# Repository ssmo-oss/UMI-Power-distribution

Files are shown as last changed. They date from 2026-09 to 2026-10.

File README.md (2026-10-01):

# UMI Power Distribution

Three separate boards distribute a 12 V supply to the UMI system. **D6 is the current prototype revision. It has not been physically qualified or approved for production.**

## Latest mechanical candidate — D8-2L MAIN

The owner supplied [10052938_AA-UMI POWER PCB OUTLINE V3.dxf](design/D8-2L/source/10052938_AA-UMI%20POWER%20PCB%20OUTLINE%20V3.dxf) for MAIN only on 2026-10-01. [D8-2L](design/D8-2L/README.md) and [D8-2L-FASTON](design/D8-2L-FASTON/README.md) apply the updated contour and six 3.5 mm mounting-hole centers. The FASTON assembly was corrected on 2026-10-01: the right-angle tabs now point toward board top, their through-board pins align with the two-hole footprints, and the reverse-side fuseholder envelopes align with their pad patterns. The FASTON board passes DRC with zero violations, unconnected items, and schematic-parity issues. Its [STEP assembly](design/D8-2L-FASTON/MAIN_POWER/MAIN_POWER_D8_FASTON.step) and [3D preview](design/D8-2L-FASTON/MAIN_POWER/review/MAIN_POWER_D8_FASTON_3D.png) are current. The terminal and fuseholder solids are dimension-based simplified CAD envelopes, not exact vendor models; TE lists the 63951-4 as a 6.35 mm-wide right-angle tab with 1.4 mm PCB holes and an 8.89 mm profile height ([TE product page](https://www.te.com/en/product-63951-4.html)). Raw copper is excluded and solder-mask surfaces are included in the STEP. The direct-solder variant was left untouched. TE recommends 1.57 mm PCB thickness, while the candidate remains 1.2 mm pending confirmation. D7-2L remains unchanged.

**D8 is not ready for manufacturing.** KiCad 10.0.6 DRC reports 0 violations, 0 unconnected items, and 0 schematic-parity issues for both MAIN variants. Complete electrical, thermal, and enclosure review before release. See the saved [D8 DRC report](design/D8-2L/MAIN_POWER/verification/D8_DRC_DIRECT_SOLDER.json), [board preview](design/D8-2L/MAIN_POWER/review/MAIN_POWER_D8.svg), and [visual STEP assembly](design/D8-2L/MAIN_POWER/MAIN_POWER_D8.step). The direct-solder STEP includes the board and all 10 component envelopes. The FASTON variant includes the board and all 11 component envelopes. Input leads and mating cables are omitted.

| Board | Function | PCB size / thickness | Planned assembly |
|---|---|---|---|
| MAIN_POWER | Fused 12 V distribution | 68 Ãƒâ€” 100.264 mm / 1.2 mm | User fits all 11 through-hole parts |
| POE_POWER | 12 V to nominal 53.5 V, 1.31 A switch supply | 106 Ãƒâ€” 100 mm / 1.2 mm | JLC SMT, user fits 3 through-hole parts |
| USB_POWER | Two charge-only USB-A ports, 3 A electrical design target each | 80 Ãƒâ€” 50 mm / 1.6 mm | JLC SMT, user fits 3 through-hole parts |

All boards use four copper layers, 2 oz outer / 1 oz inner. Planned batch: **10 of each board**. Enclosure ambient limit: **40 Ã‚Â°C**.

## Mechanical update required

On 2026-09-28, the project owner confirmed that the D6 board outlines were out of date. D8-2L now applies the supplied replacement outline to MAIN only. D6 manufacturing files and STEP models remain historical and on hold; POE and USB replacement mechanics are still not supplied. Do not treat D8 as released for manufacture.

## Latest MAIN option: D7-2L

[Two-layer MAIN prototype](design/D7-2L/README.md) preserves the user layout and uses 2 oz copper on each side at 1.2 mm thickness. Native ERC/DRC/parity checks pass. The four-layer D6L1 option remains preserved. Full shared-path voltage-drop/thermal qualification and mechanical confirmation remain pending. PoE and USB are unchanged. [Download D7-2L](packages/UMI_MAIN_POWER_D7_2L_PROTOTYPE.zip).

## Preserved four-layer MAIN layout: D6L1

The user rearranged MAIN components on 2026-09-29. [D6L1](design/D6L1/README.md) restores the branch connections and fills while preserving those placements and graphics. Native DRC/parity: zero violations and zero unconnected items. [Open the current MAIN project](design/D6L1/MAIN_POWER/MAIN_POWER.kicad_pro). Older MAIN Gerbers and STEP files are now stale for this layout. Manufacturing remains on hold.

## MAIN schematic redraw: D6S1

The MAIN schematic was redrawn on 2026-09-29 with explicit branch wiring. [Open the D6S1 project](design/D6S1/MAIN_POWER/MAIN_POWER.kicad_pro), [view the schematic PDF](design/D6S1/MAIN_POWER/review/MAIN_POWER_schematic.pdf), or read the [revision notes](design/D6S1/README.md). The physical MAIN PCB is unchanged from D6; PoE and USB remain D6. The outline hold still applies. For another computer or agent, read [START_HERE.md](START_HERE.md).

## Start here

- [D6 design and manufacturing overview](design/D6/README.md)
- KiCad 10 projects: [MAIN](design/D6/MAIN_POWER/MAIN_POWER.kicad_pro), [POE](design/D6/POE_POWER/POE_POWER.kicad_pro), [USB](design/D6/USB_POWER/USB_POWER.kicad_pro). Each project includes its PCB, schematic and local libraries.
- [Complete D6 prototype package](packages/UMI_THREE_BOARD_DESIGN_D6_PROTOTYPE.zip)
- [Combined component sourcing spreadsheet](design/D6/UMI_COMPONENT_SOURCING.xlsx) and [CSV](design/D6/UMI_COMPONENT_SOURCING.csv): one list for SMT, manual parts and harness parts.
- [Layout review](design/D6/LAYOUT_REVIEW.html): download/clone and open locally to view linked fabrication and assembly drawings.
- [Simplified STEP models](mechanical/D6/README.md) and [STEP ZIP](packages/UMI_D6_STEP.zip).
- [Engineering calculations and bring-up procedure](design/D6/ENGINEERING_AND_TEST_NOTES.md), [fabrication requirements](design/D6/FABRICATION_NOTES.md), [manual assembly](design/D6/MANUAL_ASSEMBLY.md).
- [Open items and project decisions](docs/PROJECT_HANDOFF.md).

## Configuration

The PoE switch and SENSING GMSL board are **alternative configurations; never connect both loads** under this power budget. No hardware interlock enforces this. The larger configuration is approximately 174 W / 14.5 A at 12 V under the documented assumptions; retain the 20 A input-path design/test margin.

MAIN J1 is the 12 V input. MAIN J2/J3/J4/J5/J6 feed Jetson/GMSL/fan/USB/POE respectively. All two-pin 12 V headers use pin 1 positive, pin 2 ground. POE J6 supplies 53.5 V: pin 1 positive, pin 2 unused, pin 3 ground. Consult the project pin schedules before making cables.

## Verification and limitations

The supplied D6 records report zero KiCad DRC/ERC violations, zero unconnected items and zero schematic-parity issues. Gerber/drill/placement checks and source hashes are included in each board's verification folder. These are file checks, not hardware measurements. [TEST_RECORD.csv](design/D6/TEST_RECORD.csv) records physical tests as unperformed.

Supplier acceptance of copper thickness, selective filled/capped vias and the PoE inductor fixture is pending. Stock observations are historical snapshots, not reservations. The output fuse is obsolete and its observed stock only supports a batch sourcing plan. No order or payment has been placed.

STEP files preserve board outlines and holes and add simplified component proxies. Component heights are estimates: do not use them for final enclosure-clearance signoff. Missing KiCad 3D bodies do not remove a component from the assembly BOM; check the SMT BOM/CPL and separately fitted parts.

## Repository contents

`design/D6/` is the editable current design and manufacturing package. `mechanical/D6/` contains six STEP models and their verification/assumptions. `packages/` contains the original current delivery ZIPs. `archive/` contains superseded snapshots, including the original revC input. `docs/historical-reviews/` preserves prior engineering reviews; they can contain findings later resolved by D6. `tools/legacy/` contains development scripts, with execution caveats in its README.

Transferred on 2026-09-28. See [transfer record](docs/TRANSFER_RECORD.md) and [SHA256 manifest](TRANSFER_SHA256SUMS.txt). No license has been selected; this import does not assign new licensing terms to project files or third-party library assets.

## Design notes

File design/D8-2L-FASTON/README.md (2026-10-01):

# D8 MAIN — FASTON 250 input alternative

This separate MAIN-board variant is based on D8-2L. It uses the owner-supplied V3 outline and keeps the fuse and connector arrangement, routing, copper zones, and output connectors. J1 is changed to two TE Connectivity 63951-4 FASTON 250 PCB tabs, each with two plated mounting holes (four holes total) on the tab axis, with both blade axes pointing toward the board's top edge in the top view. The flat solder-pad version remains in `design/D8-2L/MAIN_POWER/`.

The FASTON pair is centered on the board's 139.6 mm X centerline. Its footprint courtyard sits 2.5 mm in from the straight lower board edge.

## Input connector

- PCB terminals: TE Connectivity **63951-4**, quantity 2; FASTON 250, 6.35 × 0.8 mm tabs. Each tab uses two 1.4 mm plated holes at 5.08 mm pitch.
- Mating 10 AWG receptacle option: TE Connectivity **62998-2**, quantity 2, for 10–8 AWG wire. The mating receptacles and wires are off-board, not fitted to the PCB.
- TE lists 8.89 mm profile height from PCB for 63951-4, leaving 1.11 mm nominal margin under 10 mm. The same product page recommends 1.57 mm board thickness. This variant still uses 1.2 mm board thickness; confirm fit/retention with TE or update the stackup before ordering.
- The 10 mm clearance also needs checking with the selected female receptacles and wires installed. The TE 63951-4 summary does not state a current rating, so qualify the complete connection thermally at the intended maximum current. Terminals have no wire-insulation support; add harness strain relief.

## Files

- `MAIN_POWER/MAIN_POWER.kicad_pcb` — updated PCB; copper zones refilled.
- `MAIN_POWER/MAIN_POWER.kicad_sch` — J1 value, footprint, MPN and BOM status updated.
- `MAIN_POWER/UMI_D2.pretty/Input_FASTON_250_PAIR.kicad_mod` — pair footprint with four 1.4 mm plated holes (two per tab, 5.08 mm pitch) and top-view tab orientation shown on F.Fab.
- `MAIN_POWER/verification/D8_FASTON_DRC.json` — KiCad 10.0.6 check after V3 outline and zone refill: 0 rule violations, 0 unconnected items, and 0 schematic-parity warnings. The six DXF-derived 3.5 mm mounting holes have matching schematic records.
- `MAIN_POWER/review/MAIN_POWER_D8_FASTON.svg` — top-view preview.
- `MAIN_POWER/MAIN_POWER_D8_FASTON.step` — refreshed 2026-10-01; board, solder-mask surfaces, and all 11 modeled components (J1–J6 and F1–F5); raw tracks, pads, and zones are excluded.
- `MAIN_POWER/review/MAIN_POWER_D8_FASTON_3D.png` — 3D assembly preview showing the input blades extending toward the board top and the fuse-holder envelopes aligned over their backside pad patterns.

The STEP uses dimensioned envelope models for the TE 63951-4 terminal pair, the JST VH output headers, and the Littelfuse FLR fuse holders. They are simplified solid envelopes, not detailed vendor CAD. The FASTON pair uses a 6.35 × 0.8 mm blade, 8.89 mm profile height, four tails aligned to the four 1.4 mm holes, and a right-angle bend; the two blades point toward the board top, parallel to the fuse row. The B.Cu fuseholder envelopes are mirrored to match the pad patterns. TE recommends a 1.57 mm board; this candidate is still 1.2 mm. Confirm the terminal fit, 10 mm enclosure clearance, current capacity, and mating connector with exact vendor CAD before release. This remains a prototype layout candidate, not a manufacturing release.

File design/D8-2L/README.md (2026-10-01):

# MAIN D8-2L — mechanical-outline adaptation candidate

Created 2026-09-30 from the D7-2L two-layer MAIN board after the owner supplied the corrected mechanical DXF. The editable KiCad project is `MAIN_POWER/MAIN_POWER.kicad_pro`. The D7-2L source project remains unchanged.

## Mechanical input

Latest source: `source/10052938_AA-UMI POWER PCB OUTLINE V3.dxf` (SHA-256 `10ADAB7113C99765CFB8C23128E78733F5ECCF2D0ECE246013FCFE98C07AA364`). DXF `$INSUNITS` is millimetres. V3 has 32 unique contour segments, bounds 121.8 × 60.5 mm, and six 3.5 mm diameter mounting holes. Compared with V2_1 it moves the upper inner pair from DXF X=±19 mm to ±16 mm and revises the contour. V3 is applied to both D8 MAIN options without scaling; earlier outline files are retained for history.

The DXF contour origin was mapped to the existing MAIN project coordinates as `x = 139.6 mm + DXF X` and `y = 97.131981 mm − DXF Y`. This keeps the board in the D7 project coordinate area. The DXF is mechanical geometry, not a source of electrical or assembly instructions.

## Layout adaptation

D8 starts from the D7-2L electrical design, rotates the component layout to fit the landscape profile, replaces the old four mounting holes with the six DXF holes, and refills the two copper zones. After the owner adjusted placement, the five fuse centers were aligned on one row, the five output connector centers on another, and each fuse/connector pair was centered on the same vertical line. The five fuse-holder footprints are on B.Cu (underside); all other components stay on F.Cu (top). All board text is on F.SilkS, with the fuse ratings and connector names centered on their corresponding columns. F3/J4 was shifted 1.5 mm left to clear mounting hole H2. The MAIN copper was rerouted: five fused outputs, a shared 12 V input bus routed around the DXF notch and mounting holes, and ground zones. On 2026-09-30, J1 was changed from the oversized Phoenix screw terminal to two 8 × 8 mm flat top-copper solder pads, labelled +12V and GND, sized for 10 AWG leads. Sixteen 1.0/0.5 mm ground stitching vias tie the GND pad to the B.Cu return plane. Lay the leads along the board and strain-relieve them to the enclosure or harness; do not use the solder joints as cable support. J1 has no connector part number. The circuit and other components are unchanged. `tools/create_d8_main.py` records the initial conversion from the original D7-2L board and DXF.

## Current validation and limits

KiCad 10.0.6 DRC with zone refill reports 0 violations, 0 unconnected items, and 0 schematic-parity issues. The board is an editable routing candidate, not released for manufacture. Electrical voltage-drop, thermal and enclosure validation remain outstanding; in particular, the 10 AWG input connection and copper path still need thermal qualification at the maximum intended current.

The top-view review is `MAIN_POWER/review/MAIN_POWER_D8.svg`; the underside view is `MAIN_POWER/review/MAIN_POWER_D8_bottom.svg`. The DRC data is `MAIN_POWER/verification/D8_DRC.json`.

## STEP assembly — 2026-10-01

`MAIN_POWER/MAIN_POWER_D8.step` includes the board, solder-mask surfaces, and all 10 modeled components (J2–J6 and F1–F5). J1 is the two flat input pads; input wires are not modeled. The JST VH and Littelfuse FLR bodies use project-local dimensioned envelope STEP models because those vendor models are absent from the installed KiCad model library. These simplified volumes preserve the specified connector/fuse identities and overall envelopes, but omit detail; use the STEP for arrangement and preliminary clearance review, then verify with vendor CAD before release. Raw tracks, pads, and zones are excluded from STEP export. Run `tools/export_d8_main_steps.ps1` to regenerate both D8 MAIN STEP assemblies.

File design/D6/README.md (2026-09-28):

# UMI D6 — sourcing and manufacturing corrections

D6 retains the three-board architecture and resolves the known part-sourcing and file-format issues that can be handled before fabrication. **Ready for prototype manufacturing review, not physically qualified for production.**

## Completed

- Replaced the preorder snubber resistor with stocked **Yageo RC2010JK-077R5L / C4169838**. Resistance, tolerance, power rating and footprint are unchanged. Its pulse/thermal behaviour still requires the same prototype measurement as the original part.
- Found exact loose-part sources for all thirteen manual component types. The Phoenix input connector no longer needs JLC preorder. The 80 V fuse has enough observed distributor stock for twenty pieces, including ten spares. It is obsolete; this is a batch solution, not guaranteed long-term availability.
- Defined the supply route: JLC assembles SMT; the user fits separately purchased connectors, holders, inserts and harness components. All remain on **one combined spreadsheet** with purchase links and quantities. Repeated manual MPNs are bought once; later duplicate rows show zero purchase quantity.
- Corrected MAIN/POE inner-layer stackup identities, widened five POE traces from 0.15 to 0.16 mm, enlarged MAIN's small visible labels, and encoded selective via filling/capping in the PCB sources and coordinate schedules.
- Refilled and re-exported all boards. Final KiCad DRC/ERC reports pass with zero reported violations, zero unconnected items and zero schematic-parity issues. Independent Gerber/drill/placement audits and source-hash checks are included.

## Files and order scope

Open **LAYOUT_REVIEW.html** for actual fabrication previews and schematic/assembly drawings. Order ten of each:

| Board | Outline | Thickness | Copper | Assembly |
|---|---|---|---|---|
| MAIN_POWER | 68 × 100.264 mm | 1.2 mm | 4 layers, 2 oz outer / 1 oz inner | Bare board, 11 manual parts |
| POE_POWER | 106 × 100 mm | 1.2 mm | Same | 53 SMT + 3 manual parts |
| USB_POWER | 80 × 50 mm | 1.6 mm | Same | 31 SMT + 3 manual parts |

Use the per-board Gerber ZIP, SMT BOM and normalized CPL. MAIN has no SMT operation. Read FABRICATION_NOTES.md: POE/USB need selective epoxy-filled, copper-capped vias; POE's 0.635 mm vias remain ordinary. Include the POE inductor assembly fixture. The source copper stackup is explicit; do not accept a silent change to 0.5 oz inner copper.

## Electrical configuration

MAIN J1 takes 12 V. J2 supplies Jetson, J3 GMSL, J4 fan, J5 USB J1 and J6 POE J1. All 12 V two-pin headers use pin 1 positive, pin 2 ground. POE J6 is the 53.5 V output: pin 1 positive, pin 2 empty, pin 3 ground.

Use **PoE or GMSL, never both**. There is no electronic interlock. The larger configuration is approximately **174 W / 14.5 A at 12 V**, using the documented allowances and assumed converter efficiency; retain 20 A input-path design/test margin. MAIN retains F1 Jetson 7.5 A, F2 GMSL 7.5 A, F3 fan 1 A, F4 USB 5 A and F5 PoE feed 10 A. POE retains F6 3 A / 80 V. F5 protects the interboard cable at its source. Jetson's 7.5 A is provisional protection, not expected draw; verify startup, temperature and wire protection before changing it.

## Remaining external steps

1. **Manufacturer acceptance and purchasing:** the exact copper/thickness/selective-fill combination and inductor fixture need an accepted quote. QUOTE_REQUEST.md is prepared but unsent. Approve supplier placement/polarity previews and final attrition quantities. C1 requires fourteen pieces including the reported four-piece attrition, against fifteen observed; L1 requires ten against seventeen observed. Inventory is not reserved. Other SMT allowances in the spreadsheet are conservative planning quantities where exact order-page arithmetic was unavailable.
2. **Physical prototype tests:** no assembled hardware was available to test. Thermal rise at 40 °C, stability, snubber pulses, eFuse fault transients, USB load steps and real-device compatibility cannot be established from DRC. TEST_RECORD.csv gives the pending measurements; ENGINEERING_AND_TEST_NOTES.md gives the procedure. All physical results are explicitly unperformed.
3. **Installation details:** final cable lengths, device-end plugs, weakest wire/pigtail ratings, input cable protection and the exact USB-powered device model remain to be confirmed before system integration. The interim interboard harness basis is AWG16, at most 1 m one-way; this is a documented assumption, not a measured installation.

No supplier message, order, reservation, payment or external design upload has been made. D5 is preserved. SHA256SUMS.txt identifies this package.

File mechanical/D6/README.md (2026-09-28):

# UMI D6 simplified STEP models

Six files: BARE and SIMPLIFIED for MAIN_POWER, POE_POWER and USB_POWER. Units are millimetres.

BARE files retain the native KiCad board outline, rounded corners, mounting and component holes. Small via holes are intentionally omitted. The native board-only export omits outer conductor/mask thickness; its Z dimension was scaled to the specified finished 1.2 mm MAIN/POE and 1.6 mm USB thickness. X/Y geometry is unchanged. No tracks, pads, copper zones or text are modelled.

SIMPLIFIED files add a rectangular body proxy for every board-mounted electrical component, including the through-hole parts intended for manual assembly. They also show simple fuse-insert proxies. Component X/Y outlines derive from the saved footprint fabrication graphics and placements. Heights are approximate visual allowances, not verified manufacturer maximum dimensions. Leads, solder joints, connector internals, mating plugs, cables and standoffs are omitted. These models are useful for arrangement and visualisation, but NOT final enclosure-clearance signoff. Consult COMPONENT_PROXY_DIMENSIONS.json for each assumption.

Origin: each board's Gerber/drill origin. X points right, Y points upward when viewed from the component side, Z points upward. Bare PCB bottom is Z=0; component bodies start at the finished PCB top. All boards are exported separately; their relative installation positions are not defined.

Every file was reimported with Open CASCADE and checked for valid solid geometry and expected solid count. Bare PCB dimensions were checked against the design. MAIN: 68 × 100.263962 × 1.2 mm; POE: 106 × 100 × 1.2 mm; USB: 80 × 50 × 1.6 mm. The original KiCad/manufacturing files were not modified.

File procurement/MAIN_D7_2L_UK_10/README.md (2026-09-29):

# MAIN D7-2L purchasing and fabrication package

Prepared 29 September 2026 for **10 MAIN boards only**, retaining the latest layout and 3 mm FAN branch tracks. The PCB and schematic were not modified for this task.

## What to use

- `MAIN_D7_2L_UK_PARTS_10.xlsx`: one combined purchasing list with exact part numbers, quantities, spares, observed GBP prices, stock and source links.
- `DIGIKEY_BASKET_IMPORT.csv`: nine order lines for DigiKey UK. Map the three columns to Part Number, Quantity and Customer Reference in the basket file importer.
- `DIGIKEY_BULK_ADD.txt`: same nine lines without headers for the basket's Bulk Add text box.
- `JLCPCB_MAIN_D7_2L_GERBERS.zip`: fabrication upload containing seven Gerbers, two drill files and the Gerber job file. Use the separate order settings text file.
- `MAIN_BOARD_BOM_MANUAL_ASSEMBLY.csv` and `MAIN_WIRING_PIN_SCHEDULE.csv`: reference assembly and wiring information. These are not a JLCPCB SMT assembly submission.

## Purchase quantities and cost

The list supplies all 11 soldered components per board, five removable fuse inserts and five MAIN-end two-pin mating housings with ten contacts per board. Quantities include a 20% spares allowance, rounded to supplier order multiples. Contacts are **200 individual contacts (two strips of 100)**, not 200 packs. Required without spares: 10 input blocks, 50 holders, 50 PCB headers, 20 x 7.5 A fuses, 10 each of 1 A / 5 A / 10 A fuses, 50 housings and 100 contacts.

Observed parts estimate: **GBP 259.48 excluding VAT, delivery and PCB fabrication**. Prices come from displayed DigiKey UK tiers; web search pages may be cached. Holder and 100-contact-strip availability were also checked in the browser. Stock is not reserved and all prices need refresh at checkout. Changing spreadsheet quantities recalculates quantities and totals using the recorded unit prices; it does not retrieve new tier prices. CSV/TXT are the fixed ten-board snapshot and do not auto-update with spreadsheet edits.

Both online carts were subsequently created successfully. See [ONLINE_CART_STATUS.md](ONLINE_CART_STATUS.md) for basket links, live prices and saved cart references. No payment or order submission occurred.

## Assembly and harness details

- J1 Phoenix 1709681 is a fixed screw-clamp PCB terminal block. The PSU wires enter it directly; it does not take a mating plug.
- J2–J6 use JST B2P-VH(LF)(SN), cataloged by DigiKey as B2P-VH. Their matching cable housings are natural-colour VHR-2N with SVH-41T-P1.1 female contacts. Natural housing colour replaces the earlier black VHR-2N-BK selection; the mating family and circuit are unchanged.
- Contacts accept 16–20 AWG wire; use the specified contact/wire tooling and validate finished crimps. Do not crimp a thinner fan pigtail into an oversized contact. Adapt the harness with appropriate terminals/splices once actual wire gauges are known.
- Pin 1 on each output is its fused +12 V; pin 2 is ground. Verify physical pin numbering before terminating each cable.
- Fuse mapping: F1 Jetson 7.5 A; F2 GMSL 7.5 A; F3 fan 1 A; F4 USB-board feed 5 A; F5 PoE-board 12 V feed 10 A. These are the existing design values, not newly proven load ratings. All inserts in this MAIN list are 32 VDC-rated ATO fuses. Do not use them on the 53.5 V PoE output.
- PoE and GMSL are alternative system configurations, never simultaneous loads. Both physical branches are populated in this purchasing list.
- Wire lengths, device-end plugs, PSU-end terminations, enclosure mounting hardware and crimp tooling are not included because their installation details are unspecified. The mating connector list covers the MAIN end only.

JST family reference: https://www.jst-mfg.com/product/pdf/eng/eVH.pdf

## Fabrication status

Order settings: 10 bare FR-4 boards, two copper layers, 2 oz each side, 1.2 mm finished thickness, ENIG, green solder mask, white legend. No stencil or assembly service is needed for this all-through-hole MAIN design. Exact nominal outline is 68 x 100.263962 mm.

The saved native DRC report has zero violations, zero unconnected items and zero schematic-parity findings under the project's configured checks; saved ERC has zero violations. The package audit verifies the PCB/schematic hashes against the saved two-layer audit and verifies each ZIP member against the export directory. No claim of live JLCPCB DFM approval is made.

**Existing release limits remain:** final mechanical outline/holes are unconfirmed and full-board thermal/voltage-drop testing at 40 C enclosure ambient is outstanding. This package is suitable for a fabrication quote and prototype review; it is not a production-qualified release. Do not treat clean DRC as an ampacity or mechanical-fit certificate.

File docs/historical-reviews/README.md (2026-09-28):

# Historical review notes

These notes preserve engineering rationale and earlier findings. Dates/revision labels matter: some issues were subsequently fixed. Current conclusions and outstanding work are in `../../design/D6/README.md`, the D6 verification records and `../PROJECT_HANDOFF.md`. These review snapshots do not establish current inventory or physical qualification.

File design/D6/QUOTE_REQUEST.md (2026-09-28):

# Prepared engineering quotation request — not sent

Please quote fabrication of ten each of UMI D6 MAIN_POWER, POE_POWER and USB_POWER, with top-side SMT assembly on POE and USB only. MAIN is bare-board supply; all connectors, fuse holders/inserts and cable-side parts are excluded from SMT assembly and will be user-fitted.

MAIN: 68 × 100.263962 mm, four layers, 1.2 mm finished thickness. POE: 106 × 100 mm, four layers, 1.2 mm. USB: 80 × 50 mm, four layers, 1.6 mm. All require 2 oz outer / 1 oz inner copper, ENIG, green soldermask, white silkscreen and FR-4 Tg150 or better. Please confirm the exact stackups and tolerances without changing outline, mounting holes or copper weights.

POE and USB require selective epoxy resin fill with copper capping of the vias identified in their manufacturing/VIA_TREATMENT.csv files. POE 0.254/0.35/0.40 mm vias and USB 0.25/0.30 mm vias are included; POE 0.635 mm ordinary vias and all component/mounting holes must remain open. Please confirm capability and pricing for this selective process at the specified copper/thickness combinations.

POE has 53 top SMT placements, USB 31. Use the normalized *_CPL_JLC.csv and matching BOM_JLC_DRAFT.csv. Please verify rotation/pin 1 in the placement preview, paste treatment over filled/capped pads, and support fixture requirements for Coilcraft SER2915H-103KL / C19276042. Include the required fixture in the quote. Add removable handling rails if needed rather than changing the board outlines.

Please confirm available quantities and assembly attrition for all SMT parts. Particular constraints: POE C1 C23481145, ten installed plus four catalogue attrition; POE L1 C19276042, ten installed; POE R1 C4169838, ten installed with supplier-confirmed minimum/attrition. The consolidated sourcing list contains dated observations, not reservations. State lead time, freight, any engineering exceptions and whether all parts can be supplied before committing to production.

Please return the complete engineering acceptance and quotation for review before any fabrication, assembly or purchase is authorised.

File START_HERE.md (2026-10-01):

LATEST MAIN MECHANICAL CANDIDATE (2026-10-01): both `design/D8-2L/MAIN_POWER/` (flat solder-pad input) and `design/D8-2L-FASTON/MAIN_POWER/` (two TE 63951-4 input tabs) use the owner-supplied V3 outline. Both pass KiCad 10.0.6 DRC with 0 violations, 0 unconnected items, and 0 schematic-parity issues. Matching STEP assemblies are saved in each MAIN_POWER folder. They include board/copper and mounted component volumes, with simplified proxies for connector and fuse-holder geometry. FASTON uses a dimension-based tab proxy rather than the gated manufacturer model. Confirm the terminal fit, 10 mm enclosure clearance, current capacity, and mating connector with exact vendor CAD; TE recommends a 1.57 mm board while these candidates remain 1.2 mm. Read both D8 README files before further work. The V3 update applies to MAIN only; POE and USB remain at their prior D6 mechanical revisions. D7-2L remains unchanged as the electrical baseline.

## Cart update — 29 September 2026

Ten-board MAIN D7-2L carts are now saved at JLCPCB and DigiKey. No payment/order submission. See [cart status](procurement/MAIN_D7_2L_UK_10/ONLINE_CART_STATUS.md). Earlier basket-failure notes are superseded. Mechanical and thermal holds remain.

# Resume on another computer

LATEST PROCUREMENT (2026-09-29): `procurement/MAIN_D7_2L_UK_10/` contains the MAIN-only ten-board UK purchasing list, DigiKey basket import files, matching two-layer JLCPCB Gerber ZIP and order settings. It includes the latest 3 mm FAN tracks. No online basket/order was completed; DigiKey Bulk Add returned a server error. The existing mechanical and physical-validation holds remain. For MAIN, use `design/D7-2L/MAIN_POWER/MAIN_POWER.kicad_pro`; the older D6 MAIN instructions below are historical.

NEWEST OPTION: MAIN D7-2L is the requested two-layer prototype in design/D7-2L/MAIN_POWER, preserving the D6L1 component layout. Read its README and the latest handoff entry. D6L1 remains the four-layer fallback. Neither is production-qualified.

LATEST UPDATE: MAIN layout is now D6L1 (design/D6L1/MAIN_POWER), reconnected after user placement edits; its schematic is the D6S1 redraw. Read the latest entry in docs/PROJECT_HANDOFF.md. D6/D6S1 MAIN manufacturing and STEP outputs are stale for this layout. The older state described below is superseded for MAIN PCB selection.

Repository: https://github.com/ssmo-oss/UMI-Power-distribution

Download or clone this repository on the new computer. In a desktop agent with local folder access, open the repository folder as the project. For a cloud/chat agent, connect the repository if available, or upload the downloaded files; a URL alone does not guarantee the agent can edit the repository. Authentication and KiCad installation belong to the new machine and are not included in this repository. See [OpenAI project guidance](https://learn.chatgpt.com/docs/projects).

Read README.md, docs/PROJECT_HANDOFF.md, design/D6S1/README.md and design/D6/ENGINEERING_AND_TEST_NOTES.md. The latest MAIN schematic is D6S1; its PCB is still D6. PoE and USB remain D6. The corrected outline is applied to MAIN in D8-2L. POE/USB mechanics and all manufacturing outputs remain on hold. Past checks passed but hardware tests are unperformed.

Paste this into the next agent:

> Continue the UMI power-distribution project from https://github.com/ssmo-oss/UMI-Power-distribution. Read START_HERE.md, README.md, docs/PROJECT_HANDOFF.md and design/D6S1/README.md before editing. Confirm which files you can actually access. The MAIN schematic redraw is D6S1, while its copper and the other two boards remain D6. The owner supplied a revised MAIN-only outline, now applied in design/D8-2L/MAIN_POWER. POE/USB replacement mechanics remain pending. Continue from D8 for MAIN, validate connectivity and clearance, and regenerate matching manufacturing and mechanical files only after remaining review items and mechanics are resolved. Keep one combined sourcing list, preserve the three-board architecture and PoE-or-GMSL configuration rule. Record changes and remaining issues in the repository so work can continue from any computer. Do not submit orders or claim physical qualification.

For KiCad editing, open design/D6S1/MAIN_POWER/MAIN_POWER.kicad_pro (MAIN) or the corresponding project under design/D6 for POE and USB. Local symbol and footprint libraries are included. The old development scripts under tools/legacy contain machine-specific paths and are not a turnkey build pipeline. Earlier KiCad bundled Python/CLI invocations caused application-error dialogs; do not blindly rerun those scripts. Verify the available tools on the new computer first.

This is a durable project handoff, not a transfer of the old chat transcript, open editor windows, credentials or installed plugins. Update docs/PROJECT_HANDOFF.md and push completed changes before switching computers again.

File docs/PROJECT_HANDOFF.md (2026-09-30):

## Cart update — 29 September 2026

Ten-board MAIN D7-2L carts are now saved at JLCPCB and DigiKey. No payment/order submission. See [cart status](../procurement/MAIN_D7_2L_UK_10/ONLINE_CART_STATUS.md). Earlier basket-failure notes are superseded. Mechanical and thermal holds remain.

# Project handoff â€” 2026-09-28

## Latest procurement package — 2026-09-29

User explicitly scoped this purchase to MAIN D7-2L only, ten boards. See `procurement/MAIN_D7_2L_UK_10/README.md`. One combined XLSX includes all MAIN PCB parts, fuse inserts, MAIN-end mating housings and contacts, with 20% spares and contacts rounded to two 100-contact strips. Nine DigiKey UK import lines total an observed GBP 259.48 ex VAT/delivery; stock and price are not reserved. Natural VHR-2N housing is used instead of the earlier black VHR-2N-BK. PCB part selection and geometry are unchanged.

DigiKey online Bulk Add returned an Error/POST dialog; an individual-product retry did not show a successful addition. No live basket was completed, no order submitted. CSV and text import files allow reconstruction. Device-end connectors, cable lengths, enclosure hardware and tooling remain installation-dependent and are excluded.

JLCPCB upload ZIP is byte-identical to the latest D7-2L manufacturing export: 2 layers, 2 oz per side, 1.2 mm, ENIG; ten bare PCBs, manual assembly, no stencil. Source hashes match saved clean ERC/DRC/two-layer audit. The mechanical outline is still unconfirmed and physical thermal/voltage-drop testing at 40 C is pending. This procurement step does not release the board for production. It does not change PoE or USB sourcing or fabrication files.

## Accepted requirements and decisions

- Original two-board proposal evolved into three boards for independent replacement/modification of the PoE supply. D6 is the latest delivered revision.
- Board expansion was subsequently authorized; earlier size requests (including the initial 30 Ã— 60 mm USB target) are superseded by the delivered dimensions. Use actual Edge.Cuts and mounting-hole geometry for mechanics.
- Ten of each board; user fits through-hole connectors/holders and fuse inserts. JLC is the intended SMT assembler. Keep all parts on one combined sourcing list.
- External supply basis: Mean Well RSP-320-12, nominal 12 V / 26.7 A. Mains wiring is outside these PCBs.
- Maximum enclosure ambient 40 Â°C. PoE and GMSL loads are mutually exclusive; budget the larger configuration.
- All six fuses retained: MAIN F1 Jetson 7.5 A, F2 GMSL 7.5 A, F3 fan 1 A, F4 USB 5 A, F5 PoE feed 10 A; POE F6 output 3 A / 80 V DC. F5 protects the interboard cable at its source, so no duplicate local PoE input fuse is fitted.
- Jetson 7.5 A is a provisional protection rating, not its normal consumption. Validate startup, ambient derating and the weakest harness section before reducing it. USB port current-limit devices protect each output independently; a charging-only socket still requires overload protection.

## Completed evidence

Use design/D6/README.md and verification/FINAL_AUDIT.json for final D6 results. Schematics, local symbols/footprints, boards, Gerbers, drills, SMT BOMs, normalized placement files, manual BOMs, fabrication drawings, placement reviews and test records are included. D6 corrected the snubber resistor sourcing, inner-layer identities, five narrow PoE traces, selected text sizes and via-treatment metadata. The manufacturing source files are preserved without edits in this transfer.

Six simplified STEP files were generated and reimported through Open CASCADE. Their geometry reports pass; component heights remain approximate. No manufacturing change resulted from STEP generation.

## Remaining work before manufacture and system release

**First priority â€” corrected board outlines:** On 2026-09-28 the owner confirmed that the existing outlines are out of date. Correct replacement geometry is pending; no outline changes have been guessed or applied. Obtain the authoritative mechanical files/dimensions for the affected boards, including mounting holes and connector constraints. Rework layout/routing as needed, validate clearances and regenerate manufacturing and STEP outputs as a new revision. Current D6 files are historical design evidence, not approved final mechanics.

1. Obtain supplier acceptance of the explicit 4-layer copper/thickness combinations, selective epoxy fill/copper cap treatment and heavy-inductor fixture. QUOTE_REQUEST.md is prepared but has not been sent to JLC. Review placement/polarity previews and exact assembly attrition before purchasing.
2. Recheck and reserve stock at ordering time. Prior observations include tight C1 and L1 stock and the obsolete Littelfuse 166.7000.4302 output fuse; these are not live stock guarantees.
3. Confirm the exact Ethernet switch model/input-voltage tolerance and USB-powered device model. The supplied switch requirement was 53.5 V / 1.31 A; that alone does not verify maximum input tolerance. USB-A outputs do not provide USB PD or data; device charging compatibility remains untested.
4. Finalize cable lengths, device-end plugs, wire/pigtail ratings and upstream input-cable protection. AWG16 and at most 1 m one-way are provisional interboard assumptions, not confirmed installation measurements.
5. Perform the test plan: polarity, unloaded startup, load steps, regulation/ripple, boost ringing/snubber, eFuse and per-port faults, fuse behavior, thermal rise at 40 Â°C, real-device boot/charging and enclosure EMC/ESD as applicable. No physical results have been claimed.
6. Replace estimated STEP bodies with verified mechanical envelopes before final enclosure signoff; include mating plugs and cable bends.

## Tooling notes

Earlier KiCad bundled Python and CLI invocations produced application-crash dialogs. Later native checks used an isolated wrapper and API-based workflows. Historical scripts contain machine-specific paths and some mutate designs. Do not execute the legacy directory as an automated pipeline. The saved D6 projects and validated outputs are the authoritative handoff.

The original knowledge-base pointer is https://sklvc.atlassian.net/wiki/spaces/LMP/pages/2171306022/UMI+Pack (access may require authentication). This transfer does not publish a dump of the private knowledge base, account credentials or browser sessions. Public manufacturer references are retained in the engineering documents.

The user's previous permission question about sending files to JLC remains unanswered. This GitHub transfer is explicitly authorized; it does not constitute permission to place orders, make payments or contact JLC.

## Latest update — 2026-09-29

MAIN schematic presentation is now D6S1 in design/D6S1/MAIN_POWER. It uses visible supply/return rails and fused branches instead of disconnected-looking blocks. All 22 electrical pin/net assignments match D6; ERC and DRC/parity checks pass. The physical MAIN PCB is byte-identical to D6; PoE and USB remain D6. Corrected mechanical outlines are still pending: the user said on September 28 that they did not have the DXF yet. Do not infer that a replacement arrived merely because the planned day has passed.

## MAIN user-layout repair — D6L1, 2026-09-29

Use design/D6L1/MAIN_POWER for the latest MAIN PCB and accompanying D6S1 schematic. The user rearranged components in KiCad; five branches were rerouted and four planes refilled without changing any footprint or board graphics. Final DRC/parity reports zero violations and zero unconnected items. D6 and D6S1 remain historical copies. MAIN Gerbers, STEP files and position-based documentation from those revisions are stale and need regeneration after mechanical confirmation. PoE and USB remain D6. User-open source files were preserved; continue from the delivered D6L1 copy.

MAIN D6L1 text update: all printed board notes are now on F.SilkS; six former B.SilkS notes were unmirrored and placed below the outputs. Copper and component placement unchanged; DRC/parity remains clean.

## Two-layer MAIN option — D7-2L

The user requested a two-layer MAIN while keeping the layout. design/D7-2L/MAIN_POWER is that candidate: same placement, holes, outline and dual-outer branch tracks; 2 oz F.Cu and B.Cu, 1.2 mm finished thickness. Two refilled solid-connected planes, no vias. DRC/ERC/parity pass; two-layer Gerber/drill files are included. D6L1 four-layer version is preserved. Local branch resistance estimates are documented, but complete shared-plane/contact losses and 20 A thermal performance are not qualified. Test at 40 C and confirm mechanics before manufacture. Parts unchanged; use the existing combined sourcing list. PoE/USB remain D6 four-layer.

D7-2L FAN branch update: user requested matching connection size. The six 1 mm FAN branch segments were widened to 3 mm on both outer layers; 2 mm terminal links and 1 A fuse remain. There are no vias on MAIN. Placement unchanged; fills, Gerbers and preview updated; DRC/parity passes.

## MAIN outline adaptation — D8-2L, 2026-09-30

The owner supplied `10052907_AA-UMI POWER PCB OUTLINE V2.dxf` and confirmed the change is for MAIN only. `design/D8-2L/` preserves D7-2L and contains the first outline adaptation, source DXF, conversion script, review SVG and KiCad 10.0.6 DRC report. The DXF is in millimetres and defines one 121.8 × 60.5 mm contour and six 3.5 mm holes. Initial D8 rotates the existing placement/routes to the new landscape profile and refills both copper zones.

The current D8 MAIN layout is saved in `design/D8-2L/MAIN_POWER`. Fuse centers F1–F5 share one row, output connector centers J2–J6 another, and each pair is centered on the same vertical line. Fuse holders are on B.Cu; other components and all board text are on the top side. F3/J4 moved 1.5 mm left to increase clearance from H2. All MAIN copper was rebuilt; KiCad 10.0.6 zone-refilled DRC reports 0 unconnected items and no track-to-hole or copper-edge clearance violations. Fourteen schematic-parity warnings remain for the six mechanical holes and footprint fields. No D8 Gerbers, drill package or BOM/CPL are generated. Keep manufacturing on hold; D7-2L is preserved as the electrical baseline. The supplied drawing describes mechanical geometry only and does not change electrical requirements.

## MAIN outline revision V2_1 — 2026-09-30

The owner supplied `10052907_AA-UMI POWER PCB OUTLINE V2_1.dxf` for MAIN. It preserves the V2 outer profile (121.8 × 60.5 mm, 30 line/arc segments) and shifts the six 3.5 mm mounting holes by 1.33–1.41 mm. The six NPTH footprints in D8-2L MAIN were updated to the revised centers. KiCad 10.0.6 zone-refilled DRC now reports 0 violations and 0 unconnected items; 14 schematic-parity warnings remain. See `design/D8-2L/README.md`; D7-2L remains unchanged.

## D8 MAIN STEP assembly — 2026-09-30

`design/D8-2L/MAIN_POWER/MAIN_POWER_D8.step` contains the board and 10 mounted component model proxies: JST J2–J6 and fuse holders F1–F5. J1 is now flat +12V/GND solder pads sized for 10 AWG leads; its tall terminal proxy was removed from STEP, and wires are omitted. The other models use scaled KiCad STEP library substitutes and are not vendor-exact. The STEP text was updated to remove J1 and checked for dangling entity references; it was not reimported for solid validation. Use for arrangement review only, and replace/verify model proxies before enclosure signoff.

## D8 J1 low-profile input — 2026-09-30

The owner confirmed only 10 mm of vertical clearance for the 12 V input. J1’s Phoenix 1709681 screw terminal is too tall, and the earlier 5.08 mm Phoenix model was only a visual placeholder. Molex’s 7.62 mm right-angle screw-terminal header 39730 is rated 10 A and is not suitable for the input; Phoenix’s 32 A FRONT 4 family is 29.4 mm high. The owner chose direct solder if a screw terminal cannot fit. J1 in D8 is now a pair of 8 × 8 mm flat copper pads on F.Cu for +12V and GND, labeled on silkscreen, with 16 ground stitching vias to B.Cu. Use 10 AWG input leads laid flat along the board and independently strain-relieved. No connector MPN applies. Thermal capacity, soldering process and cable strain relief require validation at the intended maximum current before release. DRC: 0 violations, 0 unconnected; schematic parity: 14 remaining warnings.

## D8 FASTON 250 input alternative — 2026-09-30

A separate MAIN variant is saved in `design/D8-2L-FASTON/`. J1 uses two TE 63951-4 FASTON 250 PCB tabs, arranged side by side with two 1.4 mm mounting holes per tab (four holes total, 5.08 mm pitch) and their top-view axes pointing toward the board top; TE 62998-2 is an off-board 10–8 AWG mating receptacle option. KiCad 10.0.6 DRC reports 0 violations and 0 unconnected items; 14 schematic-parity warnings remain for mechanical hole records. The board is 1.2 mm thick while TE recommends 1.57 mm. TE product data lists 8.89 mm terminal profile and a 1.4 mm hole, but the complete installed connector/wire envelope and current path still need qualification. No new STEP model is included yet. The flat solder-pad D8-2L candidate remains available separately.

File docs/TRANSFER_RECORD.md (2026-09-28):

# Transfer record

Date: 2026-09-28. Destination: https://github.com/ssmo-oss/UMI-Power-distribution

The destination was an empty repository. The current delivered D6 design package and STEP models were copied from the user's KiCad directory; existing source files were not modified. 272 entries in the original D6 SHA256SUMS.txt matched the transferred files. All included ZIP archives passed CRC validation. Machine-local KiCad .kicad_prl preference files were omitted from the editable tree; original delivery ZIPs remain byte-for-byte copies.

Earlier delivered snapshots and the user-supplied revC ZIP are in archive/. Relevant engineering scripts and review notes were retained for provenance, with caveats about obsolete paths and untested reruns. Installed toolchains, dependency caches, browser/account state, temporary lock files and downloaded webpage caches were excluded.

The root TRANSFER_SHA256SUMS.txt covers all transferred files except itself and Git metadata. Historical D6 statements that no external upload occurred describe the pre-transfer state; the GitHub upload is the action recorded here. No new electrical validation, hardware testing, supplier submission, stock reservation or ordering occurred during this transfer.

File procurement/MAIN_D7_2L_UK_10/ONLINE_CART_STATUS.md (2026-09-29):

# Online carts prepared — 29 September 2026

Scope: 10 MAIN D7-2L boards only. Both carts are saved; no checkout, payment or manufacturing order was submitted.

- DigiKey UK share-copy basket: https://www.digikey.co.uk/short/p3h4dchb
- DigiKey Web ID: 377258663. Nine lines, all showing Immediate availability at verification. Subtotal GBP 259.31 before VAT/shipping. Includes fuses, MAIN-end mating housings/contacts and spares.
- JLCPCB cart: https://cart.jlcpcb.com/shopcart/cart/
- JLC item: JLCPCB_MAIN_D7_2L_GERBERS_Y51; prototype reference Y51-10324919A; quantity 10; merchandise USD 59.55. Cart belongs to the signed-in browser account.
- JLC fabrication: FR4 TG135, two layers, 2 oz copper, 1.2 mm, ENIG 1U inch, green mask/white legend, 68 x 100.26 mm detected, single boards, mark removal, full flying-probe testing; bare PCB only, no assembly or stencil.
- Manual production-file approval selected, including Do not confirm automatically. Production-review surcharge USD 1.05 is included in merchandise price.
- JLC displayed shipping estimate USD 22.10 (subtotal USD 81.65); final address, shipping, taxes and delivery date require checkout review.

The workbook retains the earlier GBP 259.48 price snapshot. The current basket is GBP 0.17 lower: the 24 x 7.5 A fuses are now GBP 0.245 each, GBP 5.88 total. Stock is not reserved.

Final outline/mounting fit and full-board thermal/voltage-drop testing at 40 C remain unconfirmed. These are prototype carts, not a production-qualified release. The PCB layout was not changed in this task.

DIGIKEY_BULK_ADD.txt is corrected to quantity,part number,customer reference, matching the successful online import. CSV has explicit column headers and remains unchanged.

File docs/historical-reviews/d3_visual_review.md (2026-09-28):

# D3 visual and assembly recommendations

Read-only review of D2 delivered layouts. Clean native DRC is not a substitute for these improvements.

## Main
- Keep the compact TI switching/gate/sense placement. Do not spread it just to fill the board.
- Organize the distribution section as four aligned branch cells with consistent holder-to-connector spacing. Existing row alignment is a useful starting point.
- Restore visible F1–F6 and J1–J6 references, connector functions, polarity and fuse ratings. Many references disappeared when crowded silkscreen was moved wholesale to fabrication layer.
- Use the empty lower-middle region for a clear title/revision and a compact connector/fuse key, or a ref-only assembly legend.
- Clean the long output path into a deliberate edge corridor with consistent 45-degree transitions and a short fuse approach. Avoid cosmetic trace changes in Kelvin-sense and gate loops.
- Current fabrication page overlaps values and references severely. Produce a ref-only assembly view, with enlarged boost detail if needed; BOM supplies values.

## USB
- Label the two sockets PORT1 / PORT2 and 5V / 3A; ensure J2/J3 are visible.
- Align mounting columns: H3 x13.5 differs from H1 x14; right column is already consistent.
- Centre the added C13/C14 row under the main output capacitor bank, subject to tight low-impedance routing.
- Use consistent horizontal ref text; restore crowded/absent C1, U1, R7, R9 and C10 references. C13 vertical text currently breaks the pattern.
- Review whether input bulk C12 can sit nearer the input/buck path rather than visually isolated top-right. Electrical placement takes priority.
- Preserve the matched port-channel placement and ESD devices immediately behind each socket.

## Shared finish
Use one reference font/size, larger functional connector legends, and a restrained title/revision. Do not print long part values on the board. Use real footprint rotation metadata where practical, or retain a rigorously normalized physical-angle CPL, so visual cleanup does not reintroduce assembly orientation errors. Review actual board, copper plots and ref-only assembly drawing separately.

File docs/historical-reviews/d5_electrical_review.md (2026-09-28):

# D5 independent electrical review — three boards

Reviewed2026-09-26. No PCB changes. Intended boards are MAIN12V distribution, separate POE53.5V converter, and unchanged USB5V board. **PoE switch and SENSING GMSL are mutually exclusive configurations.** This is a configuration rule, not a demonstrated hardware interlock.

## Power budget

Assumptions:12V at the MAIN input,90% conversion efficiency for each converter, Jetson60W allowance, fan1.68W, USB6A total at5.0963855V. Efficiency is a design assumption, not measured or a guaranteed minimum.

| Configuration | Nominal source demand | Current at12V |
|---|---:|---:|
|Jetson+fan+USB+PoE|173.5546W|14.4629A|
|Same, PoE output at54.159133V static upper bound|174.4875W|14.5406A|
|Jetson+fan+USB+GMSL4A provisional allowance|143.6559W|11.9713A|
|GMSL3A alternative, only if confirmed|131.6559W|10.9713A|

USB input33.9759W; PoE input77.8987W nominal. Take the larger configuration rather than adding PoE and GMSL. For the same modeled powers at a different board input voltage, I=P/V. No minimum input voltage was specified;10.8V is not a validated operating limit. Upper static PoE calculation is not a full worst case: USB output tolerance, efficiency variation, harness drop, startup and other auxiliaries remain. Keep20A continuous supply-path design/test capability if already implemented; the lower nominal budget does not justify reducing copper or connector ratings before tests.

## Jetson fuse

**Keep7.5A provisionally. It is not established as the unique necessary value.** A12V5A adapter/branch allowance specifies available power, not continuous consumption or startup surge. A5A fuse supplying5A has insufficient demonstrated thermal/startup margin. The manufacturer's typical derating table allows only4A on its5A fuse at65C, while7.5A permits6A. At40C a precise guaranteed interpolated trip/load limit is not given. Measure actual cold/hot startup and sustained peripheral-loaded operation before considering a smaller fuse. Fuse choice must protect the weakest actual branch cable/connector;7.5A is not automatically suitable for an unknown thin device pigtail.

NVIDIA's official Orin Nano developer-kit guide lists a19V supply; NVIDIA staff state12V5A is within the supported developer-kit voltage range. This does not identify the user's exact carrier or prove a5A load. Do not confuse module5V input specifications with the carrier DC jack. The user's12V5A remains a branch design basis, not independently measured consumption.

Sources: [NVIDIA guide](https://docs.nvidia.com/jetson/orin-nano-devkit/user-guide/quick_start.html), [NVIDIA staff12V5A clarification](https://forums.developer.nvidia.com/t/about-power-supply-of-jetson-orin-nano/343709/2), [Littelfuse287 primary datasheet](https://www.littelfuse.com/assetdocs/littelfuse-datasheet-287-atof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).

## GMSL rating

SENSING's primary SG4A-NONX-G2Y-A1 page verifies12V DC input and camera PoC9–16V, but does **not** specify a3A or4A aggregate maximum. CN3 is described with modelDC-005-2.5A-2.0; the embedded2.5A string must not be treated as a proven assembly input rating without its own connector sheet. Actual load depends on the connected cameras. The prior4A is a conservative design allowance, not a verified manufacturer rating; the3A original diagram remains unconfirmed. Keep current fuse pending camera/adapter/connector verification, rather than assert3A and reduce it automatically.

Source: [SENSING manufacturer wiki](https://wiki.sensing-world.com/docs/2_1_NVIDIA_Jetson/Getting_Started/NVIDIA_Jetson_Orin_Nano_NX/Adapter_Board/SG4A-NONX-G2Y-A1).

## Fuse disposition and placement

| Position | Recommendation | Reason |
|---|---|---|
|MAIN Jetson F1|retain7.5A provisional|5A design allowance and unknown startup|
|MAIN GMSL F2|retain7.5A provisional|current/camera aggregate unverified; reassess against actual harness|
|MAIN fan F3|retain1A|0.14A fan does not justify exposing thin branch wiring to whole PSU fault current|
|MAIN USB F4|retain5A|protects12V cable and input before USB output switches; nominal2.83A input|
|MAIN PoE feed F5|retain10A at source|protects MAIN-to-POE12V cable; nominal6.49A converter input|
|POE output F6|retain3A80V|output branch protection has not been shown redundant by coordinated fault analysis|

Do not duplicate F5 at the POE input when the source fuse already protects the entire feed and the local TPS259824 remains. A fuse only at the remote POE board cannot interrupt a cable short ahead of that fuse. The diagram's input-fuse function is therefore better located on MAIN at the cable source. Separate source cable upstream of MAIN still needs installation-specific protection.

The TPS259824 input eFuse can disconnect the boost body-diode path and limits the duration of severe converter faults. However, it senses12V input current, not53.5V cable current, and its delayed overcurrent/fast-trip response, component faults and output-capacitor discharge differ from output-fuse operation. At90% efficiency8.13A nominal input threshold corresponds roughly1.64A output at53.5V in regulated steady state, but this arithmetic is **not** a guarantee of output short protection or a reason to remove F6. Demonstrate fault coordination, cable ratings, capacitor discharge and recovery before removing F6. Never replace80V output fuse with32V insert.

Sources: [TI TPS25982](https://www.ti.com/lit/ds/symlink/tps25982.pdf), [TI LM5122](https://www.ti.com/lit/ds/symlink/lm5122.pdf), [Littelfuse FKS80 manufacturer-sheet mirror](https://xonstorage.z8.web.core.windows.net/pdf/littelfuse_16670004402_apr22_xonlink.pdf).

No physical tests have been performed. Required checks remain startup/inrush, actual camera and Jetson load, cable voltage drop, all allowed configurations at40C, controlled eFuse overload/output-short response, and fuse/connector temperatures. No fuse removal is approved by this review.

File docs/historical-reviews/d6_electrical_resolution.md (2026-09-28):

# D6 electrical sourcing resolution

No PCB changes made. The concrete R1 candidate is **Yageo RC2010JK-077R5L, JLC C4169838**, live220 stock and220 available-order field. It matches7.5Ω±5%,0.75W,2010 general-purpose thick film. Panasonic original ERJ12ZYJ7R5U is explicitly NRFND on its primary product page and is also general purpose, not a special pulse family. Alternative1% YageoRC2010FK-077R5L C877612 has37stock/20order-field, offering less headroom.

Recommendation: adopt C4169838 for the prototype with unchanged footprint and retain the same measured-waveform/thermal validation required by the original design. **Equal/better published repetitive-pulse endurance has not been established**, so this report does not assert that procurement alone qualifies its snubber use. This is a documentary limitation, not a claim that the candidate is known to fail. Do not describe it as a proven pulse-rated drop-in.

Circuit: C1=470pF100V,SW–SNUB;R1=7.5Ω,SNUB–BOOST_OUT. RT40.2kΩ gives223.88kHz from TI equation. Ideal full-swing average P=C·V²·f=0.3014W at53.518V,0.3086W at54.159V, below0.75W. Adding5% capacitance and10% frequency as an illustrative bound gives~0.356W (frequency bound illustrative, not a claimed datasheet limit). RC=3.525ns; ideal instantaneous step peaks~382W and7.14A, with~0.673µJ per edge. Real rise time/parasitics modify the pulse. Published general-purpose continuous-power or seconds-long overload ratings cannot alone validate nanosecond repetitive peaks; matching ringing, resistor temperature and pulse endurance remains the same engineering test obligation as the original untested design.

C1: retain existing KEMET470pF100VC0G5%0805 with fifteen previously observed pieces for ten boards, subject to actual reservation and attrition. Search foundC599927 KEMET470pF100V but10% tolerance and other50V entries; no fully verified better-stock exact-electrical alternative was established. Do not adopt50V for the53.5V snubber.

L1: retain CoilcraftSER2915H-103KL,17 previously observed stock/16order-field. It covers ten before reservation and agreed attrition. No alternate magnetics are recommended merely to increase stock margin: saturation,DCR,AC loss and fit affect the conversion stage. Fixture acceptance remains required. Exact part preorder/restock is the least electrical-risk solution if stock cannot be reserved.

Sources: [Panasonic original](https://industrial.panasonic.com/ww/products/pt/general-purpose-chip-resistors/models/ERJ12ZYJ7R5U), [JLC candidate](https://jlcpcb.com/partdetail/YAGEO-RC2010JK077R5L/C4169838), [JLC1% option](https://jlcpcb.com/partdetail/YAGEO-RC2010FK077R5L/C877612), [manufacturer RC family document mirrored by LCSC](https://datasheet.lcsc.com/lcsc/YAGEO-RC2010JK-070RL_C152156.pdf), [TI LM5122](https://www.ti.com/lit/ds/symlink/lm5122.pdf), [Coilcraft L1](https://www.coilcraft.com/en-us/products/power/shielded-inductors/high-current-flat-wire/ser/ser29xx/ser2915h-103/).

## Published rating comparison and geometry

Yageo RC2010 family specifies0.75W at70°C,derating to zero at155°C;body5.0×2.5mm, same2010land class. Family maximum working-voltage ceiling is200V and maximum overload-voltage ceiling500V, but rated working voltage must also satisfy sqrt(P·R), only~2.372V RMS at7.5Ω/0.75W. These ceiling numbers are not permission for sustained200V or500V across this low resistance. Short-time overload tests likewise do not establish the repeated snubber-pulse envelope. Original Panasonic2010 body/power/tolerance matches and has a wider asymmetric TCR(-100/+600ppm/K) than the candidate±200ppm/K. No claim of improved pulse handling is made.

The cap+frequency illustration is0.308643916×1.05×1.10=0.35648W,about47.5% of0.75W. The extra10% frequency is an engineering allowance, not a verified oscillator maximum. Additional ringing or higher actualfrequency may increase loss; measure at operating corners. Temperature at the resistor can exceed40°Cambient due to nearby power components.

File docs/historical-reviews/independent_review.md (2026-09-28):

# Independent electrical review — UMI D2

Reviewed source capture in work/design_d2.py and work/main_power_d2.py on 2026-09-25. This is an independent circuit review, not ERC/DRC, a manufactured-board test, or a release authorization. Scripts are being changed concurrently; observations refer to the versions read during this review.

## Corrections identified

1. USB nominal voltage margin: original 100k/24.9k feedback gives 5.01606 V, with reference and 0.1% resistor extremes 4.93292–5.09947 V. Recommend 102k/24.9k: 5.09639 V nominal, 5.01188–5.18116 V. These limits assume FPWM; connect SYNC/MODE to VCC if using them. They exclude transient ripple and FB bias error. TI gives 50 nA typical FB current, no maximum; approximately 5.1 mV output shift at the typical value with 102k top resistance. Treat the 68.8 mV upper allowance to 5.25 V as a test budget, not guaranteed overshoot immunity. [TI TPSM63610](https://www.ti.com/lit/ds/symlink/tpsm63610.pdf), tables 5-1 and 6.5.
2. USB C12 EEEFK1E470P is 6.3 mm diameter, 5.8 mm height. Use Capacitor_SMD:CP_Elec_6.3x5.8. Panasonic recommends identical copper lands for its D (5.8 mm) and D8 (7.7 mm) case heights, so the original height error was not independently proven to invalidate the copper lands. [Panasonic part specification](https://industrial.panasonic.com/ww/products/pt/aluminum-cap-smd/models/EEEFK1E470P), [FK case and land tables](https://industrial.panasonic.com/cdbs/www-data/pdf/RDE0000/ABA0000C1181.pdf).
3. Main R19 85.4k / RT0603BRD0785K4L was unverified and not a standard E96 value. Main agent notified; 84.5k plus 931 ohm with 1.96k bottom gives nominal 53.50469 V. Exact assembled MPN sourcing still required.

## USB power and interface assessment

TPS2557 pin schedule and enable polarity match the capture. 32.4k/0.1% gives approximately 3.08453 A minimum, 3.67898 A maximum per port using TI current-limit equations. Two maximum limits total 7.35796 A, below the buck's 8 A continuous nameplate. A 3 A load dissipates up to 0.315 W in each switch at its 35 milliohm maximum resistance. Exposed-pad grounding and useful copper area are necessary. Its reverse leakage specification at VIN=0 does not establish active reverse blocking with VIN powered. Do not describe the ports as generally backfeed-protected. [TI TPS2557](https://www.ti.com/lit/ds/symlink/tps2557.pdf), sections 7.5, 10.2.1.2 and 12.3.

At 3 A, that switch can lose 105 mV. The selected connector's 30 milliohm maximum per contact permits another 180 mV across supply and return contacts. With the proposed 5.096 V nominal bus, the computed minimum after those elements is 4.72688 V before board/cable losses. This does not by itself prove USB-source noncompliance: the exact measurement interface matters. It does preclude claiming guaranteed 5 V at the attached device. Acceptance must measure voltage at the actual load through the intended cable. Connector pins 1/4 are rated 3 A; the other contacts 1 A. [Würth 614004190021](https://www.we-online.com/components/products/datasheet/614004190021.pdf).

TPS2513A implements BC1.2 and proprietary divider/short signatures; physical 3 A capacity is distinct from a negotiated 3 A charging mode. In particular, it is not a USB-PD controller. No assertion of sustained Quest charging power can be made without the actual headset and cable. Its captured DP/DM assignment agrees with the TI pin table. [TI TPS2513A](https://www.ti.com/lit/ds/symlink/tps2513a.pdf).

USBLC6-2SC6 has leakage specified at 5.25 V and minimum breakdown 6 V. A 5.181 V steady rail is not incompatible. It is ESD protection, not a precision overvoltage disconnect; a shorted buck high-side device could still expose downstream components to excessive voltage. No system-level single-fault overvoltage protection has been demonstrated or promised. [ST USBLC6-2](https://www.st.com/resource/en/datasheet/usblc6-2.pdf).

## Main power assessment

PMP21274 is a useful engineering starting point. Keeping its inductor, switch arrangement and compensation while changing output by less than 1 V is preferable to unreviewed major power-stage changes, but this is not proof of stability on a new layout. Input fuse alone has not been shown to interrupt output shorts before damage to the boost conduction path. Disabling switching does not isolate the output from input through L1 and Q1's body diode. The separate work/main_efuse_candidate.md develops a candidate input breaker and highlights remaining validation needs. [TI PMP21274](https://www.ti.com/tool/PMP21274).

## Release gates that remain substantive

- PCB copper completion and a genuine KiCad clearance/unconnected check, followed by schematic-to-layout connectivity agreement. A text parser or successful API load is not a DRC pass.
- Vendor land-pattern verification for custom buck, input terminal and large boost inductor; exact fuse insertion and board thickness compatibility.
- Current-path and connector temperature at simultaneous load, 40 C ambient, intended enclosure and copper weight. Neither module nameplate current nor evaluation-board thermal resistance proves this board's temperature.
- Start/stop, simultaneous load steps, individual USB shorts, boost-output short and recovery, input brownout, cable insertion and voltage overshoot measurements.
- Full resistor/capacitor/semiconductor order codes and assembly stock. Unverified ordering strings must not silently become an order BOM.
- Fabrication plots, drill data and SMT placement orientation review only after electrical and geometric completion. There is not enough evidence to label the present boards ready for ordering.

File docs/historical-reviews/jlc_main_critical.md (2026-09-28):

# Main critical JLC sourcing review

Verified 2026-09-26 from live JLC server-rendered componentInfo. All selected catalogue rows are Extended. Inventory is a snapshot, not reserved stock or an approved assembly quote. Preorder minimum is distinct from displayed in-stock minimum. No upload or order was made.

| Ref | MPN | JLC | Stock | Orderable | Assessment |
|---|---|---|---:|---:|---|
| L1 | SER2915H-103KL | [C19276042](https://jlcpcb.com/partdetail/C19276042) | 17 | 16 | exact; low stock and high assembly difficulty |
| U2 | TPS259824ONRGER | [C2155766](https://jlcpcb.com/partdetail/C2155766) | 1926 | 1920 | exact |
| R2 | MA251230FR004MZ | [C252682](https://jlcpcb.com/partdetail/C252682) | 2724 | 2699 | same electrical value substitute; generic land overlap verified |
| Q1,Q2,Q3 | BSC072N08NS5ATMA1 | [C3278732](https://jlcpcb.com/partdetail/C3278732) | 1 | 0 | unavailable quantity |
| L2 | XAL4020-102MEC | [C4555951](https://jlcpcb.com/partdetail/C4555951) | 9145 | 9104 | packaging suffix substitution |
| Q1,Q2,Q3 | BSC040N08NS5 | [C534333](https://jlcpcb.com/partdetail/C534333) | 6718 | 6628 | recommended prototype substitute; dynamic qualification required |
| D2 | NRVB1H100SFT3G | [C604266](https://jlcpcb.com/partdetail/C604266) | 211 | 208 | automotive qualified same-family substitution |
| U1 | LM5122MHX/NOPB | [C77241](https://jlcpcb.com/partdetail/C77241) | 13966 | 13939 | exact |
| D3 | SMBJ15A | [C83846](https://jlcpcb.com/partdetail/C83846) | 12782 | 12262 | exact |
| D4 | SS10P4-M3/86A | [C968538](https://jlcpcb.com/partdetail/C968538) | 7260 | 7224 | exact |

## Substitution assessment

BSC040N08NS5 (C534333): same Infineon PG-TDSON-8 source pins 1–3, gate 4, drain 5–8 and 80 V rating. RDS(on) 4 mOhm maximum at 10 V, 5.7 mOhm at 6 V improves conduction versus original. Gate charge rises to 43 typical / 54 maximum nC at 10 V; Coss also rises. At 223.9 kHz (RT=40.2 kOhm), three devices times 54 nC plus controller 5 mA yields 41.27 mA; with 10% frequency increase 44.9 mA, below the 50 mA minimum VCC current limit. This supports prototype substitution but does not replace ringing/thermal validation. [Infineon datasheet](https://www.infineon.com/assets/row/public/documents/24/49/infineon-bsc040n08ns5-datasheet-en.pdf), [TI datasheet](https://www.ti.com/lit/ds/symlink/lm5122.pdf).

XAL4020-102MEC replaces -102MEB by Coilcraft packaging code change B to C. Same 1 uH ±20%, 14.6 mOhm maximum DCR, 8.7 A saturation (30% drop), 6.7 A / 9.6 A RMS at 20 / 40 C rise. [Coilcraft family](https://www.coilcraft.com/en-us/products/power/shielded-inductors/molded-inductor/xal/xal40xx/), [datasheet](https://www.coilcraft.com/getmedia/6adcb47d-8b55-416c-976e-1e22e0d2848c/xal4000.pdf).

NRVB1H100SFT3G replaces MBR1H100SFT3G: same onsemi family datasheet, SOD-123FL, 100 V 1 A; NRVB is automotive-qualified prefix. Pinout unchanged. JLC linked manufacturer sheet is captured in raw metadata.

MA251230FR004MZ replaces obsolete Panasonic ERJ-M1WSF4M0U: same 4 mOhm ±1%, improved ±50 ppm/C and 3 W rating. Existing 2512 pad spans x=2.35…3.575 mm, part ends ±3.175 mm, nominal terminal length 1.15 mm: nominal solder overlap 0.825 mm, body-short tolerance minimum about 0.698 mm. Existing lands differ from manufacturer preferred pattern; accept for prototype with assembler land review, do not infer 3 W capability on generic lands. Present dissipation approximately 0.17–0.3 W. [Manufacturer MA specification](https://www.everohms.com/data/10000/ftp/S-10-12-05-34.pdf). Direct PDF download returned 403; manufacturer-indexed dimensional/specification text was accessible. Full drawing review remains an assembly check.

## Remaining assembly limits

L1 has only 16 orderable pieces and high assembly difficulty. D4 TO-277A may require fixture review. Stock of a part does not mean the assembled project is accepted; quote, orientation review, part attrition, fixture availability and prototype tests remain. The original FET has zero available order quantity, so its BOM cannot be submitted unchanged.

## Fuses

Retain branch fuses for this revision. The TPS259824 protects the boost input path, not the other 12 V branches. USB per-port current limiting does not protect the upstream 12 V cable. Fuses give replaceable branch cable/connector fault protection and are pragmatic at these power levels, although six automotive holders consume substantial area and require manual fit. Removing them would require coordinated electronic protection for every branch, verified fault behavior and revised layout; it is not an availability-only substitution. The 53.5 V output fuse must remain voltage-rated above the actual output; a 32 V automotive fuse is unsuitable there. Verified ESKA 80 V 3 A part and other fuse codes are in work/fuse_verification.json.

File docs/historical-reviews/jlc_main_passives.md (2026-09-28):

# MAIN_POWER JLC passive availability audit

Counts are live public JLC page purchasing metadata (overseasStockCount); coordinating browser checks established this field matches displayed In Stock. Not reserved, final order quantity/attrition and assembly eligibility must be confirmed at ordering. Zero differs from search not found and HTTP429 unknown.

No PCB, schematic or BOM substitutions have been applied. R2 shunt is handled by the parallel critical-parts review.

| References | Original MPN | JLC code | Library | Live stock | Status |
|---|---|---|---|---:|---|
| C1 | GRM2165C2A471JA01D | â€” | Unknown | Unknown | not_found_in_search |
| C2, C3, C4, C5, C6, C7, C8 | GRM32ER71K475KE14L | [C711060](https://jlcpcb.com/partdetail/C711060) | Extended | 1941 | live_jlc_in_stock |
| C9, C16 | GRM188R71E104KA01D | [C77050](https://jlcpcb.com/partdetail/C77050) | Extended | 161914 | live_jlc_in_stock |
| C10, C13 | GRM1885C1H101JA01D | [C71664](https://jlcpcb.com/partdetail/C71664) | Unknown | Unknown | retrieval_failed |
| C11 | GCM188R71C105KA64D | [C161212](https://jlcpcb.com/partdetail/C161212) | Extended | 57409 | live_jlc_in_stock |
| C14 | GRM188R71E473KA01D | [C97893](https://jlcpcb.com/partdetail/C97893) | Extended | 0 | live_jlc_zero_stock |
| C15 | GRM21BR72A474KA73L | â€” | Unknown | Unknown | not_found_in_search |
| C17 | GRM1885C1H152JA01D | [C162204](https://jlcpcb.com/partdetail/C162204) | Extended | 26554 | live_jlc_in_stock |
| C18 | GRM188R71H153KA01D | [C86021](https://jlcpcb.com/partdetail/C86021) | Extended | 0 | live_jlc_zero_stock |
| C19, C20 | EEE-FK1K470P | â€” | Unknown | Unknown | not_found_in_search |
| C21 | GRM21BR71H105KA12L | [C77083](https://jlcpcb.com/partdetail/C77083) | Extended | 122926 | live_jlc_in_stock |
| C22 | GRM188R71H104KA93D | [C77055](https://jlcpcb.com/partdetail/C77055) | Extended | 1386623 | live_jlc_in_stock |
| C23 | GRM1885C1H682JA01D | [C162241](https://jlcpcb.com/partdetail/C162241) | Extended | 110602 | live_jlc_in_stock |
| R1 | ERJ-12ZYJ7R5U | â€” | Unknown | Unknown | not_found_in_search |
| R3, R4 | ESR03EZPJ101 | [C253328](https://jlcpcb.com/partdetail/C253328) | Extended | 12799 | live_jlc_in_stock |
| R5, R8, R12, R21 | ERJ-3GEY0R00V | [C122704](https://jlcpcb.com/partdetail/C122704) | Extended | 365980 | live_jlc_in_stock |
| R10 | CRCW060349K9FKEA | [C844789](https://jlcpcb.com/partdetail/C844789) | Extended | 4823 | live_jlc_in_stock |
| R11 | CRCW06033R30JNEA | â€” | Unknown | Unknown | not_found_in_search |
| R13 | CRCW06038K45FKEA | [C2076762](https://jlcpcb.com/partdetail/C2076762) | Extended | 5 | live_jlc_in_stock |
| R14 | CRCW060330K0JNEA | [C2076641](https://jlcpcb.com/partdetail/C2076641) | Extended | 3633 | live_jlc_in_stock |
| R16 | CRCW060340K2FKEA | [C844784](https://jlcpcb.com/partdetail/C844784) | Extended | 5321 | live_jlc_in_stock |
| R17 | CRCW060320K5FKEA | â€” | Unknown | Unknown | not_found_in_search |
| R18 | RT0603BRD071K96L | [C861213](https://jlcpcb.com/partdetail/C861213) | Extended | 2298 | live_jlc_in_stock |
| R19 | RT0603BRD0784K5L | â€” | Unknown | Unknown | not_found_in_search |
| R20 | RT0603BRD07931RL | â€” | Unknown | Unknown | not_found_in_search |
| R22 | RT0603BRD07100KL | [C122538](https://jlcpcb.com/partdetail/C122538) | Extended | 1241622 | live_jlc_in_stock |
| R23 | RT0603BRD0713K7L | [C861119](https://jlcpcb.com/partdetail/C861119) | Extended | 1868 | live_jlc_in_stock |
| R24 | RT0603BRD07182RL | [C705731](https://jlcpcb.com/partdetail/C705731) | Extended | 2535 | live_jlc_in_stock |
| R25 | RT0603BRD07511RL | â€” | Unknown | Unknown | not_found_in_search |

## Substitution candidates, not approved

| Ref | Candidate | JLC | Live stock | Assessment |
|---|---|---|---:|---|
| R5,R8,R12,R21 | ERJ3GEY0R00V | [C122704](https://jlcpcb.com/partdetail/C122704) | 365980 | Exact part after manufacturer hyphen normalization. |
| R17 | 0603WAF2052T5E | [C22910](https://jlcpcb.com/partdetail/C22910) | 38124 | 20.5k 1%100mW75V0603; same value/tolerance/power, verify resistor pulse/environment spec. |
| R11 | 0603WAF330KT5E | [C22979](https://jlcpcb.com/partdetail/C22979) | 347223 | 3.3ohm1%100mW0603; improved tolerance over5%, verify startup resistor pulse behavior. |
| R1 | 201007F750KT4E | [C421781](https://jlcpcb.com/partdetail/C421781) | 8 | 7.5ohm1%750mW2010; verify repetitive snubber pulse curve before approval. |
| R19 | RT0603BRC0784K5L | [C861034](https://jlcpcb.com/partdetail/C861034) | Unknown | 84.5k0.1%15ppm0603; sameYageoRTfamily with improvedTCR vs25ppm. |
| R20 | RT0603BRC07931RL | [C861054](https://jlcpcb.com/partdetail/C861054) | 0 | 931ohm0.1%15ppm0603; sameYageoRTfamily with improvedTCR vs25ppm. |
| R25 | ERA-3AEB5110V | [C2075538](https://jlcpcb.com/partdetail/C2075538) | 0 | 511ohm0.1%25ppm100mW0603; same nominal specification; exact datasheet/package verify. |
| R25 | RQ73C1J511RBTD | [C3959727](https://jlcpcb.com/partdetail/C3959727) | 0 | 511ohm0.1%10ppm150mW0603; alternative pending manufacturer verification. |
| C1 | GCM2165C2A471GA16D | [C17565246](https://jlcpcb.com/partdetail/C17565246) | Unknown | 470pF100VC0G0805 2%; improved tolerance; same dielectric, noDCbias concern. |
| C1 | VJ0805A471GXBPW1BC | [C2254220](https://jlcpcb.com/partdetail/C2254220) | 0 | 470pF100VC0G0805 2%; manufacturer dimensions and voltage coefficient verify. |
| C15 | CC0805KKX7R0BB474 | [C596323](https://jlcpcb.com/partdetail/C596323) | Unknown | 470nF100VX7R10%0805; IC_VIN decoupling around12V, compareDCbias effectivecapacitance. |
| C15 | 08051C474KAT2A | [C597304](https://jlcpcb.com/partdetail/C597304) | Unknown | 470nF100VX7R10%0805; compareDCbias at12V and footprint height. |
| C19,C20 | EEHZC1K470P | [C178648](https://jlcpcb.com/partdetail/C178648) | 12 | 47uF80V10x10.2 hybrid 36mohm versusold700mohm. NOTdropinapproved: outputfilterdamping/stability changes, land drawing required. |
| C18 | CC0603KRX7R9BB153 | [C107076](https://jlcpcb.com/partdetail/C107076) | 403038 | 15nF50VX7R10%0603; same compensationvalue; verifyDCbias atCOMP/FB (~fewV). |
| C18 | 0603B153K500NT | [C1596](https://jlcpcb.com/partdetail/C1596) | 40770 | 15nF50VX7R10%0603; same compensationvalue, compareeffectivecapacitance. |

## Engineering constraints

- C2â€“C8 should retain the exact Murata 80 V, 4.7 ÂµF, 1210 part where possible. Nominal capacitance alone does not establish effective capacitance at 53.5 V. A different 80/100 V ceramic requires DC-bias data and control-loop review.
- C1 is the snubber capacitor: preserve 470 pF, C0G/NP0, at least100 V and +/-5% or better. Do not substitute X7R or a50 V part.
- R1 needs repetitive snubber pulse capability, not merely matching 7.5 ohm/2010/wattage. The stocked UniRoyal candidate is not approved until its pulse curve is checked.
- C19/C20 hybrid candidate has much lower ESR than the original Panasonic FK electrolytic. The changed output-filter damping and converter stability need review; matching body size and voltage is insufficient. EEE-FN1K470UL is rejected as a direct replacement:8 mm body,1.3 ohm ESR and130 mA ripple differ from the10 mm original.
- R18/R19/R20 feedback divider and R22/R23/R24/R25 protection components retain0.1% requirements. Do not silently substitute generic1% parts. Same-value15ppm Yageo alternatives improve TCR but currently have unknown/zero stock.
- C18 compensation capacitor: YageoC107076 has matching15 nF50 VX7R10%0603 nominal specs and substantial live stock; compare effective capacitance in its low-voltage compensation application before final substitution.
- C14 alternate C107093 (CC0603KRX7R9BB473) has matching47 nF/X7R/10%/0603 and higher50 V rating; live inventory still needs browser confirmation.
- The exact8.45 kohm R13 has only5 reported parts; this is not enough for a comfortable small assembly order including attrition.

HTTP429 occurred on C71664, C861034, C17565246, C596323 and C597304. Their stock remains unknown; no claim of out-of-stock follows from rate limiting. Raw live page evidence is retained in work/jlc_main_passive_pages/.

Update: Root live JLC browser found the exact bulk capacitors as normalized EEEFK1K470P / C178556, stock259 minimum1. Retain the original FK electrolytic. The hybrid candidate is unnecessary and not approved.

## Additional exact parts confirmed in live JLC browser

|Ref|Code|Stock|Minimum|
|---|---|---:|---:|
|C1|[C97904](https://jlcpcb.com/partdetail/C97904)|0|317|
|C15|[C97926](https://jlcpcb.com/partdetail/C97926)|12424|1|
|R1|[C2086794](https://jlcpcb.com/partdetail/C2086794)|0|734|
|R11|[C4212014](https://jlcpcb.com/partdetail/C4212014)|0|388|
|R17|[C844143](https://jlcpcb.com/partdetail/C844143)|155|1|
|R19|[C705797](https://jlcpcb.com/partdetail/C705797)|10|1|
|R20|[C861600](https://jlcpcb.com/partdetail/C861600)|7|1|
|R25|[C861455](https://jlcpcb.com/partdetail/C861455)|678|1|

All Extended. R1 original rating is 750 mW. R19/R20 stocks are low; do not equate listed stock with sufficient assembly quantity.

## Manufacturer-reviewed capacitor alternatives

C14: Yageo CC0603KRX7R9BB473, C107093, live JLC stock1,574,400. C18: Yageo CC0603KRX7R9BB153, C107076, live403,038. Both 50V X7R10%,0603; manufacturer dimensions1.6x0.8x0.8mm +/-0.1. C14 preserves47nF with higher voltage rating; C18 preserves15nF. Prototype timing/loop checks remain required.

Primary sources: https://www.yageogroup.com/download/specsheet/CC0603KRX7R9BB473 and https://www.yageogroup.com/download/specsheet/CC0603KRX7R9BB153

C1 alternative C17565246 now verified zero stock. R1 VO SCR2010J7R5 C5140273 live235 stock, but not approved: manufacturer PDF inaccessible and repetitive snubber-pulse rating unverified.

## Applied-change research handoff (10 boards)

Manufacturer-reviewed alternatives are recorded in `jlc_main_approved_substitutes.json`: C1 KEMET C23481145 (15 stock), R11 Yageo C137725 (159032), R13 Yageo C163417 (529), R19 Panasonic C4295220 (694), R20 Yageo C861604 (903). C1 has only five parts beyond the ten placements, so assembler attrition remains a purchasing gate.

R20 changes931Ω to953Ω explicitly. Nominal output53.518163V versus53.504694V before; static extremes52.879495–54.159133V from reference±1% and divider±0.1%, excluding bias/ripple/thermal/overshoot.

R1 remains unresolved. BournsCRM2010-JW-7R5ELF has only1stock, originalPanasoniczero stock/preorder734minimum, UNI-ROYAL201007F750KT4E only8stock, VO SCR2010J7R5 has235stock but manufacturer pulse information inaccessible. A pulse-rated7.32Ω1% or7.68Ω1% alternative would stay completely within the original7.5Ω±5% tolerance envelope;8.2Ω does not. Two15Ωpulse-ratedresistors inparallel is an exact7.5Ω redesign option requiring an added footprint. No unverifiedVO substitute approved.

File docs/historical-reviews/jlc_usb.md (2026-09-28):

# USB_POWER JLCPCB availability audit

All 16 intended SMT parts have live stocked JLC catalog matches; complete TDK orderable suffix required. Stock is not reserved and assembly order acceptance not yet tested.

31 SMT placements, 16 distinct parts. All catalog entries are Extended. Checked 26 September 2026 UTC. No board or BOM source was edited.

| References | Qty | Full catalog MPN | JLC code | Package | Displayed stock |
|---|---:|---|---|---|---:|
| C1,C2 | 2 | CNA6P1X7R1H106KT000A | [C694544](https://jlcpcb.com/partdetail/C694544) | 1210 | 1,024 |
| C12 | 1 | EEEFK1E470P | [C178545](https://jlcpcb.com/partdetail/C178545) | 6.3x5.8mm | 12,963 |
| C3,C9,C10,C13,C14 | 5 | GRM32ER71A476ME15L | [C415541](https://jlcpcb.com/partdetail/C415541) | 1210 | 741 |
| C4,C5,C8,C11 | 4 | GRM188R71E104KA01D | [C77050](https://jlcpcb.com/partdetail/C77050) | 0603 | 161,914 |
| C6,C7 | 2 | GRM31CR71A226KE15L | [C91604](https://jlcpcb.com/partdetail/C91604) | 1206 | 101,994 |
| D1 | 1 | BZT52C12-7-F | [C124196](https://jlcpcb.com/partdetail/C124196) | SOD-123 | 9,099 |
| Q1 | 1 | AO4407A | [C16072](https://jlcpcb.com/partdetail/C16072) | SOIC-8 | 24,090 |
| R1 | 1 | RT0603BRD0724K9L | [C136967](https://jlcpcb.com/partdetail/C136967) | 0603 | 6,436 |
| R2,R3 | 2 | RT0603BRD0732K4L | [C861323](https://jlcpcb.com/partdetail/C861323) | 0603 | 22,326 |
| R4,R5,R6,R9 | 4 | RC0603FR-07100KL | [C14675](https://jlcpcb.com/partdetail/C14675) | 0603 | 8,590,459 |
| R7 | 1 | RT0603BRD07102KL | [C861068](https://jlcpcb.com/partdetail/C861068) | 0603 | 10,762 |
| R8 | 1 | RC0603FR-0715K8L | [C155689](https://jlcpcb.com/partdetail/C155689) | 0603 | 26 |
| U1 | 1 | TPSM63610RDFR | [C7125816](https://jlcpcb.com/partdetail/C7125816) | B3QFN-22(6.5x7.5) | 64 |
| U2,U3 | 2 | TPS2557DRBR | [C130056](https://jlcpcb.com/partdetail/C130056) | SON-8(3x3) | 1,957 |
| U4 | 1 | TPS2513ADBVR | [C473910](https://jlcpcb.com/partdetail/C473910) | SOT-23-6 | 37 |
| U5,U6 | 2 | USBLC6-2SC6 | [C7519](https://jlcpcb.com/partdetail/C7519) | SOT-23-6L | 45,071 |

## Required sourcing correction

C1/C2: replace incomplete base CNA6P1X7R1H106K with **CNA6P1X7R1H106KT000A**, C694544. [TDK product record](https://product.tdk.cn/zh/search/capacitor/ceramic/mlcc/info?part_no=CNA6P1X7R1H106K250AE) explicitly gives delivery MPN pattern CNA6P1X7R1H106KT***A, 10µF±10%, 50V, X7R, 3.2×2.5×2.5mm. The alternative electrical-record code C2182452 is zero-stock; use stocked delivery code C694544. Panasonic EEE-FK1E470P is the same punctuation-normalized catalog MPN EEEFK1E470P.

## Stock and evidence limits

R8 has 26 pieces displayed and zero presale count; U4 has 37 and U1 has 64. These are the limiting per-board parts and must be reconfirmed for the intended order quantity and assembly attrition. No unsupported substitute is proposed: current exact parts are stocked, and no batch quantity is specified.

Displayed stock comes from the JLC field overseasStockCount, verified against root browser rows. canPresaleNumber is retained separately in JSON and is not displayed stock. preMinPurchaseNum is a pre-order minimum, not assembly minimum. Root live browser confirmed minimum 1 for the four additional parts and TPSM63610RDFR/TPS2557DRBR. Public page evidence for the initial twelve parts is saved under work/jlc_evidence; the other four are root browser observations. Stock alone does not reserve inventory or establish final assembly-order acceptance.

J1 and J2/J3 remain user-fit through-hole parts and are excluded from this SMT audit. The old U1 BOM note saying LCSC-only is obsolete: live JLC C7125816 explicitly shows stock64.

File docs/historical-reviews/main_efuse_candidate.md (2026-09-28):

# Boost input eFuse integration candidate — engineering hold

Use TPS259824ONRGER (letter O, circuit breaker), between F5 and all boost circuitry. Existing fuse remains upstream. Source: https://www.ti.com/lit/ds/symlink/tps25982.pdf (Rev D, May 2026).

Pin schedule: 1/2/3/16 and exposed Pad 1 = FUSED_12V; 17–24 = BOOST_IN; 4/5/14 and exposed Pad 2 = GND; 6 = EFUSE_EN; 7 = ITIMER (unconnected initially); 8 = ILIM via 182 ohm 0.1% to GND; 9 = IMON via 511 ohm to GND and test point; 10 RETRY_DLY = GND for latch-off; 11 NRETRY = unconnected; 12 LDSTRT = GND; 13 PG = existing LM5122 UVLO net; 15 dVdt = 6.8 nF / 50 V C0G to GND. Exposed pads are DIFFERENT nets; generic single-ground-EP QFN is invalid.

Engineering choices/calculations:

- EN divider: 100k top from FUSED_12V, 13.7k bottom to GND, both 0.1%. Nominal threshold 9.959 V. Threshold-only extrema 9.793–10.208 V; resistor tolerance and leakage add approximately 0.03 V. 12 V gives 1.446 V EN, well below 6 V recommended limit.
- Tie PG directly to LM5122 UVLO to hold the boost disabled until eFuse fully enhances. The existing 49.9k/8.45k divider supplies the PG pull-up safely (1.738 V at 12 V). Check this joint net against both datasheets before implementation. Do not add a 12 V PG pull-up.
- 182 ohm gives nominal 8.132 A threshold, characterized range 7.23–9.07 A before resistor tolerance. Nominal full switch load at 90% efficiency is 6.49 A at 12 V; at 10 V it becomes 7.79 A and can trip. Therefore this setting supports nominal 12 V, not a guaranteed full-load 10 V operating range.
- 6.8 nF gives approximately 0.676 V/ms and 17.74 ms full 12 V ramp. With boost disabled, local boost input plus output capacitors charge through L1/Q1 body diode. Local nominal capacitance is about 127 uF, giving only 86 mA ramp current. Switch input capacitance adds to this and is unknown. 1 mF additional capacitance would add 0.676 A. Powering an active switch load before boost starts must be tested.
- ITIMER initially open avoids deliberately passing sustained overcurrent. Provide DNP capacitor pads so transient blanking can be characterized later; do not short ITIMER to ground.
- At 6.49 A and maximum 4.5 milliohm on-resistance, eFuse loss is 0.190 W. This is a useful low-loss candidate; thermal vias and actual board copper still matter.

Transient network candidate:

- Littelfuse SMBJ15A from FUSED_12V cathode to GND anode, immediately at eFuse. 15 V stand-off, 24.4 V clamp at 24.6 A (10/1000 us). This is below 30 V IC absolute maximum at the stated waveform; wiring inductance, pulse shape and temperature still require validation. Source: https://m.littelfuse.com/~/media/electronics/datasheets/tvs_diodes/littelfuse_tvs_diode_smbj_datasheet.pdf.pdf
- Input bypass 1 uF/50 V X7R + 100 nF/50 V directly across eFuse IN/GND, with upstream bulk available. Keep paths short.
- Diodes Inc B540C-13-F, cathode BOOST_IN/anode GND, candidate negative transient catch diode. Source: https://www.diodes.com/datasheet/download/B540C.pdf . Rating 40 V, 5 A average, 100 A surge; verify current manufacturing status because the family page lists an EOL PCN whose affected codes were not yet inspected. At interruption it must carry boost-inductor current; verify forward drop at worst transient current against eFuse OUT -0.8 V limit. This part is not approved solely from its 5 A average rating.

Remaining release blockers: custom split-pad footprint, clamp and layout parasitics, proof of negative voltage bound, actual switch capacitance/load startup, short-circuit interruption waveforms, thermal test, and fuse coordination. This candidate is suitable for capture and review, not an assertion of validated protection.

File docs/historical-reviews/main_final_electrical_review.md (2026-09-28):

# Main board final independent electrical review

Reviewed current MAIN_POWER/design.json and main_power_d2.py. Primary sources: https://www.ti.com/lit/ds/symlink/tps25982.pdf ; https://www.ti.com/lit/ds/symlink/lm5122.pdf ; https://www.vishay.com/docs/88983/ss10p4.pdf .

## Required layout and rating attention

D4 SS10P4-M3/86A is correctly oriented: pins1/2 anode GND, pin3 cathode BOOST_IN. Its40V reverse rating exceeds normal12V bus and eFuse16.9V OVLO. Its10A rating and0.56V maximum forward drop at10A/25°C support it as the candidate catch diode. They do not guarantee protection against dynamic undershoot. TPS25982 OUT absolute minimum is−0.8V. TI explicitly requires the Schottky physically close to OUT with minimal parasitic inductance. Current D4(90,55) versus U2(79,60) is~12mm between centres. Move beside OUT bank if practical and give it short, broad output and ground paths. There is only0.24V nominal static margin at the diode's stated10A test point, before inductive overshoot, temperature and current variation. Measure worst-case fault turnoff at the eFuse pins; no−0.8V guarantee is claimed.

18A is not a conservative simultaneous12V input requirement. At nominal output powers and90% conversion efficiencies: Jetson5A + SG4A4A + fan0.14A + USB30W/(12V×0.9) + switch70.085W/(12V×0.9) =18.407A, excluding auxiliary losses. Using raised USB voltage and upper switch voltage raises this to~18.54A. Use at least20A continuous bus/connector/fuse thermal design at12V, with separate minimum-input-voltage and startup/fault analysis. This is a design load estimate, not a measured operating current or recommendation to arbitrarily replace fuses.

## Circuit checks

TPS259824ONRGER input/output/exposed-pad mapping, 182Ω ILIM,511Ω IMON, open ITIMER, RETRY_DLY=GND, NRETRY open and LDSTRT=GND match intended latching fast-trip operation. PG is connected to LM5122 UVLO with49.9k upper/8.45k lower divider from BOOST_IN; nominal divider level is1.738V at12V and2.447V at16.9V, below PG6V recommended maximum. Pulling PG low inhibits boost; there is no inappropriate12V PG pullup. Unpowered PG low specification at26µA is below LM5122 UVLO threshold. Actual fault dynamics still need bench verification.

182Ω produces~8.13A nominal threshold, with wider IC current-limit tolerance previously documented. Near10V full boost load may approach the lower limit; full rated output at undervoltage is not guaranteed. Input/output transient suppression is necessary even though eFuse interrupts the otherwise persistent inductor/body-diode fault path.

## Output voltage

R19=84.5k and R20=931Ω sum85.431k, R18=1.96k, all0.1%. LM5122 FB reference1.188–1.212V gives nominal53.50469V and static extreme52.86619–54.14550V. These exclude feedback bias current, trace effects, ripple and startup overshoot. The switch's53.5V adapter marking alone does not establish its maximum accepted supply voltage. Acceptance of54.15V plus transient margin must be supported by switch documentation or appropriate system testing before production qualification.

No additional definite pin-map error was found in this fault network. Bench release tests must include output short while fully loaded, latched shutdown/reset, startup into actual switch capacitance, minimum input, worst-case negative OUT undershoot and positive IN surge. This remains a prototype candidate, not a production-qualified release.

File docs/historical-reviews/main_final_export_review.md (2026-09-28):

# Independent final main-board export review

Reviewed outputs/UMI_TWO_BOARD_DESIGN/MAIN_POWER with read-only scripts work/review_main_exports.py and work/verify_cpl_angles.py. No deliverable edited.

BOM/CPL coverage passes:65 electrical parts,53 SMT positions,12 manual through-hole parts (six connectors and six fuseholders). Exploded grouped draft BOM, by-reference SMT BOM and CPL references agree exactly. All53 CPL coordinates/footprint angles match the filled board relative to auxiliary origin(10,110.263962). No additional electrical pin-assignment or polarity error found in the reviewed main controller, eFuse, power MOSFETs, catch diode, TVS and bulk capacitors.

One assembly-file correction was identified and communicated: many footprints bake a rotation into their local pad geometry, while raw KiCad CPL says0°. This is valid relative to those custom library variants but ambiguous when an assembler maps the MPN to its own library. Root is generating a normalized supplier file and retaining native raw export. Exact independently derived corrections are work/cpl_rotation_corrections.json. Every numbered pad in each rotated final footprint was compared with its unrotated source and matched the derived transform with zero coordinate error. Baked transform is clockwise in board-view coordinates, so normalized CCW angle is negative baked angle modulo360. U1 and Q1–Q3 become90°; C19/C20 become270°. Source footprint names should replace rotated variant names in the normalized file to prevent applying the transform twice. Supplier library zero-angle preview is still necessary.

Critical physical orientations: U1 pin1 lower-left of its final footprint; U2 pin1 upper-left, input EP25 above GND EP26; Q1/Q2/Q3 source pins1–3 below, gate4 bottom-right, drain land above; C19/C20 positive terminal above/negative below; D3 cathode left on fused input; D4 anodes above on GND and cathode below on BOOST_IN. eFuse PG13 routes UVLO, ITIMER7/NRETRY11 intentionally unconnected, RETRY_DLY10/LDSTRT12 grounded. Catch diode was relocated to(79,53) adjacent to eFuse(79,60), improving the previously flagged loop; dynamic−0.8V limit remains a bench test.

Root reports native saved filled DRC0/unconnected0/parity0 and independent Gerbonara133 drill matches. This review audited BOM/placement/electrical mapping rather than rerunning the native or Gerber checks. No further definite file-ordering problem identified after normalized CPL correction. Supply qualification, thermal/fault tests, assembly quote, inventory and heavy-inductor support remain the documented prototype limitations.

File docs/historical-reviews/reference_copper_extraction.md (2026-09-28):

# TI PMP21274 reference copper extraction

Source: TI TIDRTY5 archive, PMP21274_REVA.PcbDoc. Binary interpretation follows work/datasheets/altium_parser_pcb.cpp (official KiCad Altium parser). Generated by work/extract_reference_copper.py into work/datasheets/pmp_reference_copper.json.

All coordinates are millimetres in original Altium positive-Y-up convention, matching pmp_reference_geometry.json. No translation or reflection has been applied. Binary integer units multiply by 0.00000254 mm. Property dimensions in mil multiply by 0.0254 mm.

Retained:172 netted copper tracks,45 vias,5 copper fills,8 polygon definitions,9 copper-layer regions and9 corresponding shape-based regions. The two region representations describe the same objects and must not both be added. Regions include8 cleared poured copper objects and1 top-layer polygon cutout (kind1, null net). Noncopper mechanical/logo artwork is excluded. No unnetted copper tracks were excluded. No netted copper arcs exist.

Important: Regions6 net fields are65535 even for copper. Their polygon_index resolves the net from Polygons6. Such resolved records have net_inherited_from_polygon=true. Preserve holes_mm. Raw polygon definitions are pour boundaries, not cleared final copper. Prefer Regions6 geometry for exact copper preservation; layer mapping1=top,2=MID1,3=MID2,32=bottom. Via layer74 means multilayer; actual spans are fromlayer1,tolayer32.

Tracks are all ordinary tracks, not polygon outlines. Widths0.254–0.381mm. Vias comprise32 at0.508mm diameter/0.254mm drill and13 at1.27mm diameter/0.635mm drill. Fill rotation is retained separately and must be applied.

Validation: Every binary stream consumed exactly its length with expected record types. Both region encodings consumed exactly their complete subrecords (zero unparsed tail). All9 Regions6 polygons, including holes, pass Shapely validity. Original poured areas in mm²:top GND3400.561,V+339.288,SW_P204.517,NetC5_1 189.515,VOUT332.519;MID1GND4809.831,MID2GND4655.631,bottomGND4840.012. Cutoutarea2.768. These checks verify extraction consistency, not electrical or fabrication approval. Adaptation still requires net mapping, pad registration, clearances and full KiCad DRC after added circuits.

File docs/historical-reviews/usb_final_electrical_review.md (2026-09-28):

# Final USB electrical review — snapshot07 and proposed capacitor update

Reviewed current outputs/UMI_D2/USB_POWER/design.json against TI TPSM63610 SLVSGU1A (December2023), https://www.ti.com/lit/ds/symlink/tpsm63610.pdf. Root reports native DRC/ERC/parity pass; this review does not independently repeat those checks.

## Action before prototype

Increase local output capacitors from3 to5 of GRM32ER71A476ME15L, as root approved. TI Table7-1 requires75µF EFFECTIVE for5V at500–1400kHz. Current15.8k RT is1MHz. The33µF figure elsewhere is for2.2MHz and must not be applied here. TI's example using3×47µF gives approximately78µF effective at5V25°C and57µF at−40°C; this is slim nominal margin, not a certified tolerance-inclusive minimum. Three capacitors are explicitly listed in TI's example, so no assertion of demonstrated instability is warranted. Five provides more useful margin. The illustrative bound78×5/3×0.8×0.85=88.4µF is NOT a verified guaranteed combined-bias/tolerance/temperature curve. Exact5.18V/40°C effectiveness and loop response remain verification items.

TI Table7-1 lists22pF feedforward capacitance across upper feedback resistor. Section8.2.1.2.6 requires4.99kΩ in series to limit injected noise and says its zero should exceed fsw/5. With102kΩ and22pF the zero is~71kHz, conflicting with200kHz target at1MHz.6.8pF gives~229kHz but is not the tabulated recommendation. Do not silently populate a feedforward network based on one conflicting sentence. Provision DNP if useful; with increased output capacitance the near-minimum-capacitance justification is weaker. No explicit maximum COUT was found in reviewed datasheet; startup and load-step behavior still require measurement.

## Confirmed component ratings

TDK CNA6P1X7R1H106K is explicitly listed in TI Table8-2 as10µF50V X7R1210. Two are required; current design has two. Murata GRM32ER71A476ME15L is explicitly listed in TI Tables7-3/8-2 as47µF10V X7R1210. Their names and ratings therefore have direct primary-source support. Capacitor nameplate sums must not be presented as effective operating capacitance.

TPSM63610 recommended VIN3–36V (3.7V required for startup), IOUT0–8A, ambient−40..105°C, junction−40..125°C.150°C is absolute maximum, not the release thermal target despite a less conservative layout-text sentence.40°C ambient is within recommended range but requires board-specific temperature validation; stay below125°C junction. TI example94.3% efficiency is at12V→5V4A and must not be extrapolated as guaranteed6A efficiency. Thermal vias, planes and copper thickness materially change temperature rise.

Current JSON correctly has SYNC/MODE=VCC,102k/24.9k0.1% feedback, revised6.3×5.8 electrolytic footprint, and intended power/ESD pin mappings. Nominal output5.09639V; reference/resistor extrema5.01188–5.18116V exclude FB bias and ripple/transients. Only~68.8mV remains to5.25V upper source target. Scope startup, disconnect and load-step peaks at both USB ports.3A connector contact and TPS2557 losses mean5V at remote device is not guaranteed. No negotiated3A claim is justified.

## Remaining validation and sourcing

At40°C soak, test0/3/6A loads and asymmetricportloading, USBhotplug, short/recovery, outputovershoot/ripple, inputplug-inringing and cable-endvoltage. These are prototype tests, not evidence that current circuit has a demonstrated fault. Inputbulk47µF must be assessed with actual harness; TI general recommendation68–100µF is damping guidance, not a fixedminimum in its2×10µF applicationexample.

Live capacitor lifecycle not verified: TDK official productpage returns403; Murata official page returned only application shell; web search tool unavailable dueauthenticationerror. TI datasheet confirms existence/specification in its publication, not current inventory/active lifecycle. Do not mark either capacitor currently available without assembly-house confirmation. Existing assembly_sourcing.md separates catalog IDs from live assembly inventory.

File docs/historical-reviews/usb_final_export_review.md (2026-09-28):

# Independent USB final export review

Reviewed outputs/UMI_TWO_BOARD_DESIGN/USB_POWER on2026-09-26 using a separate read-only parser script, work/review_usb_exports.py. No deliverable files changed.

Result: no definite BOM/CPL reference, position or pin-orientation error found.

-34 electrical components:31 SMT plus3 manual through-hole connectors J1/J2/J3. Every SMT reference appears exactly in both by-reference BOM and exploded grouped JLC draft BOM and in the CPL; no extra/missing references. C3/C9/C10/C13/C14 are all the intended47µF10V Murata output capacitors.
- All31 CPL coordinates and rotations match the actual filled board footprints. Native KiCad coordinates use auxiliary origin(10,60), X right/Y up in placement export. This transformation is consistent with the80×50mm board. CPL is native KiCad format; assembler import/orientation preview remains required, especially custom module packaging.
- U1 custom TPSM63610 pin1 is upper-left at local(−2.75,−2.925); VIN1 and VIN2 are top corners, VOUT1/VOUT2 bottom corners. Current pad functions match the previously reviewed TI pinout, with MODE tiedVCC and RBOOT/CBOOT joined. CPL U1 rotation0 is consistent with the actual footprint geometry. This does not certify a particular assembler's library zero-angle convention.
- Q1 pin1 is upper-left, source pins1–3 protected input, gate4, drain5–8 raw input. C12 positive pad1 is left/protected input and negative2 right/GND. No polarity reversal found.
- Manual USB J2/J3 retain pin1VBUS,2D−,3D+,4GND left-to-right in their custom board footprint, matching previously reviewed manufacturer land pattern. Both shell pads GND. They are correctly excluded from SMT placement/BOM and remain included in full BOM as user-fit parts.
- Stored stackup has1.6mm total,0.07/0.035/0.035/0.07mm copper (2/1/1/2oz nominal), ENIG. VIPPO instructions must accompany the board order; stackup metadata alone does not order filled/capped vias.
- Export audit independently records137 expected/exported drills and matching centres/sizes; this review read that result rather than rerunning Gerbonara. Four copper Gerbers, masks, outline and plated/nonplated drill files exist; top paste exists in assembly directory. No bottom assembly is listed.

Remaining ordering limitations are already explicit:13 grouped BOM catalog fields blank, no confirmed assembly quote/inventory; TPSM63610 C7125816 is LCSC-only evidence and does not establish JLC assembly availability. Draft JLC BOM labeling is appropriate. The package is suitable for assembly quoting/prototype review with these conditions, not an automatically accepted or production-qualified order. No external upload was performed.

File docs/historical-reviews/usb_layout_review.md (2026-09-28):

# USB_POWER physical layout review — 2026-09-25

Reviewed current USB_POWER/design.json, route_usb_power.py and the usb_review_04 top render and copper PDF. Root reports native DRC and schematic parity clean; this review does not independently repeat those checks.

## Recommended ESD revision before prototype

Increase board height from 45 to 50 mm, preserving 80 mm width. Move USB connectors J2/J3 pin rows from y=42 to y=47. Place U5 at (25.5, 43.5) and U6 at (68.5, 43.5). Existing orientation is acceptable if routed deliberately. Rotating arrays 90 degrees could align their two channels with connector pins, but is optional and requires routing transform support.

Move C6/C7 to (30.5, 43.5) / (73.5, 43.5), retaining their current orientation so the VBUS pad faces the ESD array. This places each VBUS capacitor pad about 2.4 mm from its array VBUS pad. Proposed courtyards appear separated from the USB shell and ESD courtyards; regenerate native DRC to establish this on actual copper.

Route connector D− and D+ to the ESD array first, then continue from the array to U4. Avoid a distant T-junction with ESD on a long stub. Two same-channel pins can remain joined locally for native connectivity, but external routing should place the protection point along the current path. Direct front traces from connector through-hole pads to the array are preferable to detouring around shell holes.

The ESD VBUS pin has little DC load but carries transient clamp current. Use a short broad connection to the nearby port capacitor and VBUS copper; approximately 0.5 mm where it fits is preferable to an arbitrary 0.25 mm signal route. Give pin 2 a direct ground connection and adjacent vias to the continuous ground plane. Do not route ESD ground through the charging controller's ground return.

These recommendations interpret ST's short I/O, VBUS and ground path guidance and connector proximity recommendation. They do not establish a withstand level. [ST USBLC6-2 datasheet, section 2.3 and Figure 6](https://www.st.com/resource/en/datasheet/usblc6-2.pdf).
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

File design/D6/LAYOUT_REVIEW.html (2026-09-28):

UMI · Revision D6 · 26 September 2026

# Three boards. Separate PoE supply.

The 12 V distribution, PoE boost and USB charging circuits now have separate PCBs. All three pass the configured KiCad electrical and layout checks. This review shows the actual exported fabrication geometry.

12 V PSU → MAIN distribution → Jetson + fan + USB board └→ either GMSL or separate PoE board → switch

Budget: approximately 174 W / 14.5 A at 12 V. PoE and GMSL are alternative system configurations, manually selected. The PoE feed fuse stays at MAIN to protect the interboard cable; all six system fuses remain.
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

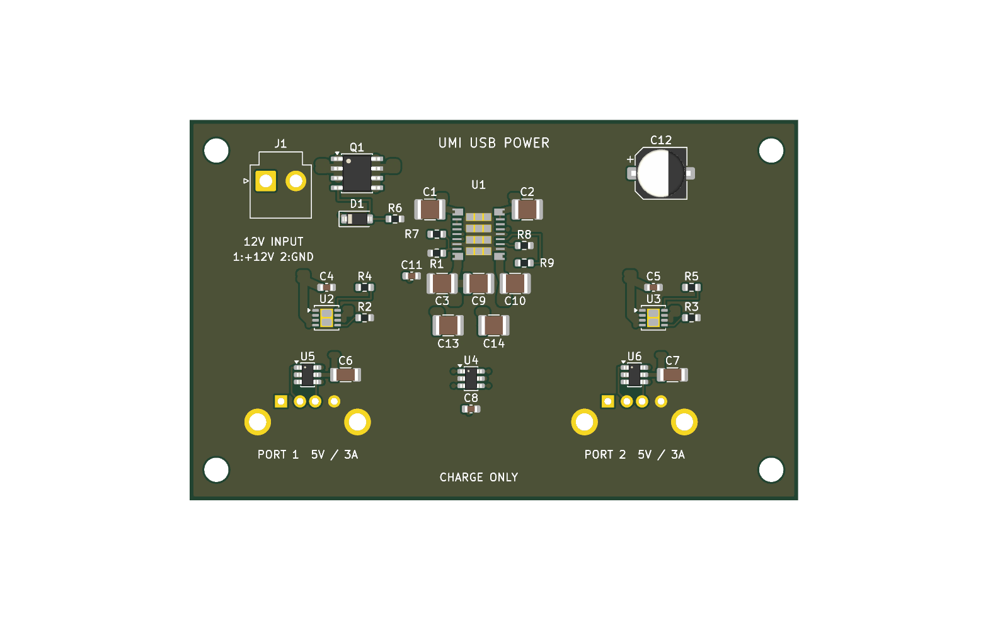
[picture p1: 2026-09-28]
design/D6/USB_POWER/review/USB_POWER_top.png

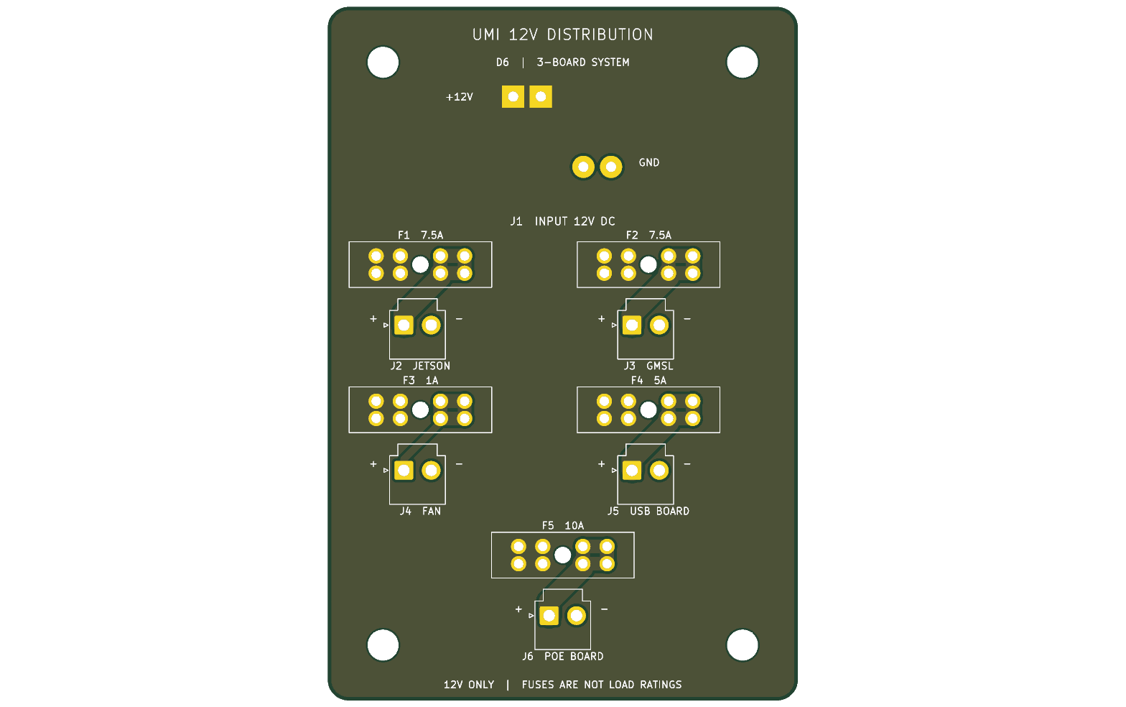
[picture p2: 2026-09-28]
design/D6/MAIN_POWER/review/MAIN_POWER_top.png

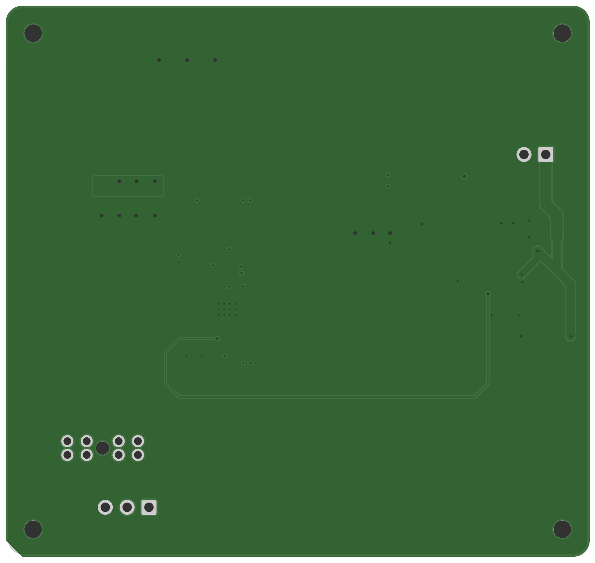
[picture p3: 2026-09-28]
design/D6/POE_POWER/review/POE_POWER_gerber_bottom.png

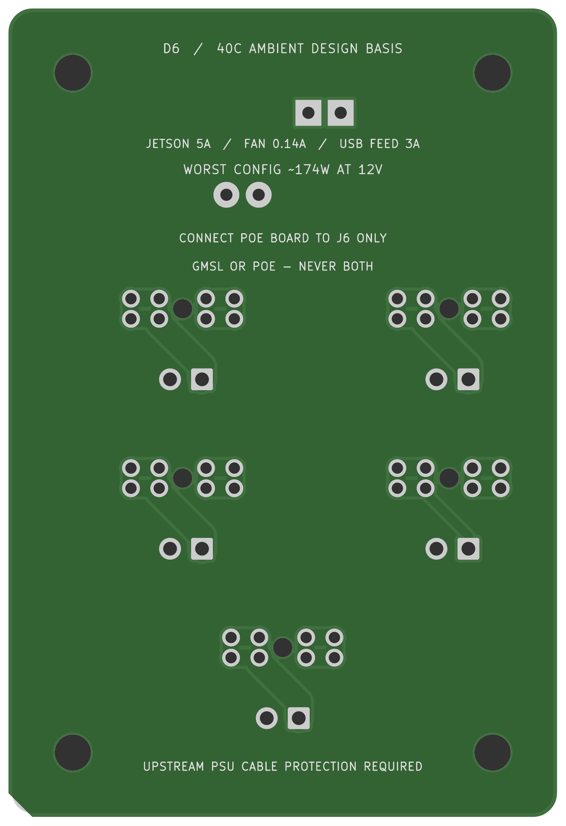
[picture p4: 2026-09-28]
design/D6/MAIN_POWER/review/MAIN_POWER_gerber_bottom.png

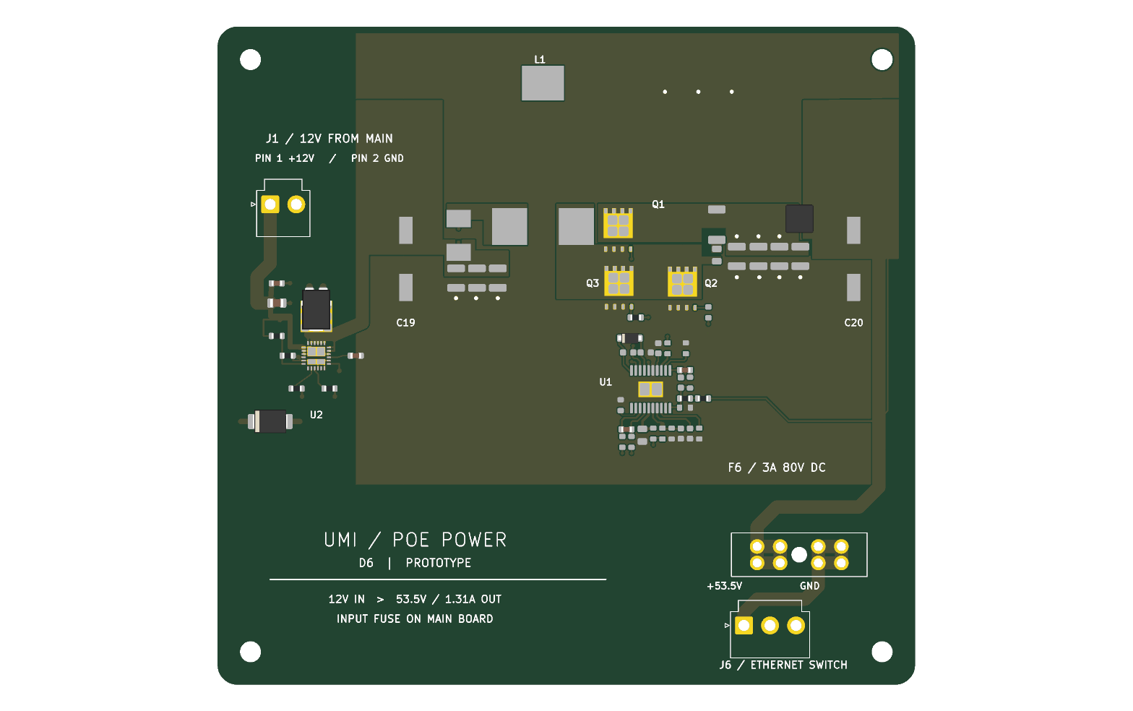
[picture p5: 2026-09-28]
design/D6/POE_POWER/review/POE_POWER_top.png

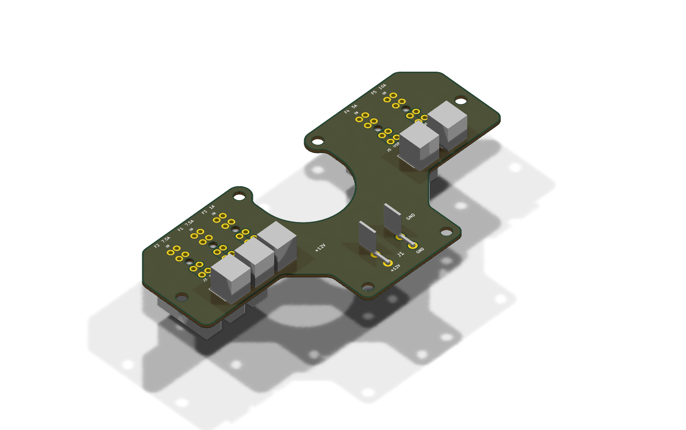
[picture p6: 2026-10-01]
design/D8-2L-FASTON/MAIN_POWER/review/MAIN_POWER_D8_FASTON_3D.png

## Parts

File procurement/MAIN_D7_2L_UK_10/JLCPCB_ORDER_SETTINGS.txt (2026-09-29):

JLCPCB MAIN D7-2L — 10 bare PCBs
Prepared 29 September 2026. Prototype candidate; existing mechanical hold remains.

Upload only JLCPCB_MAIN_D7_2L_GERBERS.zip to the PCB fabrication quote form.
Do not upload the purchasing bundle or the Excel spreadsheet as Gerbers.

Base material: FR-4
Layer count: 2
Quantity: 10
Different designs: 1
Delivery format: Single PCB
Finished thickness: 1.2 mm
Outer copper weight: 2 oz on BOTH sides (nominal 70 um each)
Surface finish: ENIG
Solder mask: Green
Silkscreen: White
PCB assembly: No — all 11 PCB components are through-hole and manually fitted
Stencil: No
Via filling/capping: Not required — no vias
Controlled impedance: No
Electrical test: Required (fabricator standard test)

Nominal outline: 68.000 x 100.263962 mm, preserve supplied Edge_Cuts exactly.
The job file reports 68.05 x 100.314 mm because it includes the outline stroke.
Do not scale or trim the board to qualify for a 100 x 100 mm price band.
Use the Gerber viewer to check layer mapping and dimensions before accepting the quote.
If a selected thickness/copper combination is unavailable, stop for stackup review;
do not substitute 1 oz copper or a different thickness automatically.

Top copper: MAIN_POWER-F_Cu.gtl
Bottom copper: MAIN_POWER-B_Cu.gbl
Top/bottom mask: .gts / .gbs
Top/bottom legend: .gto / .gbo
Board outline: MAIN_POWER-Edge_Cuts.gm1
Plated holes: MAIN_POWER-PTH.drl
Non-plated holes: MAIN_POWER-NPTH.drl
Gerber job: MAIN_POWER-job.gbrjob

This is the latest FAN-3-mm D7-2L export. It is not a production qualification.
Native saved ERC/DRC are clean under the project's configured rules. No fresh CAD
run was needed: source hashes match the saved audit and the exported ZIP was checked
byte-for-byte against the manufacturing directory. Final geometry still needs the
user's confirmation; physical thermal and voltage-drop tests at 40 C remain open.

Official guidance:
https://jlcpcb.com/help/article/how-do-i-place-an-order
https://jlcpcb.com/help/article/instructions-for-ordering
https://jlcpcb.com/help/article/jlcpcb-copper-weight

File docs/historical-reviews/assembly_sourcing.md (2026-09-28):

# Critical SMT assembly sourcing — UMI D2

Checked 2026-09-25 against current design.json files in MAIN_POWER and USB_POWER. This review identifies exact catalog matches. It is not a purchasable BOM or a stock reservation. No files were uploaded and no purchases or account changes were made.

| Board / refs | Exact manufacturer and MPN | Catalog | Evidence / action |
|---|---|---|---|
| USB_POWER / U1 | Texas Instruments — TPSM63610RDFR | [C7125816](https://www.lcsc.com/product-detail/C7125816.html) | LCSC page exposed stock 64; JLC catalog fetch failed/rate-limited. Assembly route unverified. |
| USB_POWER / U2, U3 | Texas Instruments — TPS2557DRBR | [C130056](https://jlcpcb.com/partdetail/C130056) | JLC Extended, SMT Assembly, Economic and Standard; inventory not exposed in current readable page. |
| USB_POWER / U4 | Texas Instruments — TPS2513ADBVR | [C473910](https://jlcpcb.com/partdetail/TexasInstruments-TPS2513ADBVR/C473910) | JLC Extended, SMT Assembly, Economic and Standard; inventory not exposed. |
| USB_POWER / Q1 | Alpha & Omega Semiconductor — AO4407A | [C16072](https://jlcpcb.com/partdetail/Alpha_OmegaSemicon-AO4407A/C16072) | JLC exact AOS manufacturer identity verified; do not substitute another vendor sharing the MPN. |
| USB_POWER / U5, U6 | STMicroelectronics — USBLC6-2SC6 | [C7519](https://jlcpcb.com/partdetail/C7519) | JLC exact ST manufacturer identity verified; do not use GOODWORK/UMW clones without electrical review. |
| MAIN_POWER / U1 | Texas Instruments — LM5122MHX/NOPB | [C77241](https://jlcpcb.com/partdetail/TexasInstruments-LM5122MHXNOPB/C77241) | JLC catalog entry and SMT Assembly verified; cached inventory counts deliberately not accepted as live. |
| MAIN_POWER / U2 | Texas Instruments — TPS259824ONRGER | [C2155766](https://jlcpcb.com/partdetail/TexasInstruments-TPS259824ONRGER/C2155766) | JLC Extended, SMT Assembly, Economic and Standard; inventory not exposed. |
| MAIN_POWER / Q1, Q2, Q3 | Infineon Technologies — BSC072N08NS5ATMA1 | [C3278732](https://jlcpcb.com/partdetail/3841630-BSC072N08NS5ATMA1/C3278732) | JLC catalog match verified. Old indexed result showed only one in stock; current count not exposed, so shortage cannot be confirmed or dismissed. |
| MAIN_POWER / L1 | Coilcraft — SER2915H-103KL | [C19276042](https://jlcpcb.com/partdetail/Coilcraft-SER2915H103KL/C19276042) | JLC catalog match verified. Older indexed JLC page said assembly support fixture required; current extracted page omits this. Confirm fixture service before ordering. |

## Procurement gates

- TPSM63610RDFR: part exists, TI marks it active, and LCSC exposes catalog C7125816. The retrieved LCSC page displayed 64 units. This is LCSC inventory, not proof that JLC can source and assemble it. Request JLC pre-order/global-sourcing confirmation or arrange approved consignment if direct JLC sourcing is unavailable. No such request has been submitted. [TI manufacturer page](https://www.ti.com/product/TPSM63610/part-details/TPSM63610RDFR).
- JLC inventory for the other eight critical parts is unverified. Some search-index snapshots contained quantities, but current readable pages either omitted quantity or returned stale crawls. None of those counts is presented as available stock.
- The Coilcraft inductor is approximately 30 g and large. Its older JLC listing mentioned a support fixture. Confirm assembly handling and fixture costs with the assembler; user willingness to fit through-hole parts does not cover an unassembled SMT inductor.
- The selected SOIC MOSFET and USB ESD device share names with parts from other manufacturers. Preserve AOS C16072 and ST C7519 identities. Catalog substitutions are not approved substitutes.
- Passive-component catalog mapping, feeder-loss quantities, board count, full assembly capability, stencil thermal-pad windows and final placement orientation are outside this critical-parts check and remain required.
- Confirm final sourcing only after layout/DRC and manufacturing exports are complete. A catalog entry establishes an offered component, not an approved assembly order.

## Evidence quality

JLC and LCSC links above are distributor/assembler primary catalog evidence. The module manufacturer link establishes active production only. Stock changes continuously; check the actual order quote immediately before any purchase. Search engine cached counts and related-product recommendations were not treated as live inventory.

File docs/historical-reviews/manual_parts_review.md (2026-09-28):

# Manual-fitting parts review

Status: connector mating parts verified from primary datasheet; fuse order-code/curve verification still open. No design edits made by this review.

## JST VH harness ends — verified

Source: [JST VH manufacturer datasheet](https://www.jst-mfg.com/product/pdf/eng/eVH.pdf), saved as `work/datasheets/jst_vh.pdf`; rendered pages 1 and 2 were inspected because embedded text encoding is defective.

| Use | Exact part | Quantity for PCB-side harness interfaces | Evidence |
|---|---|---:|---|
| Mate standard B2P-VH headers | JST VHR-2N | 5 | Housing table, page 2; two circuits, 3.96 mm pitch |
| Mate standard B3P-VH switch header | JST VHR-3N | 1 | Housing table, page 2; three circuits, 3.96 mm pitch |
| AWG16 receptacle contact | JST SVH-41T-P1.1 | 12 if every populated wire uses this compatible wire range | Page 2: AWG20–16, 0.5–1.25 mm², insulation OD 1.7–3.0 mm, tin-plated copper alloy |
| Optional smaller-wire receptacle contact | JST SVH-21T-P1.1 | Replace relevant contact quantities, do not add blindly | Page 2: AWG22–18, 0.33–0.83 mm², insulation OD 1.7–3.0 mm |

The five 2-position housings cover main-board Jetson, SG4A, fan and USB outputs, plus USB-board input. Thus both ends of the interboard cable are included. Device-side proprietary/barrel connector ends are **not** included or verified here. The 3-position switch housing should contain contacts only in positions 1 (+53.5 V) and 3 (return); position 2 remains empty according to the present design. Housing position numbering must be followed from the drawing, not inferred from a front/back photograph.

The AWG16 selection is supported explicitly by the manufacturer table. A smaller fan pigtail must use a contact matched to its actual conductor and insulation size, or a suitable transition to the chosen harness wire; do not crimp undersized conductors in the AWG20–16 contact. The `S` contact designation is strip/reel form. Hand-fitting still requires proper contact crimping; buying the right contact does not establish a hand-tool setting or completed crimp quality. Manufacturer-listed applicators are APLMK SVH41-11 / SVH21-11 for their machine system, not evidence of a generic hand crimper.

Page 1 rates standard-header VH at 10 A with AWG16, 250 V AC/DC, and −40 to +105°C including current-caused temperature rise. These ratings support the intended per-branch currents but do not establish harness temperature rise in the actual enclosure. Page 1 states 1.6 mm applicable PCB thickness: the USB board uses 1.6 mm, while the main board's thinner stackup chosen for its fuseholder requires a mechanical fit/solder projection review. This is not an electrical-current derating curve.

## Fuses — desired values, not yet released purchase codes

| Ref | Intended nominal value | Circuit |
|---|---:|---|
| F1 | 7.5 A | Jetson 12 V |
| F2 | 7.5 A | SG4A 12 V |
| F3 | 1 A | Fan 12 V |
| F4 | 5 A | USB-board 12 V |
| F5 | 10 A | Boost input |
| F6 | 3 A, **80 V DC minimum** | 53.5 V switch output |

All six holders are currently identified as Littelfuse `178.6165.0001`. The root-provided candidate for F6 is Littelfuse `166.7000.4302` (FKS 80 V). This review has **not yet verified** its order-code suffix, time-current curve, temperature correction or physical fit against the holder. Do not promote it to a released order line solely because its family name and nominal ratings sound appropriate.

The supplied public manufacturer/Mouser PDF paths returned access errors in this stream. `work/datasheets/fuse_80v.pdf` is actually an HTML response, not a usable datasheet. The web-search tool also failed authentication, and this stream has no available browser surface. JST's primary PDF was accessible directly. These access limitations are recorded to distinguish missing evidence from a component failure.

Needed before releasing fuse lines: exact manufacturer ordering table, blade/body mechanical dimensions matched to the 178 holder, DC interrupting rating at the application voltage, nominal melting/clearing characteristics, 40°C temperature correction, and startup/inrush coordination. No generic automotive-fuse derating number has been substituted for manufacturer data. Fuses protect wiring and fault energy; nominal fuse current is not an exact trip threshold or a substitute for the eFuse's semiconductor fault protection.

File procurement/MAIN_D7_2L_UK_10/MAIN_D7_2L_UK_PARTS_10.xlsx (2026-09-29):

MAIN D7-2L purchasing list
Board quantity | 10 |  | Parts estimate, ex VAT | £259.48
Spares allowance | 20% |  | DigiKey UK. Observed 29 Sep 2026. Prices and stock must be refreshed at checkout.
 |  |  | No successful online basket or order. Use the accompanying import CSV. Shipping and VAT excluded.
Item | Reference / use | Manufacturer part number | DigiKey UK SKU | Per board | Required | Order multiple | Order qty | Spare qty | Stock observed | GBP each ex VAT | GBP line ex VAT | Notes | Price tier at quantity | Source URL
12 V input terminal | J1 | 1709681 | 277-13746-ND | 1 | 10 | 1 | 12 | 2 | 78 | £5.94000 | £71.28 | Fixed PCB screw terminal. No mating plug needed. | 10 | https://www.digikey.co.uk/en/products/detail/phoenix-contact/1709681/2511044
ATO fuse holder | F1-F5 | 178.6165.0002 | WK6265-ND | 5 | 50 | 1 | 60 | 10 | 15912 | £2.52220 | £151.33 | Complete holder; fuse inserts ordered separately. | 50 | https://www.digikey.co.uk/en/products/detail/littelfuse-commercial-vehicle-products/178-6165-0002/653477
VH 2-pin PCB header | J2-J6 | B2P-VH(LF)(SN) | 455-1639-ND | 5 | 50 | 1 | 60 | 10 | 89118 | £0.09900 | £5.94 | DigiKey catalog name B2P-VH; vertical 3.96 mm tin-plated header. | 10 | https://www.digikey.co.uk/en/products/detail/jst-sales-america-inc/B2P-VH/926547
7.5 A ATO fuse | F1 Jetson / F2 GMSL | 028707.5PXCN | F4198-ND | 2 | 20 | 1 | 24 | 4 | 23266 | £0.25200 | £6.05 | Brown, 32 VDC. Matches existing D7-2L fuse schedule. | 10 | https://www.digikey.co.uk/en/products/detail/littelfuse-inc/028707-5PXCN/2519829
1 A ATO fuse | F3 FAN | 0287001.PXCN | F4191-ND | 1 | 10 | 1 | 12 | 2 | 14558 | £0.24500 | £2.94 | Black, 32 VDC. FAN remains 1 A despite wider copper. | 10 | https://www.digikey.co.uk/en/products/detail/littelfuse-inc/0287001-PXCN/3102551
5 A ATO fuse | F4 USB supply | 0287005.PXCN | F4197-ND | 1 | 10 | 1 | 12 | 2 | 74648 | £0.24500 | £2.94 | Tan, 32 VDC; protects 12 V feed to USB board. | 10 | https://www.digikey.co.uk/en/products/detail/littelfuse-inc/0287005-PXCN/2519811
10 A ATO fuse | F5 PoE supply | 0287010.PXCN | F4199-ND | 1 | 10 | 1 | 12 | 2 | 49529 | £0.24500 | £2.94 | Red, 32 VDC; MAIN 12 V branch only, never 53.5 V output. | 10 | https://www.digikey.co.uk/en/products/detail/littelfuse-inc/0287010-PXCN/2519807
VH 2-pin mating housing | Harness J2-J6 | VHR-2N | 455-VHR-2N-ND | 5 | 50 | 1 | 60 | 10 | 95778 | £0.05160 | £3.10 | Natural colour replaces previous black VHR-2N-BK. Contacts separate. | 50 | https://www.digikey.co.uk/en/products/detail/jst-sales-america-inc/VHR-2N/608624
VH female crimp contact | 2 per mating housing | SVH-41T-P1.1 | 455-1319-100-ND | 10 | 100 | 100 | 200 | 100 | 500 | £0.06480 | £12.96 | 16-20 AWG. Order quantity is CONTACTS: 200 = two strips of 100. | 100 | https://www.digikey.co.uk/en/products/detail/jst-sales-america-inc/SVH-41T-P1-1/26213078
Scope: all MAIN PCB parts, fuse inserts and MAIN-end mating housings/contacts. All components are hand-fitted.
Excludes cable lengths, device-end connectors, enclosure hardware and crimp tooling. These depend on the installation.
JLCPCB: 10 bare boards, 2 layers, 2 oz copper per side, 1.2 mm, ENIG. Mechanical confirmation and prototype thermal tests remain open.
Prices use the displayed tiers for the initial basket. Changing quantities recalculates counts and cost at the same unit prices. Refresh prices for a new batch.

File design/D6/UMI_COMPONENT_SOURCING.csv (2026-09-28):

board | refs | qty_per_pair | mpn | manufacturer | value | assembly | jlc_code | current_stock | status | checked_utc | source_url | proposed_alternative | required_10_pairs | purchase_quantity | purchase_supplier | purchase_stock | purchase_url | purchase_basis
MAIN_POWER | J1 | 1 | 1709681 | Phoenix Contact | 12V PSU INPUT | MANUAL_THT | C5872886 | 0 | Exact loose part in stock; user-fit | 2026-09-26 | https://jlcpcb.com/partdetail/C5872886 | D6 exact MPN retained. Purchase separately as loose parts from the listed supplier; omit from JLC SMT assembly. | 10 | 12 | DigiKey | 78 | https://www.digikey.com/en/products/detail/phoenix-contact/1709681/2511044 | 20 percent spares, rounded to supplier order multiple; combined across all board rows for this MPN; quantity shown only on first occurrence.
MAIN_POWER | F1,F2,F3,F4,F5 | 5 | 178.6165.0002 | Littelfuse | ATO/FKS fuse holder; insert separate | MANUAL_THT | C207061 | 617 | Exact loose part in stock; user-fit | 2026-09-26 | https://jlcpcb.com/partdetail/C207061 | D6 exact MPN retained. Purchase separately as loose parts from the listed supplier; omit from JLC SMT assembly. | 50 | 72 | LCSC | 617 | https://www.lcsc.com/product-detail/Fuse-Holders_Littelfuse-178-6165-0002_C207061.html | 20 percent spares, rounded to supplier order multiple; combined across all board rows for this MPN; quantity shown only on first occurrence.
MAIN_POWER | J2,J3,J4,J5,J6 | 5 | B2P-VH(LF)(SN) | JST | 2-pin 12 V header | MANUAL_THT | C160315 | 318370 | Exact loose part in stock; user-fit | 2026-09-26 | https://jlcpcb.com/partdetail/C160315 | D6 exact MPN retained. Purchase separately as loose parts from the listed supplier; omit from JLC SMT assembly. | 50 | 90 | LCSC | 296150 | https://www.lcsc.com/product-detail/C160315.html | 20 percent spares, rounded to supplier order multiple; combined across all board rows for this MPN; quantity shown only on first occurrence.
POE_POWER | J1 | 1 | B2P-VH(LF)(SN) | JST | 2-pin 12 V header | MANUAL_THT | C160315 | 318370 | Exact loose part in stock; user-fit | 2026-09-26 | https://jlcpcb.com/partdetail/C160315 | D6 exact MPN retained. Purchase separately as loose parts from the listed supplier; omit from JLC SMT assembly. | 10 | 0 | LCSC | 296150 | https://www.lcsc.com/product-detail/C160315.html | Included in first occurrence of this MPN; do not purchase twice.
POE_POWER | F6 | 1 | 178.6165.0002 | Littelfuse | ATO/FKS fuse holder; insert separate | MANUAL_THT | C207061 | 617 | Exact loose part in stock; user-fit | 2026-09-26 | https://jlcpcb.com/partdetail/C207061 | D6 exact MPN retained. Purchase separately as loose parts from the listed supplier; omit from JLC SMT assembly. | 10 | 0 | LCSC | 617 | https://www.lcsc.com/product-detail/Fuse-Holders_Littelfuse-178-6165-0002_C207061.html | Included in first occurrence of this MPN; do not purchase twice.
POE_POWER | J6 | 1 | B3P-VH(LF)(SN) | JST | SWITCH 53.5V 1.31A | MANUAL_THT | C160316 | 160039 | Exact loose part in stock; user-fit | 2026-09-26 | https://jlcpcb.com/partdetail/C160316 | D6 exact MPN retained. Purchase separately as loose parts from the listed supplier; omit from JLC SMT assembly. | 10 | 15 | LCSC | 31215 | https://www.lcsc.com/product-detail/C160316.html | 20 percent spares, rounded to supplier order multiple; combined across all board rows for this MPN; quantity shown only on first occurrence.
POE_POWER | U1 | 1 | LM5122MHX/NOPB | Texas Instruments | LM5122MHX/NOPB | SMT | C77241 | 13966 | In stock (Extended) | 2026-09-26 | https://jlcpcb.com/partdetail/C77241 | JLC stock is the dated observation, not reserved inventory. | 10 | 10 | JLCPCB SMT assembly | 13966 | https://jlcpcb.com/partdetail/C77241 | Conservative planning: max(10 installed, 0 minimum)+0 attrition. Exact order-page quantity controls.
POE_POWER | L1 | 1 | SER2915H-103KL | Coilcraft | 10uH | SMT | C19276042 | 17 | In stock (Extended); low stock | 2026-09-26 | https://jlcpcb.com/partdetail/C19276042 | Retained exact magnetics. Ten installed; current catalogue minimum/attrition fields0/0. Observed17. Include required assembly fixture in quote. JLC stock is the dated observation, not reserved inventory. | 10 | 10 | JLCPCB SMT assembly | 17 | https://jlcpcb.com/partdetail/C19276042 | Conservative planning: max(10 installed, 0 minimum)+0 attrition. Exact order-page quantity controls.
POE_POWER | L2 | 1 | XAL4020-102MEC | Coilcraft | 1uH | SMT | C4555951 | 9145 | In stock | 2026-09-26 | https://jlcpcb.com/partdetail/C4555951 | Applied D4: Manufacturer packaging suffix change JLC stock is the dated observation, not reserved inventory. | 10 | 30 | JLCPCB SMT assembly | 9145 | https://jlcpcb.com/partdetail/C4555951 | Conservative placeholder allowance; part-specific attrition/minimum must be resolved by JLC BOM matching.
POE_POWER | Q1,Q2,Q3 | 3 | BSC040N08NS5 | Infineon Technologies | BSC040N08NS5 | SMT | C534333 | 6718 | In stock | 2026-09-26 | https://jlcpcb.com/partdetail/C534333 | Applied D4: Same80Vpinout; driverchargebudget reviewed; prototype ringing/thermal test required JLC stock is the dated observation, not reserved inventory. | 30 | 30 | JLCPCB SMT assembly | 6718 | https://jlcpcb.com/partdetail/C534333 | Conservative planning: max(30 installed, 0 minimum)+0 attrition. Exact order-page quantity controls.
POE_POWER | C1 | 1 | C0805C471J1GACTU | KEMET | 470pF 100V | SMT | C23481145 | 15 | In stock | 2026-09-26 | https://jlcpcb.com/partdetail/C23481145 | Retained 100 V C0G 470 pF 5% snubber capacitor. Ten installed plus four reported attrition requires14; observed15 leavesone. Reserve/match at order, stock not guaranteed. JLC stock is the dated observation, not reserved inventory. | 10 | 14 | JLCPCB SMT assembly | 15 | https://jlcpcb.com/partdetail/C23481145 | Conservative planning: max(10 installed, 5 minimum)+4 attrition. Exact order-page quantity controls.
POE_POWER | C2,C3,C4,C5,C6,C7,C8 | 7 | GRM32ER71K475KE14L | Murata | 4.7uF 80V | SMT | C711060 | 1941 | In stock (Extended) | 2026-09-26T08:44:22.452123+00:00 | https://jlcpcb.com/partdetail/C711060 | JLC stock is the dated observation, not reserved inventory. | 70 | 70 | JLCPCB SMT assembly | 1941 | https://jlcpcb.com/partdetail/C711060 | Conservative planning: max(70 installed, 2 minimum)+0 attrition. Exact order-page quantity controls.
POE_POWER | C9,C16 | 2 | GRM188R71E104KA01D | Murata | 100nF 25V | SMT | C77050 | 161914 | In stock (Extended) | 2026-09-26T08:44:22.612045+00:00 | https://jlcpcb.com/partdetail/C77050 | JLC stock is the dated observation, not reserved inventory. | 20 | 30 | JLCPCB SMT assembly | 161914 | https://jlcpcb.com/partdetail/C77050 | Conservative placeholder allowance; part-specific attrition/minimum must be resolved by JLC BOM matching.
POE_POWER | C10,C13 | 2 | GRM1885C1H101JA01D | Murata | 100pF 50V | SMT | C71664 | 171060 | In stock (Extended) | 2026-09-26 | https://jlcpcb.com/partdetail/C71664 | JLC stock is the dated observation, not reserved inventory. | 20 | 30 | JLCPCB SMT assembly | 171060 | https://jlcpcb.com/partdetail/C71664 | Conservative planning: max(20 installed, 20 minimum)+10 attrition. Exact order-page quantity controls.
POE_POWER | C11 | 1 | GCM188R71C105KA64D | Murata | 1uF 16V | SMT | C161212 | 57409 | In stock (Extended) | 2026-09-26T08:44:22.570853+00:00 | https://jlcpcb.com/partdetail/C161212 | JLC stock is the dated observation, not reserved inventory. | 10 | 30 | JLCPCB SMT assembly | 57409 | https://jlcpcb.com/partdetail/C161212 | Conservative placeholder allowance; part-specific attrition/minimum must be resolved by JLC BOM matching.
POE_POWER | C14 | 1 | CC0603KRX7R9BB473 | Yageo | 47nF 50V | SMT | C107093 | 1574400 | In stock | 2026-09-26 | https://jlcpcb.com/partdetail/C107093 | Applied D4: Same47nFX7R10%0603; higher50Vrating JLC stock is the dated observation, not reserved inventory. | 10 | 30 | JLCPCB SMT assembly | 1574400 | https://jlcpcb.com/partdetail/C107093 | Conservative placeholder allowance; part-specific attrition/minimum must be resolved by JLC BOM matching.
POE_POWER | C15 | 1 | GRM21BR72A474KA73L | Murata | 470nF 100V | SMT | C97926 | 12424 | In stock (Extended) | 2026-09-26T08:53:01.144232+00:00 | https://jlcpcb.com/partdetail/C97926 | CC0805KKX7R0BB474 C596323; stock unverified; 470nF100VX7R10%0805; IC_VIN decoupling around12V, compareDCbias effectivecapacitance.; https://jlcpcb.com/partdetail/C596323 | 08051C474KAT2A C597304; stock unverified; 470nF100VX7R10%0805; compareDCbias at12V and footprint height.; https://jlcpcb.com/partdetail/C597304 JLC stock is the dated observation, not reserved inventory. | 10 | 30 | JLCPCB SMT assembly | 12424 | https://jlcpcb.com/partdetail/C97926 | Conservative placeholder allowance; part-specific attrition/minimum must be resolved by JLC BOM matching.
POE_POWER | C17 | 1 | GRM1885C1H152JA01D | Murata | 1500pF 50V | SMT | C162204 | 26554 | In stock (Extended) | 2026-09-26T08:44:22.622557+00:00 | https://jlcpcb.com/partdetail/C162204 | JLC stock is the dated observation, not reserved inventory. | 10 | 30 | JLCPCB SMT assembly | 26554 | https://jlcpcb.com/partdetail/C162204 | Conservative planning: max(10 installed, 20 minimum)+10 attrition. Exact order-page quantity controls.
POE_POWER | C18 | 1 | CC0603KRX7R9BB153 | Yageo | 15nF 50V | SMT | C107076 | 403038 | In stock | 2026-09-26 | https://jlcpcb.com/partdetail/C107076 | Applied D4: Same15nF50VX7R10%0603 JLC stock is the dated observation, not reserved inventory. | 10 | 30 | JLCPCB SMT assembly | 403038 | https://jlcpcb.com/partdetail/C107076 | Conservative planning: max(10 installed, 20 minimum)+10 attrition. Exact order-page quantity controls.
POE_POWER | C19,C20 | 2 | EEE-FK1K470P | Panasonic | 47uF 80V | SMT | C178556 | 259 | In stock (Extended) | 2026-09-26 | https://jlcpcb.com/partdetail/C178556 | JLC stock is the dated observation, not reserved inventory. | 20 | 20 | JLCPCB SMT assembly | 259 | https://jlcpcb.com/partdetail/C178556 | Conservative planning: max(20 installed, 2 minimum)+0 attrition. Exact order-page quantity controls.
POE_POWER | R1 | 1 | RC2010JK-077R5L | Yageo | 7.5 | SMT | C4169838 | 220 | In stock; prototype snubber substitute | 2026-09-26 | https://jlcpcb.com/partdetail/C4169838 | D6: same 7.5 ohm, 5%, 0.75 W, 2010 geometry. About 0.30 W estimated snubber dissipation; measured pulse/thermal qualification still required. Replaces preorder Panasonic part. JLC stock is the dated observation, not reserved inventory. | 10 | 30 | JLCPCB SMT assembly | 220 | https://jlcpcb.com/partdetail/C4169838 | Ten fitted plus twenty planning allowance; confirm exact JLC minimum and attrition at matching.
POE_POWER | R2 | 1 | MA251230FR004MZ | Ever Ohms Tech | 4m 1% | SMT | C252682 | 2724 | In stock | 2026-09-26 | https://jlcpcb.com/partdetail/C252682 | Applied D4: 4mOhm1%; new manufacturer-recommended land required JLC stock is the dated observation, not reserved inventory. | 10 | 12 | JLCPCB SMT assembly | 2724 | https://jlcpcb.com/partdetail/C252682 | Conservative planning: max(10 installed, 5 minimum)+2 attrition. Exact order-page quantity controls.
POE_POWER | R3,R4 | 2 | ESR03EZPJ101 | ROHM | 100 | SMT | C253328 | 12799 | In stock (Extended) | 2026-09-26T08:44:23.199833+00:00 | https://jlcpcb.com/partdetail/C253328 | JLC stock is the dated observation, not reserved inventory. | 20 | 30 | JLCPCB SMT assembly | 12799 | https://jlcpcb.com/partdetail/C253328 | Conservative planning: max(20 installed, 20 minimum)+10 attrition. Exact order-page quantity controls.
POE_POWER | R5,R21,R8,R12 | 4 | ERJ-3GEY0R00V | Panasonic | 0 | SMT | C122704 | 365980 | In stock (Extended) | 2026-09-26T08:45:45.208143+00:00 | https://jlcpcb.com/partdetail/C122704 | JLC stock is the dated observation, not reserved inventory. | 40 | 50 | JLCPCB SMT assembly | 365980 | https://jlcpcb.com/partdetail/C122704 | Conservative planning: max(40 installed, 20 minimum)+10 attrition. Exact order-page quantity controls.
POE_POWER | R10 | 1 | CRCW060349K9FKEA | Vishay | 49.9k | SMT | C844789 | 4823 | In stock (Extended) | 2026-09-26T08:44:23.908301+00:00 | https://jlcpcb.com/partdetail/C844789 | JLC stock is the dated observation, not reserved inventory. | 10 | 30 | JLCPCB SMT assembly | 4823 | https://jlcpcb.com/partdetail/C844789 | Conservative planning: max(10 installed, 20 minimum)+10 attrition. Exact order-page quantity controls.
POE_POWER | R11 | 1 | RC0603FR-073R3L | Yageo | 3.3 1% | SMT | C137725 | 159032 | In stock | 2026-09-26 | https://jlcpcb.com/partdetail/C137725 | Applied D4: Same3.3ohm0603100mW; toleranceimproved1% JLC stock is the dated observation, not reserved inventory. | 10 | 30 | JLCPCB SMT assembly | 159032 | https://jlcpcb.com/partdetail/C137725 | Conservative planning: max(10 installed, 20 minimum)+10 attrition. Exact order-page quantity controls.
POE_POWER | R13 | 1 | RC0603FR-078K45L | Yageo | 8.45k | SMT | C163417 | 529 | In stock | 2026-09-26 | https://jlcpcb.com/partdetail/C163417 | Applied D4: Same8.45k1%0603100mW JLC stock is the dated observation, not reserved inventory. | 10 | 30 | JLCPCB SMT assembly | 529 | https://jlcpcb.com/partdetail/C163417 | Conservative planning: max(10 installed, 20 minimum)+10 attrition. Exact order-page quantity controls.
POE_POWER | R14 | 1 | CRCW060330K0JNEA | Vishay | 30k | SMT | C2076641 | 3633 | In stock (Extended) | 2026-09-26T08:44:24.342571+00:00 | https://jlcpcb.com/partdetail/C2076641 | JLC stock is the dated observation, not reserved inventory. | 10 | 26 | JLCPCB SMT assembly | 3633 | https://jlcpcb.com/partdetail/C2076641 | Conservative planning: max(10 installed, 20 minimum)+6 attrition. Exact order-page quantity controls.
POE_POWER | R16 | 1 | CRCW060340K2FKEA | Vishay | 40.2k | SMT | C844784 | 5321 | In stock (Extended) | 2026-09-26T08:44:24.338979+00:00 | https://jlcpcb.com/partdetail/C844784 | JLC stock is the dated observation, not reserved inventory. | 10 | 26 | JLCPCB SMT assembly | 5321 | https://jlcpcb.com/partdetail/C844784 | Conservative planning: max(10 installed, 20 minimum)+6 attrition. Exact order-page quantity controls.
POE_POWER | R17 | 1 | CRCW060320K5FKEA | Vishay | 20.5k | SMT | C844143 | 155 | In stock (Extended) | 2026-09-26T08:53:01.144232+00:00 | https://jlcpcb.com/partdetail/C844143 | 0603WAF2052T5E C22910; stock 38124; 20.5k 1%100mW75V0603; same value/tolerance/power, verify resistor pulse/environment spec.; https://jlcpcb.com/partdetail/C22910 JLC stock is the dated observation, not reserved inventory. | 10 | 30 | JLCPCB SMT assembly | 155 | https://jlcpcb.com/partdetail/C844143 | Conservative placeholder allowance; part-specific attrition/minimum must be resolved by JLC BOM matching.
POE_POWER | R18 | 1 | RT0603BRD071K96L | Yageo | 1.96k 0.1% | SMT | C861213 | 2298 | In stock (Extended) | 2026-09-26T08:44:23.582738+00:00 | https://jlcpcb.com/partdetail/C861213 | JLC stock is the dated observation, not reserved inventory. | 10 | 28 | JLCPCB SMT assembly | 2298 | https://jlcpcb.com/partdetail/C861213 | Conservative planning: max(10 installed, 20 minimum)+8 attrition. Exact order-page quantity controls.
POE_POWER | R19 | 1 | ERA-3AEB8452V | Panasonic | 84.5k 0.1% | SMT | C4295220 | 694 | In stock | 2026-09-26 | https://jlcpcb.com/partdetail/C4295220 | Applied D4: Same84.5k0.1%25ppm0603 JLC stock is the dated observation, not reserved inventory. | 10 | 14 | JLCPCB SMT assembly | 694 | https://jlcpcb.com/partdetail/C4295220 | Conservative planning: max(10 installed, 5 minimum)+4 attrition. Exact order-page quantity controls.
POE_POWER | R20 | 1 | RT0603BRD07953RL | Yageo | 953 0.1% | SMT | C861604 | 903 | In stock | 2026-09-26 | https://jlcpcb.com/partdetail/C861604 | Applied D4: Explicit value revision931to953ohm; nominal53.518163V static52.879495-54.159133V, excluding ripple/transients JLC stock is the dated observation, not reserved inventory. | 10 | 30 | JLCPCB SMT assembly | 903 | https://jlcpcb.com/partdetail/C861604 | Conservative placeholder allowance; part-specific attrition/minimum must be resolved by JLC BOM matching.
POE_POWER | D2 | 1 | NRVB1H100SFT3G | onsemi | MBR1H100SFT3G | SMT | C604266 | 211 | In stock | 2026-09-26 | https://jlcpcb.com/partdetail/C604266 | Applied D4: Same family/pinout; automotivequalified variant JLC stock is the dated observation, not reserved inventory. | 10 | 10 | JLCPCB SMT assembly | 211 | https://jlcpcb.com/partdetail/C604266 | Conservative planning: max(10 installed, 5 minimum)+0 attrition. Exact order-page quantity controls.
POE_POWER | U2 | 1 | TPS259824ONRGER | Texas Instruments | TPS259824ONRGER | SMT | C2155766 | 1926 | In stock (Extended) | 2026-09-26 | https://jlcpcb.com/partdetail/C2155766 | JLC stock is the dated observation, not reserved inventory. | 10 | 10 | JLCPCB SMT assembly | 1926 | https://jlcpcb.com/partdetail/C2155766 | Conservative planning: max(10 installed, 0 minimum)+0 attrition. Exact order-page quantity controls.
POE_POWER | R22 | 1 | RT0603BRD07100KL | Yageo | 100k 0.1% | SMT | C122538 | 1241622 | In stock (Extended) | 2026-09-26T08:44:23.914618+00:00 | https://jlcpcb.com/partdetail/C122538 | JLC stock is the dated observation, not reserved inventory. | 10 | 28 | JLCPCB SMT assembly | 1241622 | https://jlcpcb.com/partdetail/C122538 | Conservative planning: max(10 installed, 20 minimum)+8 attrition. Exact order-page quantity controls.
POE_POWER | R23 | 1 | RT0603BRD0713K7L | Yageo | 13.7k 0.1% | SMT | C861119 | 1868 | In stock (Extended) | 2026-09-26T08:44:23.715502+00:00 | https://jlcpcb.com/partdetail/C861119 | JLC stock is the dated observation, not reserved inventory. | 10 | 28 | JLCPCB SMT assembly | 1868 | https://jlcpcb.com/partdetail/C861119 | Conservative planning: max(10 installed, 20 minimum)+8 attrition. Exact order-page quantity controls.
POE_POWER | R24 | 1 | RT0603BRD07182RL | Yageo | 182 0.1% | SMT | C705731 | 2535 | In stock (Extended) | 2026-09-26T08:44:23.675261+00:00 | https://jlcpcb.com/partdetail/C705731 | JLC stock is the dated observation, not reserved inventory. | 10 | 30 | JLCPCB SMT assembly | 2535 | https://jlcpcb.com/partdetail/C705731 | Conservative placeholder allowance; part-specific attrition/minimum must be resolved by JLC BOM matching.
POE_POWER | R25 | 1 | RT0603BRD07511RL | Yageo | 511 0.1% | SMT | C861455 | 678 | In stock (Extended) | 2026-09-26T08:53:01.144232+00:00 | https://jlcpcb.com/partdetail/C861455 | ERA-3AEB5110V C2075538; stock 0; 511ohm0.1%25ppm100mW0603; same nominal specification; exact datasheet/package verify.; https://jlcpcb.com/partdetail/C2075538 | RQ73C1J511RBTD C3959727; stock 0; 511ohm0.1%10ppm150mW0603; alternative pending manufacturer verification.; https://jlcpcb.com/partdetail/C3959727 JLC stock is the dated observation, not reserved inventory. | 10 | 28 | JLCPCB SMT assembly | 678 | https://jlcpcb.com/partdetail/C861455 | Conservative planning: max(10 installed, 20 minimum)+8 attrition. Exact order-page quantity controls.
POE_POWER | C21 | 1 | GRM21BR71H105KA12L | Murata | 1uF 50V X7R | SMT | C77083 | 122926 | In stock (Extended) | 2026-09-26T08:44:23.154047+00:00 | https://jlcpcb.com/partdetail/C77083 | JLC stock is the dated observation, not reserved inventory. | 10 | 14 | JLCPCB SMT assembly | 122926 | https://jlcpcb.com/partdetail/C77083 | Conservative planning: max(10 installed, 5 minimum)+4 attrition. Exact order-page quantity controls.
POE_POWER | C22 | 1 | GRM188R71H104KA93D | Murata | 100nF 50V | SMT | C77055 | 1386623 | In stock (Extended) | 2026-09-26T08:44:23.169046+00:00 | https://jlcpcb.com/partdetail/C77055 | JLC stock is the dated observation, not reserved inventory. | 10 | 26 | JLCPCB SMT assembly | 1386623 | https://jlcpcb.com/partdetail/C77055 | Conservative planning: max(10 installed, 20 minimum)+6 attrition. Exact order-page quantity controls.
POE_POWER | C23 | 1 | GRM1885C1H682JA01D | Murata | 6.8nF 50V C0G | SMT | C162241 | 110602 | In stock (Extended) | 2026-09-26T08:44:23.191834+00:00 | https://jlcpcb.com/partdetail/C162241 | JLC stock is the dated observation, not reserved inventory. | 10 | 28 | JLCPCB SMT assembly | 110602 | https://jlcpcb.com/partdetail/C162241 | Conservative planning: max(10 installed, 20 minimum)+8 attrition. Exact order-page quantity controls.
POE_POWER | D3 | 1 | SMBJ15A | Littelfuse | SMBJ15A | SMT | C83846 | 12782 | In stock (Extended) | 2026-09-26 | https://jlcpcb.com/partdetail/C83846 | JLC stock is the dated observation, not reserved inventory. | 10 | 12 | JLCPCB SMT assembly | 12782 | https://jlcpcb.com/partdetail/C83846 | Conservative planning: max(10 installed, 5 minimum)+2 attrition. Exact order-page quantity controls.
POE_POWER | D4 | 1 | SS10P4-M3/86A | Vishay | SS10P4-M3/86A | SMT | C968538 | 7260 | In stock (Extended) | 2026-09-26 | https://jlcpcb.com/partdetail/C968538 | JLC stock is the dated observation, not reserved inventory. | 10 | 10 | JLCPCB SMT assembly | 7260 | https://jlcpcb.com/partdetail/C968538 | Conservative planning: max(10 installed, 2 minimum)+0 attrition. Exact order-page quantity controls.
USB_POWER | J1 | 1 | B2P-VH(LF)(SN) | JST | 2-pin 12 V header | MANUAL_THT | C160315 | 318370 | Exact loose part in stock; user-fit | 2026-09-26 | https://jlcpcb.com/partdetail/C160315 | D6 exact MPN retained. Purchase separately as loose parts from the listed supplier; omit from JLC SMT assembly. | 10 | 0 | LCSC | 296150 | https://www.lcsc.com/product-detail/C160315.html | Included in first occurrence of this MPN; do not purchase twice.
USB_POWER | Q1 | 1 | AO4407A | Alpha & Omega Semiconductor | AO4407A | SMT | C16072 | 24090 | In stock (Extended) | 2026-09-26T08:44:46.425789+00:00 | https://jlcpcb.com/partdetail/C16072 | JLC stock is the dated observation, not reserved inventory. | 10 | 10 | JLCPCB SMT assembly | 24090 | https://jlcpcb.com/partdetail/C16072 | Conservative planning: max(10 installed, 0 minimum)+0 attrition. Exact order-page quantity controls.
USB_POWER | R6,R9,R4,R5 | 4 | RC0603FR-07100KL | Yageo | 100k | SMT | C14675 | 8590459 | In stock (Extended) | 2026-09-26T08:44:47.054222+00:00 | https://jlcpcb.com/partdetail/C14675 | JLC stock is the dated observation, not reserved inventory. | 40 | 50 | JLCPCB SMT assembly | 8590459 | https://jlcpcb.com/partdetail/C14675 | Conservative planning: max(40 installed, 20 minimum)+10 attrition. Exact order-page quantity controls.
USB_POWER | D1 | 1 | BZT52C12-7-F | Diodes Incorporated | 12V gate clamp | SMT | C124196 | 9099 | In stock (Extended) | 2026-09-26T08:44:46.423656+00:00 | https://jlcpcb.com/partdetail/C124196 | JLC stock is the dated observation, not reserved inventory. | 10 | 18 | JLCPCB SMT assembly | 9099 | https://jlcpcb.com/partdetail/C124196 | Conservative planning: max(10 installed, 5 minimum)+8 attrition. Exact order-page quantity controls.
USB_POWER | U1 | 1 | TPSM63610RDFR | Texas Instruments | TPSM63610RDFR | SMT | C7125816 | 64 | In stock (Extended); low stock | 2026-09-26T08:44:47.558378+00:00 | https://jlcpcb.com/partdetail/C7125816 | JLC stock is the dated observation, not reserved inventory. | 10 | 10 | JLCPCB SMT assembly | 64 | https://jlcpcb.com/partdetail/C7125816 | Conservative planning: max(10 installed, 0 minimum)+0 attrition. Exact order-page quantity controls.
USB_POWER | C1,C2 | 2 | CNA6P1X7R1H106KT000A | TDK | 10uF 50V X7R | SMT | C694544 | 1024 | In stock | 2026-09-26 | https://jlcpcb.com/partdetail/C694544 | Applied D4: Complete manufacturer orderable suffix; same electrical part JLC stock is the dated observation, not reserved inventory. | 20 | 20 | JLCPCB SMT assembly | 1024 | https://jlcpcb.com/partdetail/C694544 | Conservative planning: max(20 installed, 5 minimum)+0 attrition. Exact order-page quantity controls.
USB_POWER | C3,C9,C10,C13,C14 | 5 | GRM32ER71A476ME15L | Murata | 47uF 10V X7R | SMT | C415541 | 741 | In stock (Extended) | 2026-09-26T08:48:43.101578+00:00 | https://jlcpcb.com/partdetail/C415541 | JLC stock is the dated observation, not reserved inventory. | 50 | 50 | JLCPCB SMT assembly | 741 | https://jlcpcb.com/partdetail/C415541 | Conservative planning: max(50 installed, 5 minimum)+0 attrition. Exact order-page quantity controls.
USB_POWER | R1 | 1 | RT0603BRD0724K9L | Yageo | 24.9k 0.1% | SMT | C136967 | 6436 | In stock (Extended) | 2026-09-26T08:44:47.056227+00:00 | https://jlcpcb.com/partdetail/C136967 | JLC stock is the dated observation, not reserved inventory. | 10 | 28 | JLCPCB SMT assembly | 6436 | https://jlcpcb.com/partdetail/C136967 | Conservative planning: max(10 installed, 20 minimum)+8 attrition. Exact order-page quantity controls.
USB_POWER | R7 | 1 | RT0603BRD07102KL | Yageo | 102k 0.1% | SMT | C861068 | 10762 | In stock (Extended) | 2026-09-26T08:48:43.101578+00:00 | https://jlcpcb.com/partdetail/C861068 | JLC stock is the dated observation, not reserved inventory. | 10 | 28 | JLCPCB SMT assembly | 10762 | https://jlcpcb.com/partdetail/C861068 | Conservative planning: max(10 installed, 20 minimum)+8 attrition. Exact order-page quantity controls.
USB_POWER | R8 | 1 | ERJ-3EKF1582V | Panasonic | 15.8k 1% | SMT | C403003 | 4503 | In stock | 2026-09-26 | https://jlcpcb.com/partdetail/C403003 | Applied D4: Same15.8k1%100ppm100mW0603; exactmanufacturerverified; JLCnormalizedERJ3EKF1582V in-stock. JLC stock is the dated observation, not reserved inventory. | 10 | 30 | JLCPCB SMT assembly | 4503 | https://jlcpcb.com/partdetail/C403003 | Conservative planning: max(10 installed, 20 minimum)+10 attrition. Exact order-page quantity controls.
USB_POWER | C11,C4,C5,C8 | 4 | GRM188R71E104KA01D | Murata | 100nF 25V | SMT | C77050 | 161914 | In stock (Extended) | 2026-09-26T08:44:22.612045+00:00 | https://jlcpcb.com/partdetail/C77050 | JLC stock is the dated observation, not reserved inventory. | 40 | 50 | JLCPCB SMT assembly | 161914 | https://jlcpcb.com/partdetail/C77050 | Conservative placeholder allowance; part-specific attrition/minimum must be resolved by JLC BOM matching.
USB_POWER | C12 | 1 | EEE-FK1E470P | Panasonic | 47uF 25V bulk | SMT | C178545 | 12963 | In stock (Extended) | 2026-09-26T08:48:43.101578+00:00 | https://jlcpcb.com/partdetail/C178545 | Panasonic catalog punctuation normalized: EEE-FK1E470P = EEEFK1E470P. JLC stock is the dated observation, not reserved inventory. | 10 | 11 | JLCPCB SMT assembly | 12963 | https://jlcpcb.com/partdetail/C178545 | Conservative planning: max(10 installed, 5 minimum)+1 attrition. Exact order-page quantity controls.
USB_POWER | U2,U3 | 2 | TPS2557DRBR | Texas Instruments | TPS2557DRB | SMT | C130056 | 1957 | In stock (Extended) | 2026-09-26T08:44:47.802232+00:00 | https://jlcpcb.com/partdetail/C130056 | JLC stock is the dated observation, not reserved inventory. | 20 | 20 | JLCPCB SMT assembly | 1957 | https://jlcpcb.com/partdetail/C130056 | Conservative planning: max(20 installed, 0 minimum)+0 attrition. Exact order-page quantity controls.
USB_POWER | R2,R3 | 2 | RT0603BRD0732K4L | Yageo | 32.4k 0.1% | SMT | C861323 | 22326 | In stock (Extended) | 2026-09-26T08:44:47.075233+00:00 | https://jlcpcb.com/partdetail/C861323 | JLC stock is the dated observation, not reserved inventory. | 20 | 30 | JLCPCB SMT assembly | 22326 | https://jlcpcb.com/partdetail/C861323 | Conservative placeholder allowance; part-specific attrition/minimum must be resolved by JLC BOM matching.
USB_POWER | C6,C7 | 2 | GRM31CR71A226KE15L | Murata | 22uF 10V | SMT | C91604 | 101994 | In stock (Extended) | 2026-09-26T08:44:46.359592+00:00 | https://jlcpcb.com/partdetail/C91604 | JLC stock is the dated observation, not reserved inventory. | 20 | 22 | JLCPCB SMT assembly | 101994 | https://jlcpcb.com/partdetail/C91604 | Conservative planning: max(20 installed, 5 minimum)+2 attrition. Exact order-page quantity controls.
USB_POWER | J2,J3 | 2 | 614004190021 | Würth Elektronik | USB-A 3A | MANUAL_THT | C6402847 | 426 | Exact loose part in stock; user-fit | 2026-09-26 | https://jlcpcb.com/partdetail/C6402847 | D6 exact MPN retained. Purchase separately as loose parts from the listed supplier; omit from JLC SMT assembly. | 20 | 24 | DigiKey | 4651 | https://www.digikey.com/en/products/detail/w%C3%BCrth-elektronik/614004190021/5956436 | 20 percent spares, rounded to supplier order multiple; combined across all board rows for this MPN; quantity shown only on first occurrence.
USB_POWER | U5,U6 | 2 | USBLC6-2SC6 | STMicroelectronics | USBLC6-2SC6 | SMT | C7519 | 45071 | In stock (Extended) | 2026-09-26T08:44:47.767981+00:00 | https://jlcpcb.com/partdetail/C7519 | JLC stock is the dated observation, not reserved inventory. | 20 | 22 | JLCPCB SMT assembly | 45071 | https://jlcpcb.com/partdetail/C7519 | Conservative planning: max(20 installed, 5 minimum)+2 attrition. Exact order-page quantity controls.
USB_POWER | U4 | 1 | TPS2513ADBVR | Texas Instruments | TPS2513ADBVR | SMT | C473910 | 37 | In stock (Extended); low stock | 2026-09-26T08:44:47.803234+00:00 | https://jlcpcb.com/partdetail/C473910 | JLC stock is the dated observation, not reserved inventory. | 10 | 10 | JLCPCB SMT assembly | 37 | https://jlcpcb.com/partdetail/C473910 | Conservative planning: max(10 installed, 5 minimum)+0 attrition. Exact order-page quantity controls.
MAIN_POWER | MAIN_POWER F1 insert,MAIN_POWER F2 insert | 2 | 028707.5PXCN | Littelfuse | 7.5 A / 32 VDC blade fuse | MANUAL_INSERT | C142688 | 1944 | Exact loose part in stock; user-fit | 2026-09-26 | https://jlcpcb.com/partdetail/C142688 | D6 exact MPN retained. Purchase separately as loose parts from the listed supplier; omit from JLC SMT assembly. | 20 | 24 | DigiKey | 21020 | https://www.digikey.com/en/products/detail/littelfuse-inc/028707-5PXCN/2519829 | 20 percent spares, rounded to supplier order multiple; combined across all board rows for this MPN; quantity shown only on first occurrence.
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

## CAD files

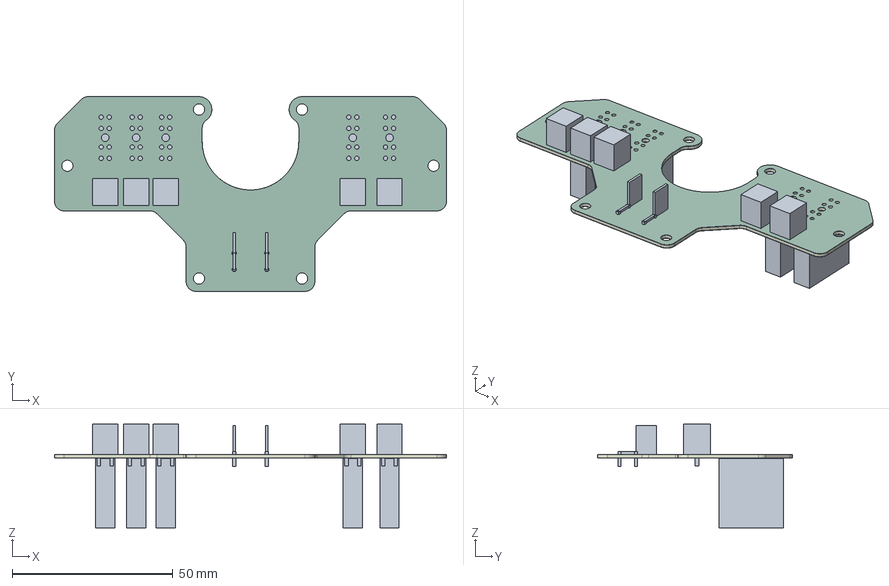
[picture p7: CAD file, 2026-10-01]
design/D8-2L-FASTON/MAIN_POWER/MAIN_POWER_D8_FASTON.step
121.8 x 60.5 x 32.3 mm
JST_VH_B2P-VH_ENVELOPE x 5
FASTON 63951-4 pair proxy
Littelfuse_FLR_1786165_BACKSIDE_ENVELOPE x 5
MAIN_POWER_soldermask x 2
MAIN_POWER_PCB

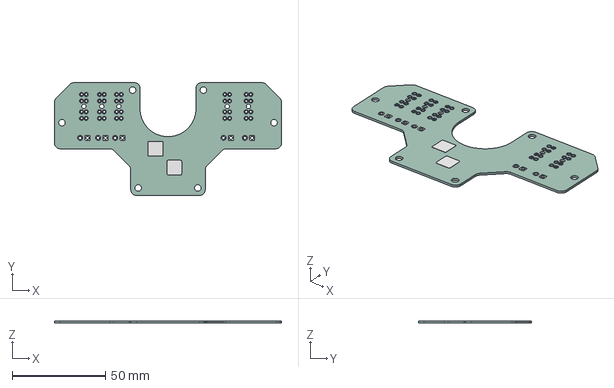
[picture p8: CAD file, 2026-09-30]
design/D8-2L/MAIN_POWER/verification/MAIN_POWER_D8_native.step
121.8 x 60.5 x 1.19 mm
MAIN_POWER_pad
MAIN_POWER_PCB

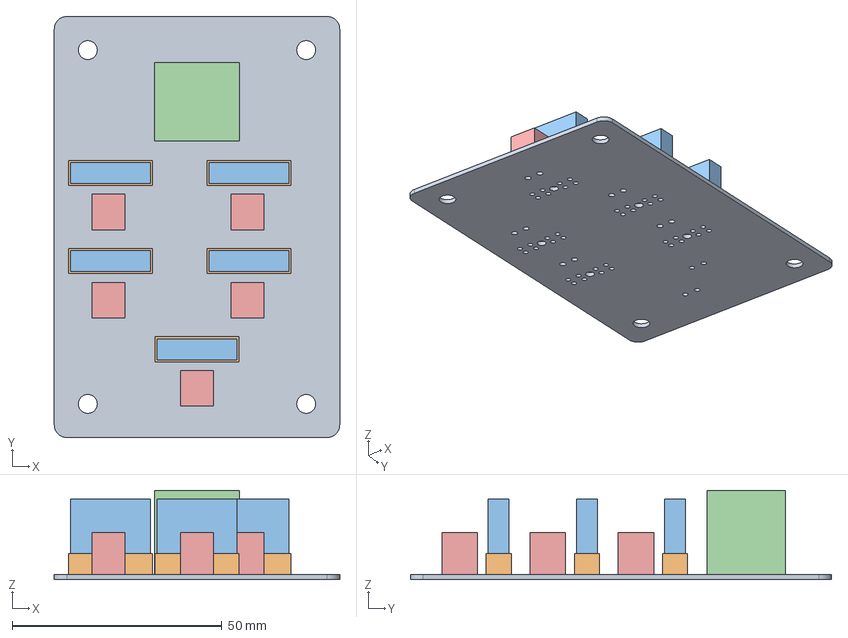
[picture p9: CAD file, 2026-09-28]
mechanical/D6/MAIN_POWER_D6_SIMPLIFIED.step
68.0 x 100.3 x 21.2 mm

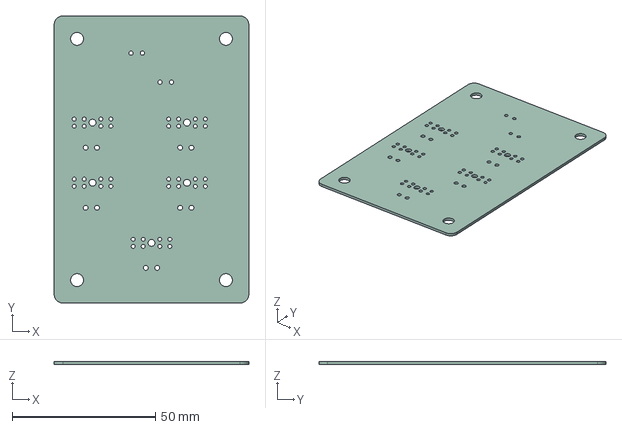
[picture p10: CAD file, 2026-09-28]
tools/step-native-inputs/MAIN_POWER_D6_BARE.step
68.0 x 100.3 x 1.04 mm

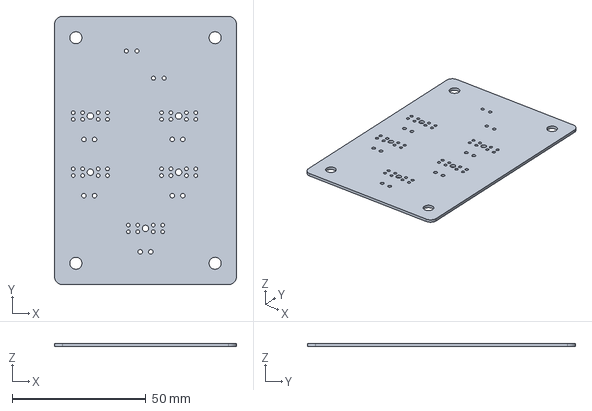
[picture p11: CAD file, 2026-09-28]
mechanical/D6/MAIN_POWER_D6_BARE.step
68.0 x 100.3 x 1.20 mm

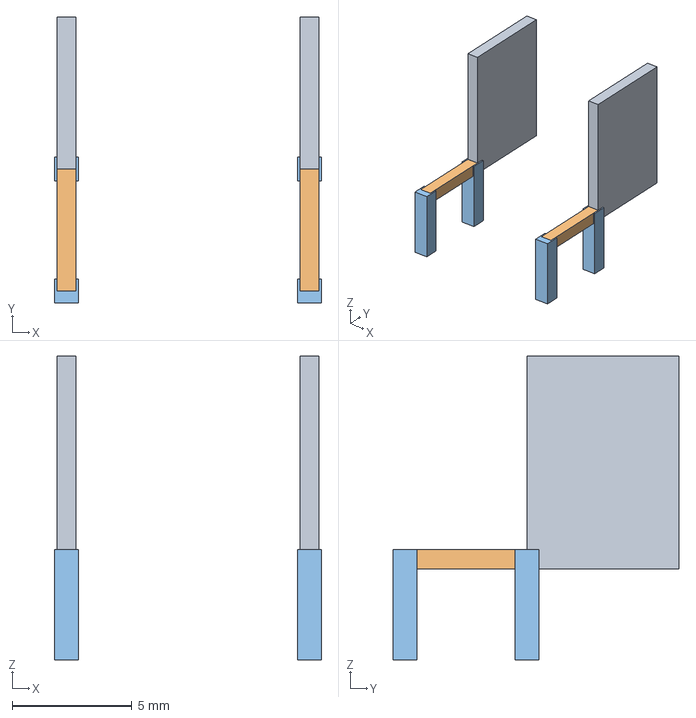
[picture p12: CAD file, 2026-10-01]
design/D8-2L-FASTON/MAIN_POWER/3d/FASTON_63951-4_PAIR_PROXY.step
11.2 x 11.9 x 12.7 mm

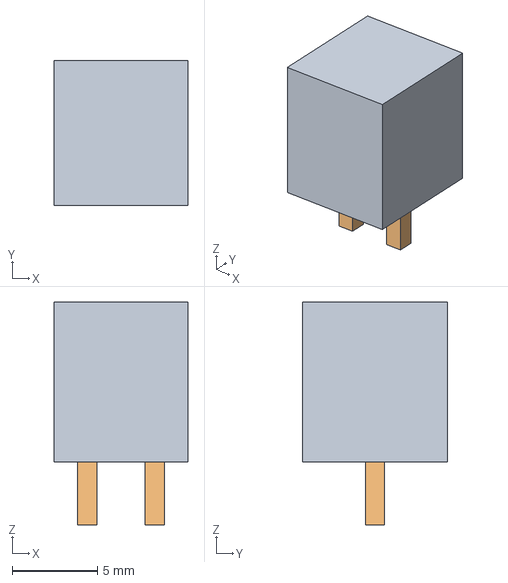
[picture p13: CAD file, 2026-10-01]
design/D8-2L/MAIN_POWER/3d/JST_VH_B2P-VH_ENVELOPE.step
7.86 x 8.50 x 13.1 mm

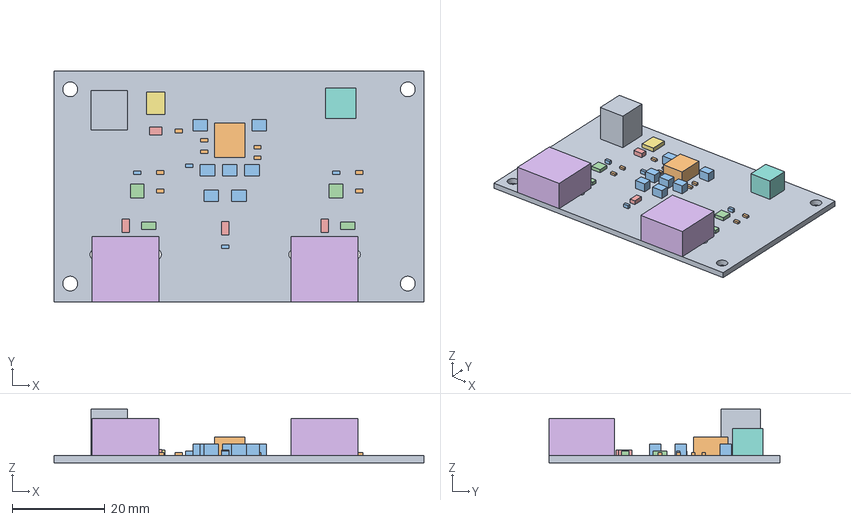
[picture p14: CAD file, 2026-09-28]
mechanical/D6/USB_POWER_D6_SIMPLIFIED.step
80.0 x 50.0 x 11.6 mm

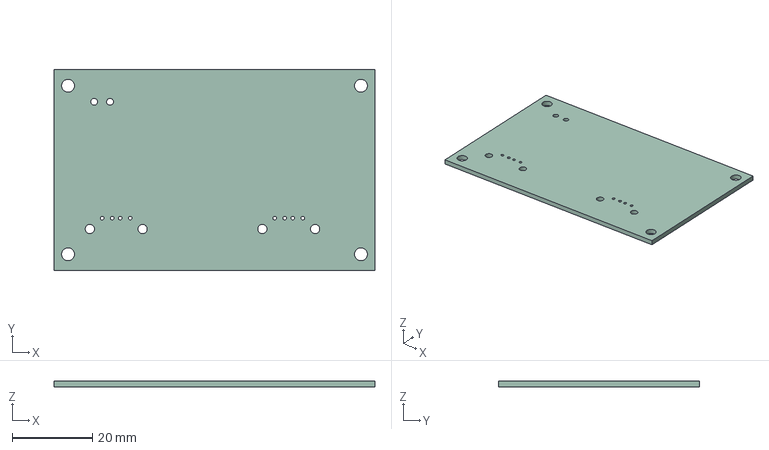
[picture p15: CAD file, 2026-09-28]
tools/step-native-inputs/USB_POWER_D6_BARE.step
80.0 x 50.0 x 1.44 mm
USB_POWER_PCB x 2

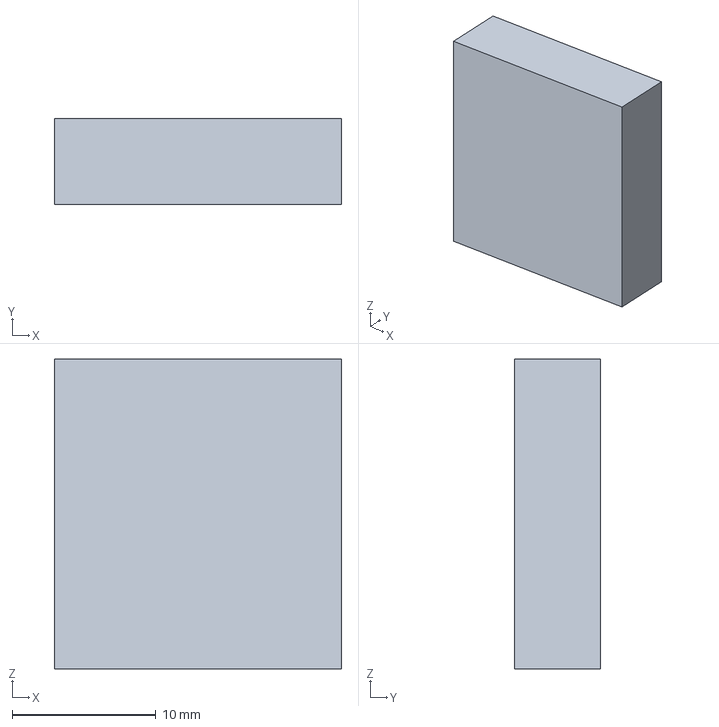
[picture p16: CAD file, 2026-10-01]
design/D8-2L-FASTON/MAIN_POWER/3d/Littelfuse_FLR_1786165_BACKSIDE_ENVELOPE.step
20.0 x 6.00 x 21.6 mm

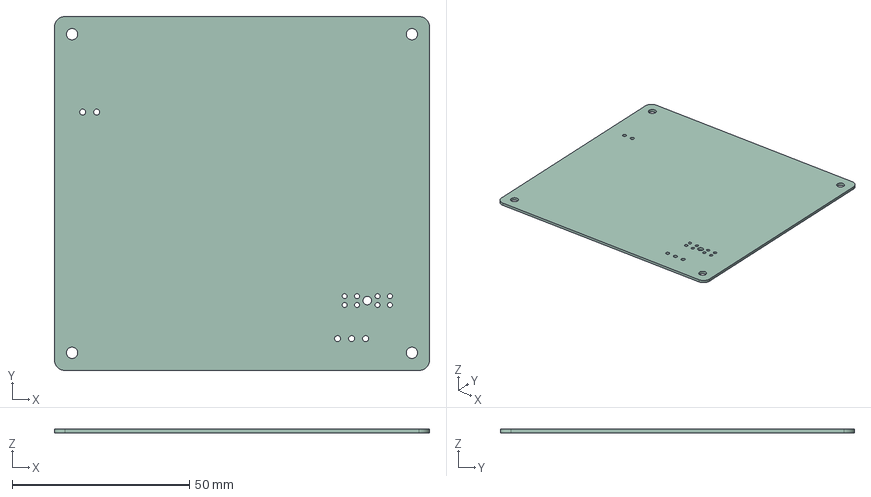
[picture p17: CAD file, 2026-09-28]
tools/step-native-inputs/POE_POWER_D6_BARE.step
106.0 x 100.0 x 1.04 mm

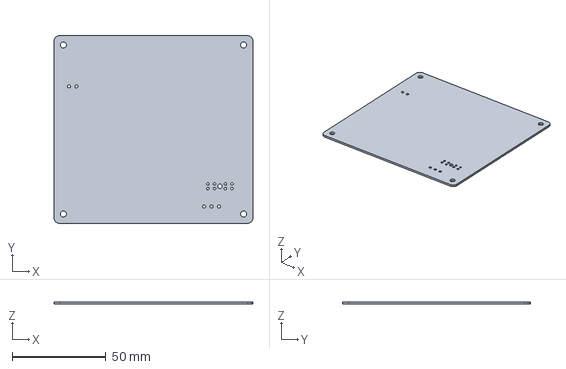
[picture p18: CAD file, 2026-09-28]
mechanical/D6/POE_POWER_D6_BARE.step
106.0 x 100.0 x 1.20 mm

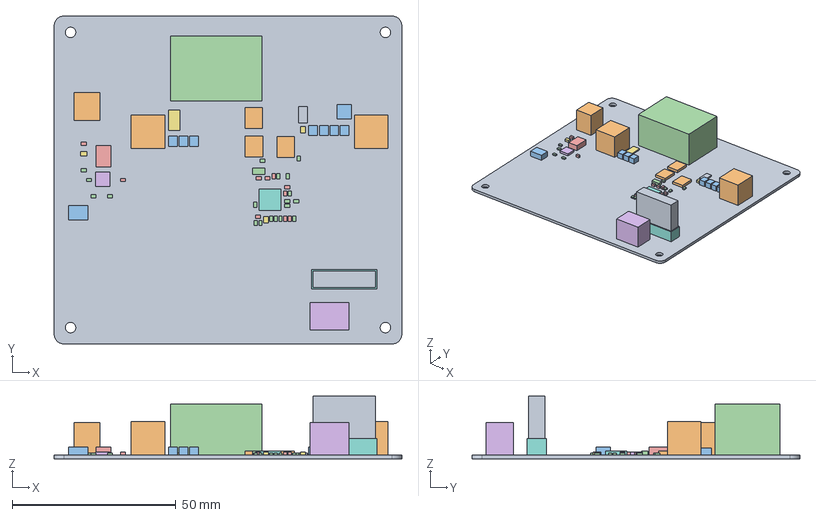
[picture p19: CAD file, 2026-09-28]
mechanical/D6/POE_POWER_D6_SIMPLIFIED.step
106.0 x 100.0 x 19.2 mm

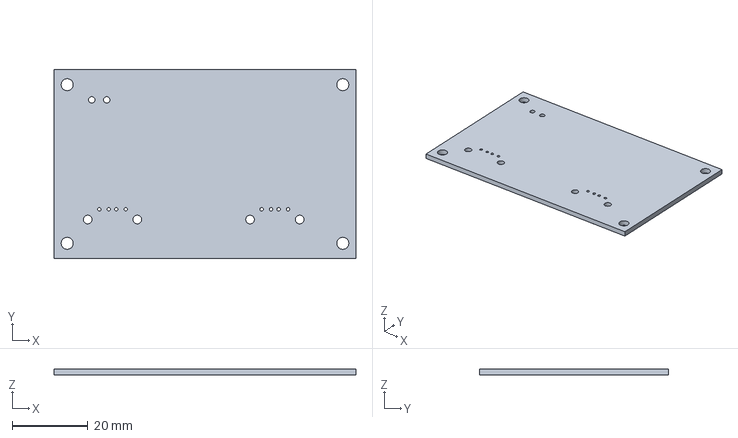
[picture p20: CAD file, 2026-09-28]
mechanical/D6/USB_POWER_D6_BARE.step
80.0 x 50.0 x 1.60 mm

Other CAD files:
design/D8-2L/MAIN_POWER/MAIN_POWER_D8.step
design/D8-2L/MAIN_POWER/3d/Littelfuse_FLR_1786165_ENVELOPE.step
design/D8-2L-FASTON/MAIN_POWER/3d/Littelfuse_FLR_1786165_ENVELOPE.step
design/D8-2L-FASTON/source/10052907_AA-UMI POWER PCB OUTLINE V2.dxf
design/D8-2L-FASTON/source/10052907_AA-UMI POWER PCB OUTLINE V2_1.dxf
design/D8-2L-FASTON/source/10052938_AA-UMI POWER PCB OUTLINE V3.dxf
design/D8-2L/MAIN_POWER/verification/MAIN_POWER_D8_with_previous_J1_terminal.step
design/D8-2L/source/10052907_AA-UMI POWER PCB OUTLINE V2.dxf
design/D8-2L/source/10052907_AA-UMI POWER PCB OUTLINE V2_1.dxf
design/D8-2L/source/10052938_AA-UMI POWER PCB OUTLINE V3.dxf

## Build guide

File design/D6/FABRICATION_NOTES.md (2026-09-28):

# D6 fabrication instructions

Use separate builds for MAIN (1.2 mm), POE (1.2 mm) and USB (1.6 mm). All are four-layer ENIG, 2 oz outer and 1 oz inner copper; green soldermask and white legend. Maintain exact outlines and mounting holes. Use the source stackup and MANUFACTURING_SPECIFICATION.md; quote any stackup change explicitly.

POE and USB require epoxy resin-filled, copper-capped vias at all positions marked in manufacturing/VIA_TREATMENT.csv. This is a coordinate schedule, not a drill program. Plot coordinates share the Gerber/drill origin; Y is inverted relative to KiCad coordinates. Drill files remain authoritative for hole geometry. Corresponding KiCad via objects explicitly carry filling/capping flags. Filling is not tenting or soldermask plugging.

POE smaller vias (0.254, 0.35 and 0.40 mm) are filled/capped. Its 0.635 mm vias are ordinary plated vias and must not be included in the fill process. USB 0.25/0.30 mm vias are filled/capped. MAIN has no vias requiring this process. All through-hole component and mounting holes remain open.

The POE Coilcraft SER2915H-103KL inductor requires an assembly support fixture. Include it in the SMT quotation. Assemble only the SMT BOM/CPL; connectors, holders and inserts are user-fitted. Preserve the original footprint pad geometry and paste openings. Review every supplier rotation/pin-1 preview before accepting assembly.

The requested construction has published capability support, but the exact selective-fill/copper/thickness combination and fixture still require manufacturer engineering acceptance. No quote is represented as accepted.

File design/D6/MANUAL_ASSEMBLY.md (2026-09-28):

# D6 manual assembly and harness parts

The batch is **ten MAIN_POWER, ten POE_POWER and ten USB_POWER boards**, forming ten systems. Use each board's BOM_by_reference.csv for board-mounted through-hole parts. The single consolidated UMI_COMPONENT_SOURCING.xlsx list includes inserts and cable-side parts; do not count holders as inserts.

| Position | Insert | Rating | JLC reference | Installed quantity for ten systems |
|---|---|---|---|---:|
| Main F1/F2 | Littelfuse 028707.5PXCN | 7.5 A, 32 V DC | C142688 | 20 |
| Main F3 | Littelfuse 0287001.PXCN | 1 A, 32 V DC | C142679 | 10 |
| Main F4 | Littelfuse 0287005.PXCN | 5 A, 32 V DC | C142682 | 10 |
| Main F5 | Littelfuse 0287010.PXCN | 10 A, 32 V DC | C142683 | 10 |
| POE F6 | Littelfuse 166.7000.4302 | 3 A, 80 V DC | C3662004 | 10 |

All six system holders are Littelfuse **178.6165.0002**, JLC C207061: sixty installed holders. The suffix identifies a manufacturer packaging option; holder geometry and 80 V rating are unchanged. The 287-series 32 V inserts retain standard ATO fit and 1 kA breaking rating. The FKS 80 V insert retains the compatible ATO/FKS format and 1 kA breaking rating. Never substitute a 32 V insert on the 53.5 V switch output.

F6 is now sourced as an exact loose part from DigiKey, with 378 pieces observed on 26 September 2026. Buy twenty: ten fitted plus ten spares. Littelfuse notice A0377 confirms obsolescence (last order 6 August 2026; last shipment 30 December 2026). Stock is not reserved. This batch can use remaining stock; a future revision needs a lifecycle replacement.

JLC parts-library stock is for PCBA use and cannot simply be shipped loose. The listed codes do not mean loose fuse inserts, holders or harness parts will arrive with the boards. Source manual parts separately from the exact LCSC/DigiKey links in the consolidated list; the user fits these parts. No JLC loose-parts shipment is assumed.

MAIN and POE thickness remains 1.2 mm, below the holder's 1.5 mm limit. USB remains 1.6 mm. The JST header drawing uses 1.6 mm PCB; verify seating, retention and excess lead protrusion on the thinner MAIN and POE boards. Input terminal J1 retains Phoenix 1709681, available as an exact loose part from DigiKey; no alternate terminal footprint was adopted.

Cable housings for MAIN J2–J6, POE J1 and USB J1 change to **JST VHR-2N-BK**, a black colour variant of VHR-2N with unchanged mating geometry: seventy housings for ten systems. POE switch connector uses VHR-3N, with contacts only in positions 1 and 3; position 2 remains empty. Confirm pin 1 positive and return using final numbered pads and the pin schedule before terminating any harness.

JST SVH-41T-P1.1 accepts AWG20–16 with the specified insulation diameter. For thinner fan wires use the compatible SVH-21T-P1.1 (AWG22–18) and adjust counts. Use appropriate crimp tooling and retention/pull checks; do not tin conductors before crimping. Housing/terminal catalogue availability is not a completed cable assembly.

Installed quantities exclude spares, purchasing pack multiples, device-end plugs, supply-input cable, mounting hardware and enclosure-specific lengths. Interboard cable length remains provisional; verify it in the enclosure. Provide upstream cable protection appropriate to the actual supply-input wire and installation. Branch fuses do not protect a short before the PCB.

The manufacturer time-current curves and typical temperature derating support the selected ratings, but nuisance-opening, contact-temperature and startup checks remain required at 40 °C. Fuse clearing alone does not establish semiconductor short-circuit survival. No physical bring-up or thermal tests have been performed by the software agent.

Sources: [Littelfuse287 ATOF](https://www.littelfuse.com/assetdocs/littelfuse-datasheet-287-atof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), [LittelfuseFKS80 manufacturer-sheet mirror](https://xonstorage.z8.web.core.windows.net/pdf/littelfuse_16670004402_apr22_xonlink.pdf), [FLR holder manufacturer-sheet mirror](https://datasheet.octopart.com/178.6165.0001-Littelfuse-datasheet-8836287.pdf), [JST VH](https://www.jst-mfg.com/product/pdf/eng/eVH.pdf).

## Three-board wiring and configuration

MAIN J1 is the source12V input. MAIN J2Jetson,J3GMSL,J4fan,J5USB andJ6POE each use pin 1positive,pin 2GND. MAIN F5 protects the cable feeding POE J1. No duplicate POE input fuse is fitted. POE J6 is the53.5V output: pin 1positive,pin 2empty,pin 3GND. MAIN J6 and POE J6 have different voltages: label by board name and voltage.

PoE switch and GMSL must never be used in the same configuration. This is a manual configuration constraint, not interlocked hardware. Test the two permitted configurations separately. All six fuses remain; no removal is approved based on the lower combined power budget.

Each complete three-board set now has seven two-position cable housings (five MAIN outputs plus POE/USB inputs), one three-position POE output housing, and sixteen populated JST contacts if all connections use this scheme. For ten sets this is 70 two-position housings,10 three-position housings and160 contacts before spares. Select contact sizes for actual wires and reconcile the final consolidated harness BOM; device-end connectors remain installation-specific.

D6 fabrication detail: the five narrow POE OPT traces are now 0.16 mm; configured clearance remains 0.20 mm. MAIN visible small board legends are enlarged to 1 mm. Individual via filling/capping flags and the per-board VIA_TREATMENT.csv schedules identify selective epoxy fill and copper capping; 0.635 mm POE vias remain ordinary. See FABRICATION_NOTES.md.

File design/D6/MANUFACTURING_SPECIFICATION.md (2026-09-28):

# D6 fabrication and assembly specification — prototype

Prepare ten of each of three boards. Use only matched D6 source, Gerbers, drills, paste and placement files. Final D6 DRC and ERC checks pass on all three boards; the per-board verification reports and source hashes record the checked versions. No hardware qualification or approved manufacturing quote is claimed.

| Setting | MAIN_POWER | POE_POWER | USB_POWER |
|---|---|---|---|
|Outline|68×100.263962mm|106×100mm|80×50mm|
|Layers|4|4|4|
|Finished thickness|1.2mm|1.2mm|1.6mm|
|Outer copper|2oz|2oz|2oz|
|Inner copper|1oz|1oz|1oz|
|Finish|ENIG|ENIG|ENIG|
|Mask/legend|Green/white|Green/white|Green/white|
|SMT parts|0|53,top only|31,top only|
|Through-hole parts|11|3|3|
|Filled/capped vias|Not required|Required under solder pads|Required under solder pads|

Four copper layers are F.Cu,In1.Cu,In2.Cu,B.Cu. FR-4 Tg≥150°C requested; exact standard dielectric construction may be quoted provided total thickness and copper weights are retained. Do not silently substitute0.5oz inner copper. MAIN and POE thickness remains below the fuse holder's1.5mm PCB limit. USB requires a separate1.6mm build setting.

MAIN contains six connectors (Phoenix input plus five two-pin JST outputs) and five fuse holders, with no SMT. Its F.Cu/In1.Cu carry12V and In2.Cu/B.Cu GND, with solid connections. Fused branches use dual-outer3mm tracks except1mm fan. MAIN needs no VIPPO service. POE has SMT conversion/protection circuitry and three manual parts: J1input,F6holder,J6output. USB has31SMT and three manual connectors.

POE and USB solder-pad vias must be resin-filled and copper-capped. Tenting or soldermask plugging is not equivalent. Confirm stencil/thermal-pad treatment and the heavy Coilcraft inductor support fixture with the assembler. Reference the actual final drill files and board drawing; do not copy D4 geometry into the three-board build.

MAIN retains mounting centers(18,18),(70,18),(18,102.263962),(70,102.263962). POE has a separate mounting pattern defined by its delivered board/mechanical drawing. Manufacturing must use outline centerlines, not graphic stroke bounding boxes.

## Assembly handoff

Use per-board BOM_by_reference.csv, grouped BOM and the matching normalized supplier CPL. MAIN has no SMT placement operation. Raw KiCad local-footprint rotations are not substitutes for normalized CPL. Verify supplier preview against pin 1/polarity and reference drawings. Preserve D4 component choices, including POE R2's manufacturer lands and MOSFET substitution qualifications; do not use D4 paste/position files after the split.

Installed procurement totals131parts per three-board set including manual items, as tracked by the consolidated procurement files; quantities for ten sets must include separately agreed spare/attrition allowance. MAIN J1 uses its original exact MPN via loose procurement; POE R1 uses stocked Yageo RC2010JK-077R5L. Visible stock is not reserved stock. POE C1/L1 have limited stock headroom; F6 is sourced loose, with a purchase plan of twenty including ten spares.

JLC library parts are PCBA-only and cannot simply ship loose. Buy the exact loose manual parts from the suppliers in the consolidated list and fit them after JLC SMT assembly. Device-end plugs, final cable lengths and tooling remain installation-specific. No external order or physical testing is established by these documents. Follow ENGINEERING_AND_TEST_NOTES.md before device connection.

D6 fabrication detail: the five narrow POE OPT traces are now 0.16 mm; configured clearance remains 0.20 mm. MAIN visible small board legends are enlarged to 1 mm. Individual via filling/capping flags and the per-board VIA_TREATMENT.csv schedules identify selective epoxy fill and copper capping; 0.635 mm POE vias remain ordinary. See FABRICATION_NOTES.md.

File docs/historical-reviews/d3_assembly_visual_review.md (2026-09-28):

# D3 assembly and routing visual review

Final reference-only PDF/SVG overview and enlarged detail generated for both boards from their filled, saved D3 sources. Source hashes and annotation counts are recorded in each `review/*_assembly_review.json`; source files remained unchanged.

Main: 69 reference labels; boost control detail is readable with values removed, thin body outlines, and vertical lettering fitted inside narrow vertical passives. Main native snapshot05 has zero DRC violations, opens or schematic parity findings. The final bottom Gerber visual shows the long control route in a clean orthogonal corridor with short 45-degree transitions, and the broad distribution route has chamfered corners.

USB: 38 reference labels; overview identifies both connectors, mounting holes, diode and power sections without overlapping values. Buck detail is provided separately. Final bottom Gerber visual confirms the charging-signal shield-hole detour has been removed; the remaining pair has a short, orderly path and matched direction changes.

The assembly drawings intentionally show body outlines/reference designators, not solder pad numbering or manufacturer assembly orientation. Use normalized CPL, footprints and BOM for actual placement. Custom-body absence in 3D renders remains a known limitation.

Reusable command: `python work/export_reference_assembly.py BOARD --output-dir REVIEW_DIR --detail-box X0 Y0 X1 Y1`. It uses isolated text-only board copies and the controlled native CLI; copper and source placement are not modified.

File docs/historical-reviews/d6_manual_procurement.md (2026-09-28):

# D6 loose manual-part procurement

Ten three-board systems. Every specified board-mounted manual part, fuse insert and listed JST mating component has an exact-part source with observed stock exceeding the recommended quantity. No substitute footprints are needed for this batch. No order has been placed.

Quantities include 20% spares rounded to the selected supplier pack multiple, except the obsolete 80 V fuse: 10 installed plus 10 spares. Stock was checked on 26 September 2026 through supplier web pages; it is unreserved and may change.

| Exact MPN | Use | Installed | Buy | Supplier/code | Observed stock | MOQ / multiple |
|---|---|---:|---:|---|---:|---|
| 1709681 | MAIN J1 | 10 | 12 | [DigiKey exact part](https://www.digikey.com/en/products/detail/phoenix-contact/1709681/2511044) | 78 | 1 / 1 |
| 178.6165.0002 | MAIN F1-F5; POE F6 holders | 60 | 72 | [LCSC C207061](https://www.lcsc.com/product-detail/Fuse-Holders_Littelfuse-178-6165-0002_C207061.html) | 617 | 1 / 1 |
| B2P-VH(LF)(SN) | MAIN J2-J6; POE J1; USB J1 | 70 | 90 | [LCSC C160315](https://www.lcsc.com/product-detail/C160315.html) | 296,150 | 10 / 10 |
| B3P-VH(LF)(SN) | POE J6 | 10 | 15 | [LCSC C160316](https://www.lcsc.com/product-detail/C160316.html) | 31,215 | 5 / 5 |
| 614004190021 | USB J2,J3 | 20 | 24 | [DigiKey 732-10012-ND](https://www.digikey.com/en/products/detail/w%C3%BCrth-elektronik/614004190021/5956436) | 4,651 | 1 / 1 |
| 028707.5PXCN | MAIN F1,F2 inserts 7.5A32V | 20 | 24 | [DigiKey F4198-ND](https://www.digikey.com/en/products/detail/littelfuse-inc/028707-5PXCN/2519829) | 21,020 | 1 / 1 |
| 0287001.PXCN | MAIN F3 insert 1A32V | 10 | 15 | [LCSC C142679](https://www.lcsc.com/product-detail/C142679.html) | 3,750 | 5 / 5 |
| 0287005.PXCN | MAIN F4 insert 5A32V | 10 | 15 | [LCSC C142682](https://www.lcsc.com/product-detail/PTC-Fuse_Littelfuse_0287005-PXCN_5A-32V_C142682.html) | 5,895 | 5 / 5 |
| 0287010.PXCN | MAIN F5 insert 10A32V | 10 | 15 | [LCSC C142683](https://www.lcsc.com/product-detail/C142683.html) | 14,670 | 5 / 5 |
| 166.7000.4302 | POE F6 insert 3A80V | 10 | 20 | [DigiKey exact part](https://www.digikey.com/en/products/detail/littelfuse-inc/166-7000-4302/2515899) | 378 | 1 / 1 |
| VHR-2N-BK | Two-position cable housings | 70 | 90 | [LCSC C595405](https://www.lcsc.com/product-detail/C595405.html) | 30,640 | 10 / 10 |
| VHR-3N | POE output cable housing; middle cavity empty | 10 | 20 | [LCSC C157899](https://www.lcsc.com/product-detail/C157899.html) | 49,960 | 10 / 10 |
| SVH-41T-P1.1 | AWG20-16 cable contacts; gauge must match actual wires | 160 | 200 | [LCSC C160350](https://www.lcsc.com/product-detail/C160350.html) | 136,100 | 100 / 100 |

## Procurement decisions

- Phoenix 1709681: exact part available from DigiKey (78 observed). Buy 12; JLC preorder is unnecessary for hand assembly.
- F6 166.7000.4302: exact 3 A / 80 V part available from DigiKey (378 observed). Buy 20. Do not replace it with a 32 V insert.
- F6 lifecycle is now established: [Littelfuse notice A0377, hosted by TTI](https://www.ttieurope.com/content/dam/tti-europe/products/PCN/Littelfuse/Littelfuse-A0377.pdf) names this part, with last order 6 August 2026 and last shipment 30 December 2026. DigiKey also marks it obsolete. This corrects the earlier D5 statement that manufacturer obsolescence was not established.
- JST two-position headers and housings: 84 pieces would provide 20% spares, but the selected LCSC listings sell in multiples of 10, so buy 90.
- LCSC is preferred where its exact loose-part page was readable. DigiKey is the fallback for Phoenix, USB-A receptacles, 7.5 A inserts and the 80 V insert. These links concern loose procurement, not JLC assembly inventory.

## Remaining installation details

- Device-end plugs, wire lengths, source-input cable/protection, mounting hardware and crimp-tool arrangement remain installation-dependent.
- 160 contacts assumes all 16 contacts per system use SVH-41T-P1.1. If thinner fan leads require SVH-21T-P1.1, split quantities after wire selection.
- No purchases, baskets or board edits were made.

The holder suffix .0002 denotes the 500-piece manufacturer package; the selected LCSC listing allows individual pieces. Do not confuse a manufacturer full-pack size with the retailer minimum order.

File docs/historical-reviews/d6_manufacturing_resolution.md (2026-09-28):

# D6 manufacturing resolution review

Read-only review of D5 sources and official JLCPCB pages, 26 September 2026. No PCB edits, uploads, messages or orders were made.

Subsequent authorized action: repaired D6 MAIN/POE stackup names and widened five POE OPT tracks to 0.20 mm; changed POE minimum track rule to 0.16 mm. USB already had correct stackup metadata and was unchanged. Audit: `work/d6_manufacturing_repairs.json`. Root owns subsequent refill/DRC; this report does not claim the widened tracks passed until that check returns.

## Ordering specification that preserves the electrical design

| Board | Quantity | Construction | Assembly |
|---|---:|---|---|
| MAIN_POWER | 10 | 4 layers, 1.2 mm, 2 oz outer / 1 oz inner, ENIG, green mask | Bare PCB; 11 user-fit through-hole parts |
| POE_POWER | 10 | 4 layers, 1.2 mm, 2 oz outer / 1 oz inner, ENIG, green mask; epoxy-filled and copper-capped solder-pad vias | Top-side SMT, 53 placements; heavy-inductor carrier/fixture required; 3 user-fit parts |
| USB_POWER | 10 | 4 layers, 1.6 mm, 2 oz outer / 1 oz inner, ENIG, green mask; epoxy-filled and copper-capped solder-pad vias | Top-side SMT, 31 placements; 3 user-fit connectors |

These options have published support individually. The exact combination still requires the order configurator/engineering quotation; this review does not establish an accepted quote. Do not substitute the default 0.5 oz inner copper or convert the 1.2 mm boards to 1.6 mm: the fuse-holder limit drove their thickness. Use routed individual outlines. Ask the assembler to add removable handling rails if needed rather than alter the delivered mounting holes. JLC's stackup selector exposes four-layer, 1.2/1.6 mm, 2 oz outer and 1 oz inner options. [Official stackup selector](https://jlcpcb.com/impedance)

## Concrete source discrepancies to resolve in D6

1. **MAIN and POE inner copper stackup naming is wrong.** Their enabled layer tables and Gerbers have four copper layers, but the saved stackup calls the two 0.035 mm copper layers `dielectric 2` and `dielectric 4`, with dielectric material properties. Name them `In1.Cu` and `In2.Cu`, retain copper thickness, and use three actual dielectric entries. USB's stackup is correctly named. This is a metadata repair, not an instruction to reroute. Reopen/save and recheck the persisted stackup and total thickness before final export.
2. **POE has five 0.15 mm F.Cu OPT tracks.** JLC's capability table permits 0.15 mm for two-ounce multilayers, but its newer copper-weight guide specifies 0.16 mm, while the FR4 product page says 0.16 mm width / 0.20 mm spacing. Treat this as a conflicting published limit, not proof of rejection. The conservative resolution is widen the five tracks to at least 0.16 mm and rerun DRC at 0.20 mm clearance where feasible. Locations are in `work/d6_geometry_stats.json`, around X125–128, Y68–69. MAIN minimum actual width is 1 mm; USB is 0.20 mm. [Copper-weight guide](https://jlcpcb.com/help/article/jlcpcb-copper-weight), [FR4 product specification](https://jlcpcb.com/pcb-fabrication/fr4-pcb)
3. **Saved POE/USB via fabrication flags say filling/capping off.** The written fabrication specification requires filled/capped pad vias; the KiCad flags and generic tenting defaults do not encode that instruction. Ensure the fabrication drawing/order explicitly requests epoxy-filled, copper-capped VIPPO and identifies only the relevant hole sizes. Tenting and soldermask plugging are not interchangeable with that process. POE also has 0.635 mm ordinary power vias, outside the published 0.55 mm filling range; do not ask to fill every via blindly. USB holes are 0.25/0.30 mm. POE smaller via holes are 0.254/0.35/0.40 mm. [Official via-covering explanation](https://jlcpcb.com/help/article/pcb-via-covering)
4. **MAIN has thirteen visible board-level labels/symbols below 1 mm height.** Examples include the 0.85 mm fuse warning and 0.9 mm polarity marks. Increase important visible legends to 1 mm where space permits and recheck silkscreen clearance. The published guide recommends 1 mm text and 0.15 mm stroke. Treat this as legibility improvement, not an electrical defect. [Capabilities](https://jlcpcb.com/capabilities/Capab)

Current PTH pad annuli checked against 0.254 mm have no failures. USB's smallest vias are 0.45/0.25 mm, POE's 0.508/0.254 mm; these satisfy published drill/diameter capability. Via limits differ from through-hole component pad annular requirements. Existing native DRC is valuable but does not prove all manufacturing process choices, mask bridges, fixture requirements or stackup acceptance.

## Assembly and ten-board inventory

JLC's exact **SER2915H-103KL / C19276042** product listing explicitly calls for an assembly fixture. Keep that fixture in the POE quotation; do not omit L1 from the CPL or assume top-only placement eliminates the requirement. The general fixture guidance also covers mechanical support during assembly. [Exact JLC inductor listing](https://jlcpcb.com/partdetail/Coilcraft-SER2915H103KL/C19276042), [Fixture policy](https://jlcpcb.com/help/article/pcb-assembly-fixtures)

The consolidated list's 1,310 pieces are installed quantities for ten full sets, not purchase quantities. Require the assembler's part-specific minimum and attrition quantities in its quote. Do not invent a universal percentage. Existing observations leave five spare C1 capacitors (15 stock for 10), seven inductors (17 for 10), and zero spare 80 V F6 fuse inserts (10 for 10). These buffers are not reservations. F6 is manually fitted; its spare need is separate from SMT attrition. [Assembly minimum/attrition policy](https://jlcpcb.com/help/article/pcb-assembly-faqs-part-2)

Root's later public metadata gives C1 minimum5/loss4 and L1 minimum0/loss0: ten placements suggest14 C1 and10 L1 under either common arithmetic interpretation. The official public pages do not specify whether loss is added before or after the minimum is applied. For installed10/minimum20/loss10, plausible totals are20 or30. Use30 only as a clearly labeled conservative planning allowance pending the supplier's actual BOM-match quantity; do not call that formula verified JLC policy. The metadata refresh did not supply live stock counts for every part, so the dated D5 stock observations must remain labeled as such.

MAIN J1 Phoenix 1709681 and POE R1 ERJ-12ZYJ7R5U remain exact-part preorder items, not stocked items. R1's recorded minimum is 734 pieces for a ten-piece installed requirement; price/arrival and inventory acceptance must be confirmed before committing. No need to introduce an unvalidated replacement solely to avoid that minimum. Preordered stock can be assembled only once received. [Preorder terms](https://jlcpcb.com/help/article/pre-ordering-parts-terms-conditions)

Keep the authorized user-fit route for connectors, holders, fuse inserts and harness parts. JLC component-library inventory is for PCBA, so it is not an ordinary loose-parts supply. Practical paths are independent authorized-distributor/LCSC purchase for manual parts, or an explicitly agreed JLC through-hole/hand-assembly service. Cable crimping and fuse insertion need a specific scope; merely selecting a library code is insufficient. The inductor listing itself states the PCBA-only restriction.

## Release decision

Complete the file corrections above, refill/revalidate/export D6, obtain a quote retaining copper/stackup/VIPPO/fixture requirements, and reconcile actual purchasable quantities including attrition. These steps can make the package manufacturing-review ready. Physical converter stability, thermal, overload and real-device tests remain prototype qualification; an accepted fabrication order would not complete them.

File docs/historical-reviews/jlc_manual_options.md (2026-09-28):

# Manual-part JLC options, 10 main boards

Checked 2026-09-26. Raw live catalogue metadata: `work/jlc_manual_info.json`. Stock counts are not reservations. The `canPresaleNumber` field was correlated with displayed available-order quantity on several parts but is not a universal assembly guarantee; root browser confirmed XT60PW-M requires preorder despite visible stock.

## Approved packaging-only holder substitution

Replace 178.6165.0001 with **178.6165.0002**, JLC **C207061**. Stock617, available-order field514; need60 plus spares. Manufacturer FLR drawing identifies suffix1 as100-pack, suffix2 as500-pack, both complete178.6165.000_ holder. Same80V construction, geometry and PCB thickness limit. No footprint change.

[JLC](https://jlcpcb.com/partdetail/Littelfuse-178_61650002/C207061), [manufacturer drawing mirror](https://datasheet.octopart.com/178.6165.0001-Littelfuse-datasheet-8836287.pdf).

## Input terminal

No verified stocked same-footprint replacement for Phoenix1709681 was found. Original is MKDS10HV/2-ZB-10,16,76A, four zigzag pins (two per potential), not an ordinary two-pin terminal.

**Phoenix1711725 C89120**, MKDS3/2-5,08: live stock2573, order-field2486. Manufacturer24A400V, AWG12 capability. Candidate for nominal20A bus, requiring enclosure40C thermal check and conductor selection. Package change: two pins at0,0 and5.08,0 instead of original four-pin arrangement. Stock KiCad footprint `TerminalBlock_Phoenix:TerminalBlock_Phoenix_MKDS-3-2-5.08_1x02_P5.08mm_Horizontal` has2.6mm copper pads,1.3mm drill,10.2×11.2mm body. Assign polarity consistently with board labels; connector itself is not electrically polarized. This is a localized connector and input-copper change, not a drop-in.

[Manufacturer](https://www.phoenixcontact.com/en-us/products/printed-circuit-board-terminal-mkds-3-2-508-1711725), [JLC](https://jlcpcb.com/partdetail/PhoenixContact-1711725/C89120).

XT60PW-M C98732 had8898 displayed stock but root browser confirmed preorder minimum17,14-day lead; not an immediately available alternative.

## Fuse inserts and redesign option

ESKA exact inserts remain unverified in JLC. ATO7.5A Littelfuse0ATO07.5V C1664994 has zero live stock. FKS80V3A166.7000.4302 C3662004 has exactly10 stock/orderable, covering10 boards with no spares; distributor lifecycle warnings were found, but current manufacturer lifecycle was not confirmed. OptiFuseANR80-UL-3A C3662026 has zero. Do not replace53.5V branch fuse with32V fuse.

A feasible alternative retaining replaceability is Littelfuse154 OMNI-BLOK SMT fuse+holder family:

| Rating | MPN | JLC | Live stock/order-field |
|---|---|---|---|
|3A|0154003.DR|C206912|1760/1743|
|10A|0154010.DR|C206921|2331/2276|
|5A|0154005.DR|C206916|Related-product stock3693; detail not yet checked|
|1A|0154001.DR|C206908|Related-product stock1822; detail not yet checked|

Holder125V10A, body9.73×5.03mm, easy fuse replacement. One common new SMT land pattern could replace all six holders, shrinking footprint and manual work. Family offers7A and8A, not7.5A; F1/F2 current choice and time-current coordination need review. Standard154 uses fast453 series; 3A nominal I²t1.65 A²s versus oldFKS8.1, interrupt50A@125VDC versusATO1kA. Available source fault current, capacitor discharge, startup and40C derating must be checked before accepting. Current finding is a redesign candidate, not a completed qualified substitution.

[Manufacturer154](https://www.littelfuse.com/assetdocs/littelfuse-fuse-154-series-data-sheet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), [manufacturer451/453](https://www.littelfuse.com/~/media/electronics/datasheets/fuses/littelfuse_fuse_451_453_datasheet.pdf.pdf), [3A JLC](https://jlcpcb.com/partdetail/Littelfuse-0154003DR/C206912).

## Exact shunt land correction

Manufacturer MA Rev30 page8 visually inspected (`work/datasheets/everohms_ma.pdf`, `ma_land.png`), matching latest Rev34 indexed table. For MA2512 2–5mOhm, recommended a=2.60,b=3.68,i=2.55mm, where drawing labels pad-length a, pad-height b, gap i.

Use two rectangular pads **2.60×3.68mm centered(−2.575,0),(+2.575,0)** in unrotated local coordinates, then apply existing footprint rotation. Preserve existing net assignment and Kelvin connections at inner pad edges. Old generic2512 has1.225×3.35mm pads centered±2.9625, so new pads add0.30mm outward and1.075mm inward per side,0.165mm vertically. DRC and sense-route review required. New overall copper width7.75mm, gap2.55mm. No board edits made in this stream.

[Manufacturer Rev34](https://www.everohms.com/data/10000/ftp/S-10-12-05-34.pdf), [visually inspected manufacturer Rev30 mirror](https://uploadcdn.oneyac.com/attachments/files/brand_pdf/%E5%A4%A9%E4%BA%8C/3E/19/MA.pdf).

## Final selected insert set — supersedes unresolved insert findings above

All retain existing ATO/FKS holders; no Nano2 change is recommended.

| Ref | Littelfuse MPN | JLC | Live stock / order field | Needed for10boards |
|---|---|---|---:|---:|
|F1,F2|028707.5PXCN|C142688|1944 /1944|20|
|F3|0287001.PXCN|C142679|3722 /3722|10|
|F4|0287005.PXCN|C142682|3448 /3447|10|
|F5|0287010.PXCN|C142683|14671 /14665|10|
|F6|166.7000.4302|C3662004|10 /10|10, no spares|

Manufacturer287 datasheet verifies32VDC/1kA interruption,19.1×5.1×18.8mm ATO envelope,5.2mm blade width,6.5mm exposed length,14.5mm outer blade span. Standard ATO holder fit is supported. PXCN is2000 bulk packaging code, not minimum purchase quantity. Manufacturer ratings table explicitly lists7.5A as028707.5_, not0287007_.

[Manufacturer current287 datasheet](https://www.littelfuse.com/assetdocs/littelfuse-datasheet-287-atof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). [Manufacturer older curve/temperature sheet](https://www.littelfuse.com/~/media/automotive/datasheets/fuses/passenger-car-and-commercial-vehicle/blade-fuses/littelfuse_atof_datasheet.pdf) lists135% opening0.35–600s for1/2A and0.75–600s for3–40A;200%0.1–5s for1/2A and0.15–5s for3–40A. Typical ambient load table at65C:7.5A fuse6A load,5A fuse4A load,10A fuse8A load, supporting intended5A/4A branch,~3AUSBinput and~6.5Aboostinput at40C with startup validation still required. This is not a precise trip-current guarantee.

F6 was previously verified against manufacturerFKS80V drawing/curve inwork/fuse_verification.json andfks80_verified.pdf. Root approved conditional use of ten available pieces for ten hand-inserted boards, subject to actual reservation/supply and no-spares disclosure. Do not claim current manufacturer obsolete status without evidence. JLC loose-insert supply/installation arrangement must be confirmed: catalogue stock alone does not mean loose parts will ship with assembled boards.

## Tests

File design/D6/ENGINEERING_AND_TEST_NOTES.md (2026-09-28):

# UMI D6 — engineering and prototype test notes

## The three boards

**MAIN_POWER** is a passive 12 V distribution board. **POE_POWER** is the separate protected 53.5 V boost board. **USB_POWER** supplies two current-limited USB-A charging sockets from its fused 12 V feed.

D6 is prepared for ten of each of the three boards. Final D6 native checks pass on all three boards: zero DRC violations, unconnected items, schematic parity issues and ERC violations. See each board’s verification folder. These are untested prototype designs.

MAIN is68×100.263962mm, POE106×100mm and USB80×50mm. MAIN preserves four mounting-hole centers at(18,18),(70,18),(18,102.263962),(70,102.263962) in design coordinates. Use each board's Edge.Cuts and mechanical drawing for enclosure design; the separate POE board has its own mounting pattern.

## Electrical design envelope

| Item | Design basis |
|---|---|
| External source | Mean Well RSP-320-12, nominal 12 V, 26.7 A; mains wiring is external to these PCBs |
| Enclosure ambient | Maximum 40 °C, as specified by the user |
| Jetson branch | 12 V, 5 A allowance |
| SG4A branch | 12 V, 4 A allowance |
| Fan branch | 12 V, 0.14 A nominal |
| Switch branch | 53.5 V, 1.31 A, approximately 70.1 W |
| USB board | Two charge-only USB-A outputs, 3 A electrical-load design target per socket |
| Interboard harness | Provisional maximum 1 m one-way, AWG16 copper pair; actual length was not supplied |
| Environment | Dry indoor enclosure; no claim of automotive, outdoor or medical qualification |

**The PoE switch and SENSING GMSL configurations are mutually exclusive.** This is a manual wiring/configuration rule, not a hardware interlock. Do not populate both loads and assume the revised budget covers them.

At an assumed 90% converter efficiency, common loads are 60 W Jetson,1.68W fan and 33.9759 W USB input. Adding PoE requires 77.8987 W, giving **173.5546W /14.4629A at 12 V**. The alternative GMSL configuration with a provisional 4 A allowance totals 143.6559 W /11.9713A. Take the larger configuration, not their sum. GMSL's3A label has not been verified against a manufacturer aggregate-current specification;4A remains a design allowance, not a measured requirement.

At the boost's upper static output tolerance, the PoE configuration becomes174.4875W /14.5406A. This is not a full worst case: efficiency, USB output tolerance, startup, cable losses and auxiliaries remain. Input minimum voltage has not been specified; no10.8V operating guarantee is implied. Retain 20 A continuous supply-path design/test capability as margin. Do not raise the 12 V source to compensate cable loss without checking every device.

The USB feedback divider targets 5.096 V. Reference and resistor tolerances give an estimated static regulator range of 5.012–5.181 V before ripple, bias-current error and transients. The current-limit switches and connector/cable resistances reduce loaded voltage. A 3 A electrical capacity does not establish that a connected headset will negotiate or draw 3 A. These sockets use charging identification, not USB Power Delivery, and have no data connection. Actual Meta Quest compatibility remains to be tested because the exact model was not specified.

Five 47 µF ceramic output capacitors are used at the USB buck. Their nominal sum is 235 µF; effective capacitance at bias is lower. TI's three-capacitor example states about 78 µF at 5 V and 25 °C; proportional scaling gives about 130 µF typical for five. This is not a guaranteed minimum over tolerance and temperature. Validate startup and load-step response on the prototype. No feedforward network is populated; TI describes it as optional near the minimum capacitance and its table/example guidance must not be applied without considering the series resistor and zero frequency.

## Retained D4 electrical selections

D4_COMPONENT_CHANGES_RETAINED.json records the inherited component substitutions; its original MAIN converter references now belong to POE_POWER. POE Q1–Q3 are Infineon BSC040N08NS5: same 80 V package/pinout, lower on-resistance but increased gate/output charge. The driver-current budget was reviewed; switching-node ringing, gate waveform and 40 °C thermal tests remain required. L2 changes to Coilcraft XAL4020-102MEC (packaging suffix), D2 to onsemi NRVB1H100SFT3G (same family/pinout), and the 4 mΩ shunt R2 to Ever Ohms MA251230FR004MZ. R2 uses the manufacturer-recommended 2.60 × 3.68 mm pads with a 2.55 mm inner gap; Kelvin sense continuity must be preserved.

R20 changes from 931 Ω to 953 Ω, with R19 84.5 kΩ and R18 1.96 kΩ, all 0.1%. The nominal boost target is **53.518163 V**. The calculated static tolerance interval is **52.879495–54.159133 V**, excluding ripple, bias effects and transients. A switch adapter label of 53.5 V is not evidence of its maximum acceptable input; verify the actual switch input range and startup behavior before connection.

Selected capacitors/resistors use the equivalents listed in the substitution manifest. No branch current ratings or fuse ratings were increased. USB input capacitors use the complete TDK order code CNA6P1X7R1H106KT000A. MAIN J1 retains exact Phoenix 1709681, sourced loose from DigiKey. POE R1 changes to stocked Yageo RC2010JK-077R5L, JLC C4169838: same 7.5 ohm, 5%, 0.75 W, 2010 size. Estimated snubber dissipation is 0.301 W nominal and 0.356 W with illustrative capacitor/frequency margins. This resolves the original preorder minimum; it does not establish measured pulse endurance. See verification/d6_electrical_resolution.md.

## Wiring and assembly

- Fit the exact through-hole connectors and fuse holders from the manual BOM. Fit fuse **inserts** separately; a holder's BOM entry does not include a fuse.
- MAIN_POWER J1 is the 12 V input. Check the finished board's pin labels against the pin schedule before wiring.
- MAIN_POWER J2/J3/J4/J5/J6 are the Jetson, GMSL, fan, USB and POE12V feeds respectively. Each two-pin output uses pin 1 positive and pin 2 return; verify against the final pin schedule.
- POE_POWER J1 receives fused 12 V from MAIN J6. The53.5V switch output is POE J6, a distinct three-position connector. Use only the populated supply/return positions documented in the final pin schedule. Never connect this output to a 12 V device.
- USB_POWER J1: pin 1 +12 V, pin 2 GND. J2/J3 are the two USB-A sockets; their shields connect to board GND.
- Use appropriately crimped JST contacts and verify retention. Do not tin wire before crimping it. The proposed AWG16 contact is JST SVH-41T-P1.1; thinner wire needs a compatible contact selected from the manufacturer's range.
- Use an adequately rated supply-input pair and upstream protection for the cable from the PSU to the board. Its fuse rating must match the final wire gauge and installation; the individual branch fuses do not protect an upstream input cable short.
- USB and POE via-in-pad holes must be resin-filled and copper-capped by the PCB fabricator, not left open under the module's solder pads. An ordinary stencil process over open holes is not an equivalent assembly process.
- The heavy Coilcraft SMT inductor may require an assembly support fixture. Confirm this with the assembler. The user's permission to fit through-hole components does not mean the large SMT inductor is to be hand fitted.

## Prototype bring-up record

Use a current-limited bench supply for initial tests. Disconnect the actual Jetson, switch and headset until unloaded voltage, polarity and control behavior have been checked. Record board revision, supply setting, load, ambient, waveforms and temperatures for each result.

1. **Unpowered inspection:** inspect component identities, polarities, solder joints and filled/capped thermal pads; check no hard shorts between each supply and GND. Verify the 53.5 V output connector separately.
2. **USB alone:** start from 12 V with a low current limit, no output load. Confirm approximately 5.1 V and no sustained oscillation. Increase input current allowance before applying loads. Test each output independently, then both at 3 A with electronic loads. Record voltage at board pads and at the cable-end load separately.
3. **USB transient response:** step each load from low load to 3 A and back, including simultaneous steps. Scope the regulator output and each port. Confirm no sustained oscillation and no damaging overshoot; use a short probe ground connection. Test cable insertion, removal and restart after a port overload.
4. **Main distribution:** with MAIN F5 removed, confirm polarity and nominal 12 V on each fused branch. Apply each specified load and record supply/input/connector voltage drop.
5. **Boost without switch:** fit MAIN F5 and POE F6, start unloaded and current limited. Confirm approximately 53.5 V, then increase an electronic load gradually to 1.31 A. Record input current, switching-node ringing, output ripple, startup overshoot and input-protection power-good timing. Use probes rated for the voltage and switching transients.
6. **Protection tests:** use controlled electronic-load overloads first. Verify individual USB-port current limiting and boost eFuse latch-off/recovery behavior. Test a hard output short only with a suitably rated switching fixture and current-limited source; record eFuse input/output excursions and diode current paths. Fuse ratings alone do not establish semiconductor short-circuit survival.
7. **Combined load and temperature:** test Jetson,fan,USB and the selected PoE-or-GMSL load simultaneously in the intended enclosure at 40 °C ambient until temperatures stabilize. Check the buck, current-limit switches, boost MOSFETs, inductor, eFuse, fuses, connectors and PCB. Stay within each component's recommended operating limits; TPSM63610 recommended maximum junction temperature is 125 °C, not its 150 °C absolute maximum. Package surface temperature is not identical to junction temperature.
8. **Real devices:** after the electrical tests, connect actual devices individually, then test each permitted configuration; never combine the PoE and GMSL loads. Check boot cycles, USB charging behavior, full load and cable hot-plugging. The switch's startup load and input capacitance were not specified.
9. **ESD and EMC:** evaluate the finished enclosure/cabling and USB protection on the prototype. Close ESD placement and clean DRC are not an IEC test result. Do not claim certified compliance from these design files.

No physical tests in this list have been performed by the software agent. A clean KiCad report verifies the configured schematic/layout rules and connectivity; it does not measure stability, heat, transient protection or compatibility.

## Ordering status

Read the D6 README and procurement records before ordering. The requested batch is ten of each of the three boards. Live catalogue inventory is not reserved inventory and does not establish assembly acceptance. MAIN J1 has an exact stocked loose-part source; POE R1 now uses the stocked Yageo part. POE C1 and L1 have limited stock headroom; assembler attrition must be included. The selected loose F6 source showed 378 pieces; the plan buys 20 for ten fitted plus ten spares. Manufacturer obsolescence is confirmed, so this resolves the current batch rather than future lifetime supply.

JLC parts-library components are for PCBA orders and cannot simply be shipped loose. The selected arrangement is JLC SMT assembly plus user fitting of separately purchased exact loose parts from LCSC/DigiKey; catalogue matches do not complete the harness procurement. Confirm copper/thickness, filled/capped vias, placement orientation and the heavy-inductor fixture in the quote. No physical test, order, payment or external upload is established by these documents.

Sources: [TI TPSM63610](https://www.ti.com/lit/ds/symlink/tpsm63610.pdf), [TI PMP21274](https://www.ti.com/tool/PMP21274), [TI TPS25982](https://www.ti.com/lit/ds/symlink/tps25982.pdf), [JST VH](https://www.jst-mfg.com/product/pdf/eng/eVH.pdf), [Würth USB-A connector](https://www.we-online.com/components/products/datasheet/614004190021.pdf). See the accompanying review records for calculations and unresolved procurement evidence.

## Fuse and wiring decisions

All six system fuses remain. MAIN F1/F2/F3/F4/F5 are7.5A Jetson,7.5A GMSL,1A fan,5A USB and10A POE feed. F5 is at the cable source so it also protects the cable to POE J1; no duplicate local input fuse is fitted. POE F6 is3A80V on the53.5V output. Input eFuse protection does not establish that this output fuse is redundant.

Jetson7.5A is provisional, not the only possible value. A5A supply allowance is not a measured load or inrush specification. A5A fuse carrying5A has no demonstrated enclosure/startup margin; the manufacturer typical table permits6A loading on7.5A at65°C. Verify actual startup and the weakest harness segment before considering a lower rating.

All12V connectors use pin 1 positive, pin 2GND. POE J6 uses pin 1+53.5V, pin 2unused, pin 3GND. Identify the board name before interpreting J6: MAIN J6 is12V, POE J6 is53.5V. Label the completed harness accordingly.

MAIN is passive: parallel12V power planes on F.Cu/In1.Cu, GND on In2.Cu/B.Cu, solid connections and dual-outer3mm fused branch tracks (1mm fan). No MAIN via-in-pad fabrication is required. POE and USB retain filled/capped vias. This geometry is not measured thermal qualification.

D6 fabrication detail: the five narrow POE OPT traces are now 0.16 mm; configured clearance remains 0.20 mm. MAIN visible small board legends are enlarged to 1 mm. Individual via filling/capping flags and the per-board VIA_TREATMENT.csv schedules identify selective epoxy fill and copper capping; 0.635 mm POE vias remain ordinary. See FABRICATION_NOTES.md.

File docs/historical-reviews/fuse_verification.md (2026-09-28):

# Verified fuse candidates

Manufacturer primary source: https://www.eska-fuses.de/fileadmin/produkte/datenblaetter/ESKA_KFZ_Sicherungen.pdf . Retrieved2026-09-26 from the catalog link in ESKA's current official product navigation. Saved as work/datasheets/eska_auto.pdf. Pages16 and19 were text-extracted and visually inspected. This verifies manufacturer listing and specifications; it does not verify distributor stock or constitute a lifecycle guarantee.

| Ref | Manufacturer MPN | Rating | Quantity | Catalog page |
|---|---|---|---|---|
| F1,F2 | ESKA340.026 |7.5A32VDC|2|16|
| F3 | ESKA340.017 |1A32VDC|1|16|
| F4 | ESKA340.024 |5A32VDC|1|16|
| F5 | ESKA340.027 |10A32VDC|1|16|
| F6 | ESKA340.022-80V |3A80VDC|1|19|

All have1000A breaking capacity at their rated voltage. F6 is specifically the80V suffix; standard340.022 is only32V and must not be substituted on the53.5V output. Retain the manufacturer punctuation in the BOM even if distributors normalize it. TME's candidate listing is https://www.tme.eu/en/details/340022-80v/standard-automotive-fuses/eska/ ; direct retrieval was blocked, so no stock claim is made.

The32V series time windows:110% minimum100h;135%0.75–600s;200%0.15–5s;350%0.04–0.5s;600%0.02–0.1s. Its40°C derating graph reads approximately97% (graph estimate, not exact tabulated value). Operating ambient range−40..125°C. Fuse rating is not an exact trip threshold; coordination with wiring, source current limitation and inrush still needs validation.

The80V series time windows:110% minimum100h;150%0.5–300s;200%0.15–20s;350%0.04–0.5s;600%0.02–0.1s. No40°C correction curve or explicit temperature range is provided on this series page. Do not transfer the32V derating curve to80V as a certified value. At1.31A nominal load, a3A fuse has substantial current margin, but switch startup/inrush is still unverified.

Both are standard blade geometry.32V: body19×4.5mm, overall20mm, blade6.5mm exposed length,5.25mm width,0.63mm thickness,14.5mm outer span.80V: body19±0.2×4.9±0.2mm, overall19.5±0.5mm, blade6.4±0.3mm length,5.1±0.1mm width,0.6±0.05mm thickness,14.4±0.2mm outer span. These are nominally compatible with the same standard ATO-style holder family, but actual178.6165.0001 contact tolerance/insertion fit remains a sample/mechanical check. Holder maximum PCB thickness1.5mm and80V rating are tracked separately by root.

The older Littelfuse166.7000.4302 is also verified from manufacturer2012 catalog mirrored at https://xonstorage.z8.web.core.windows.net/pdf/littelfuse_16670004402_apr22_xonlink.pdf :3A80V,500-pack; suffix4306 is100-pack. That source explicitly limits continuous operation to0.7×rating at23°C. Root has distributor end-of-life indications, so ESKA's currently manufacturer-listed80V candidate is preferred for sourcing follow-up. Do not infer Littelfuse lifecycle from the old PDF.

Machine-readable entries, curves and dimensions are in work/fuse_verification.json. No board scripts were changed.

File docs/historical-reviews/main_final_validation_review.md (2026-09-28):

# Main final export review

Reviewed `outputs/UMI_TWO_BOARD_DESIGN/MAIN_POWER` on 2026-09-26. No deliverable files modified.

- Saved native DRC report: zero violations, unconnected items and schematic parity findings. Saved ERC report: zero findings.
- Independent schematic-to-PCB text audit passes all 194 logical pins / 232 physical copper pads across 69 footprints. Final board has 322 tracks, 60 vias and 17 zone records. Audit: `work/main_final_text_audit.json`; board SHA256 `ff1235a9b821ab820f5a1f74b789e6db3fec3d624bcd211cab572e5e8a62fdaa`.
- All seven layer-PDF pages render successfully. Inspected four copper layers, front silkscreen, fabrication and outline pages. Broad plane fills, four mounting holes, distribution branches and separate boost region appear consistent. Initial PDF read overlapped a live export and failed; stable-file retry passed.
- Top render agrees with placement but omits several custom part bodies, so it is not a complete mechanical collision/height check.
- Independent Gerbonara audit supplied in package reports all four copper layers, 133 matching drill positions/sizes and 53 matching SMT placement centres. Paste is delivered separately in assembly folder.
- Critical finding sent to root: raw KiCad CPL angles are zero because local footprints bake rotation into geometry. Electrical-review agent independently checked every pad against source footprints and supplied corrected physical angles (`work/cpl_rotation_corrections.json`). U1/Q1–Q3 require CCW90 relative to source; polarized C19/C20 CCW270. Corrected supplier placement data must replace the all-zero draft before ordering.
- Front fabrication drawing contains overlapping values/references in the dense boost area and is not a readable manual assembly map. PCB source and corrected placement data remain necessary for supplier review.

This review establishes export and saved-design consistency, not hardware qualification. Assembly sourcing/orientation approval, converter startup/load/thermal testing and the documented engineering release conditions remain outstanding.

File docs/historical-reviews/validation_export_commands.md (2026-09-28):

# Official KiCad 10.0.6 export command reference for this task

All commands below were inspected with `--help` through `validation_cli_controlled.py`. Help probes returned exit 0. Actual exports require coordinating-agent authorization and are not implied by this reference.

Use absolute paths for OUT and BOARD. Wrap every actual invocation with the controlled runner; stop on crashes instead of retrying. Preserve a source snapshot and its hashes. Always inspect generated outputs; successful export does not mean electrical or manufacturing validation passed.

## Board review

Combined SVG:

```
pcb export svg --mode-single --fit-page-to-board --exclude-drawing-sheet --layers F.Cu,F.SilkS,F.Mask,Edge.Cuts --check-zones --output OUT.svg BOARD.kicad_pcb
```

Individual copper-layer SVGs with shared outline:

```
pcb export svg --mode-multi --fit-page-to-board --exclude-drawing-sheet --layers F.Cu,In1.Cu,In2.Cu,B.Cu --common-layers Edge.Cuts --check-zones --output OUTPUT_DIRECTORY BOARD.kicad_pcb
```

PDF copper/assembly review:

```
pcb export pdf --mode-multipage --layers F.Cu,In1.Cu,In2.Cu,B.Cu,F.SilkS,F.Fab,Edge.Cuts --common-layers Edge.Cuts --check-zones --output OUT.pdf BOARD.kicad_pcb
```

In single mode, `--output` is a full file path and common layers do not apply. In SVG multi mode, output is a directory. SVG `--fit-page-to-board` avoids a large blank page. PDF supports `--scale 0` for autoscale. `--check-zones` explicitly checks/refills zones for output. A DRC-only in-memory refill does not persist zone polygons for a separate export process.

3D PNG review:

```
pcb render --side top --width 1600 --height 900 --quality basic --output OUT.png BOARD.kicad_pcb
```

Custom footprints lacking models will appear without their component bodies; 3D render is not a complete mechanical clearance check. The tool supports `--rotate X,Y,Z`, `--perspective`, and optional stackup colours.

## Future manufacturing output (not yet authorized/run)

Gerber output needs an explicit layer list for the intended stackup; example four-layer list:

```
pcb export gerbers --layers F.Cu,In1.Cu,In2.Cu,B.Cu,F.Mask,B.Mask,F.SilkS,B.SilkS,F.Paste,B.Paste,Edge.Cuts --check-zones --output OUTPUT_DIRECTORY BOARD.kicad_pcb
```

X2/netlist attributes are enabled unless explicitly disabled. Coordinate precision defaults to six decimal places. Default Protel extensions are supported. No outline repetition on copper layers should be added accidentally. Keep the selected drill origin consistent with Gerbers and placement.

```
pcb export drill --format excellon --drill-origin absolute --excellon-units mm --excellon-zeros-format decimal --excellon-separate-th --generate-map --map-format pdf --generate-report --output OUTPUT_DIRECTORY BOARD.kicad_pcb
```

Position export for supplier-assembled SMT parts:

```
pcb export pos --format csv --units mm --side both --smd-only --exclude-fp-th --exclude-dnp --output OUT.csv BOARD.kicad_pcb
```

Review every footprint's SMD/through-hole attributes. Thermal pad soldering and through-hole pins affect filtering. Native KiCad placement CSV is not automatically supplier-specific CPL; map headers/rotations and review against assembly preview.

Native schematic BOM:

```
sch export bom --fields Reference,Value,Footprint,MPN,QUANTITY --labels Reference,Value,Footprint,MPN,Quantity --group-by MPN,Value,Footprint --exclude-dnp --output OUT.csv SCHEMATIC.kicad_sch
```

Manufacturer part numbers still require procurement/availability checks. The CLI does not invent LCSC/JLC part identifiers or assembly availability.

## Required evidence before release

Genuine final ERC and DRC with actual project rules, copper connectivity and schematic parity, BOM/MPN and placement reconciliation, exported CAM/drill visual inspection, board stackup/order constraints, and unresolved electrical/thermal review disposition. Prototype thermal and fault testing remains separate from CAD validation.

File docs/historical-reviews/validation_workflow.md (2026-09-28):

# KiCad verification and fabrication workflow findings

25 September 2026. Scope: KiCad 10.0.6 GUI plus official kicad-python 0.8.0 through the separate Codex Python runtime. No kicad-cli, KiCad bundled Python, GUI launches, or user configuration changes were performed by this investigation.

## What can be independently verified now

`validation_text_audit.py BOARD.kicad_pcb --out REPORT.json` independently parses the saved PCB and its sibling schematic. It does not import the design generator. It compares each symbol's actual wire-and-label net to the placed footprint pad net, checks the symbol/footprint UUID binding, and detects missing physical pads, conflicting repeated pad numbers, duplicate references and duplicate UUIDs. It supports the flat UMI schematics with unrotated custom symbols; it rejects unsupported sheets/buses/mirrored or rotated symbols. It does not validate pin functions or manufacturer pin numbering.

The existing D2 USB files passed this comparison: 32 symbols, 32 footprints, 122 logical pins, 124 physical copper pads, no net mismatches or UUID failures. That board still has only 26 tracks, no vias and no zones. The pass proves file consistency only.

`validation_ipc_audit.py --socket SOCKET --expected-board EXACT_FILENAME --out REPORT.json` uses KiCad's read-only `get_connected_items` for every pad. Union-find groups physical pads into copper-connected components per net. It rejects the connection if the loaded board name does not match. There are no hard-coded component counts. It does not launch KiCad, refill zones, save the board, or change anything in KiCad. The caller should fill zones in its controlled verification copy first, then run this audit. It records the serialized-board hash, KiCad version and time. At initial delivery this script has not been exercised against the temporary GUI endpoint because that editor was closed.

Physical copper groups remain separate even when two component pins may be internally common: that is deliberate. A designer must decide whether the layout needs external joining; the audit should not hide copper islands merely because pad numbers or internal functions match.

## Available API versus unsupported fabrication automation

The official [KiCad add-on developer documentation](https://dev-docs.kicad.org/en/apis-and-binding/ipc-api/for-addon-developers/) explicitly states:

- KiCad 9 and 10 IPC needs a running GUI.
- Plotting/exporting over IPC starts in KiCad 11.
- Schematic-editor IPC starts in KiCad 11.

Thus the `board_jobs.py` and protobuf export settings present in the installed Python client do **not** establish support in the running KiCad 10 server. The installed `Board` class has no DRC/plot/export job method. Using those newer protobuf commands against KiCad 10 is not a valid release strategy.

Supported and useful methods in the installed official client include `get_as_string`, `get_pads`, `get_tracks`, `get_vias`, `get_zones`, `get_footprints`, `get_connected_items`, `get_pad_shapes_as_polygons`, `get_bounding_box`, and `refill_zones`. The two last geometry calls can support further independent screens; none substitutes for full KiCad DRC.

`KiCad.run_action` exists but its official client docstring warns that it is unstable, intended for API developers, and may have unintended side effects. Opening a GUI DRC or plot dialog would still require a supported UI interaction route to configure, execute and retrieve results. Native UI automation is unavailable in this session. Consequently this is not a reliable unattended export mechanism.

## Instance selection

Official docs say default Windows named pipe is `api.sock`, with PID appended when occupied; observed behaviour in this session did not reliably expose the separately opened PCB editor. Root has already demonstrated a dedicated process TEMP/TMP directory produces a unique working endpoint. When using that method, always verify the connected board name before reads or edits. Do not assume an open editor window is the connected one.

## Release limits

The two audits can establish netlist consistency and copper connectivity independently of the generator. They cannot establish clearance, annular ring, mask sliver, solder paste, courtyard, edge clearance, creepage, thermal performance, switching behaviour, component orientation, circuit correctness, procurement validity or assembly capability.

Before calling any package ready to order, obtain genuine KiCad DRC and ERC results with actual configured rules; generate Gerber/drill outputs through a verified KiCad workflow; inspect those outputs in a CAM viewer; reconcile BOM and placement against exact orderable parts; and resolve electrical review findings. Electrical limits and thermal behaviour of these power boards still need prototype measurements. Under the present restriction against the previously crashing CLI/Python paths and without supported native UI access, unattended KiCad 10 fabrication export and full ERC/DRC have not been demonstrated. Do not fabricate replacement Gerbers with a custom writer and represent them as validated KiCad output.

## Existing alternative-runtime discovery

Read-only discovery also checked PATH, standard Program Files installation folders, the Windows uninstall registry, relevant services and the Downloads directory:

- `C:\Windows\system32\wsl.exe` exists, but `wsl.exe --list --verbose` explicitly reports that Windows Subsystem for Linux is **not installed**. There is no usable installed Linux distribution from this entry point.
- No Docker or Podman executable was found on PATH; no corresponding standard installation directory, installed-program record or service was found.
- No VMware or VirtualBox installed-program record or standard installation folder was found.
- The installed-program registry reports only KiCad 10.0.6 at `C:\Program Files\KiCad\10.0`. The only KiCad installer observed in Downloads is `kicad-10.0.6-x86_64.exe`, the same release.

This bounded discovery did not search every byte on every disk, but it found no existing supported Linux/container/alternate KiCad runtime that can be used immediately. No WSL, distribution, VM, container engine or other OS-level component was installed or configured. Installing an OS-level environment would be a separate environmental change, not an available fallback already present on this machine.

## Controlled Windows CLI version-only probe

Root subsequently authorized a narrowly scoped fresh CLI test with process-local Windows error handling and isolated configuration. This supersedes the earlier no-CLI restriction **for the version query only**.

[Microsoft SetErrorMode documentation](https://learn.microsoft.com/en-us/windows/win32/api/errhandlingapi/nf-errhandlingapi-seterrormode) confirms child processes inherit the parent's error mode. [Process creation flags](https://learn.microsoft.com/en-us/windows/win32/procthread/process-creation-flags) confirms `CREATE_DEFAULT_ERROR_MODE` would disable this inheritance; the wrapper deliberately does not set that flag. `CREATE_NO_WINDOW` avoids opening a console window. `SEM_NOGPFAULTERRORBOX` suppresses invoking Windows Error Reporting; this is process-local, not a machine configuration change.

`validation_cli_probe.py` runs in separate Codex Python, sets and confirms process error mode `0x8003`, sets TEMP/TMP and KICAD_CONFIG_HOME beneath `work/validation_cli_env`, and runs only the installed official `kicad-cli.exe --version` with a 20-second timeout.

Result: exit code **0 / 0x0**, stdout **10.0.6**, empty stderr, completed in **0.906 seconds**. Machine-readable record: `work/validation_cli_env/version_probe.json`. No design load, DRC, ERC or export has been attempted by this probe. A version-only success does not establish that the previously failing design operations now work.

## Controlled PCB DRC now demonstrated

Root then authorized a read-only USB PCB DRC snapshot. `validation_cli_controlled.py` generalizes the same process-local error mode and isolated environment, without automatic retries. Only expressly authorized CLI operations should be invoked through it.

`pcb drc --help` completed with exit 0. The USB_POWER PCB/project were copied to `work/validation_cli_env/input`; DRC ran with JSON output, all severities, all track errors and `--exit-code-violations`. It did **not** use `--save-board`, `--refill-zones` or schematic parity.

The actual PCB DRC completed in **0.828 seconds**, exit **5**, empty stderr, and produced `work/validation_cli_env/usb_drc.json`: **49 violations and 102 unconnected items**. Exit 5 reflects the requested nonzero result for design violations, not a process crash. The breakdown was 36 footprint-library warnings, 5 silk overlaps, 5 silk-over-copper warnings, 2 silk-edge warnings and 1 courtyard overlap (J2/H3). The footprint-library warnings arise because this narrowly specified first snapshot copied only PCB/project, not the local library table and library. Future complete snapshots must include those dependencies.

This establishes a working official DRC path under controlled invocation; it supersedes the earlier conclusion that DRC was unavailable. It does not establish DRC pass, schematic ERC functionality or export functionality. Those need separately authorized scoped tests and actual results.

## Iterative DRC and ERC snapshots authorized and functioning

Root authorized continued controlled read-only DRC/ERC snapshots for both active projects, still without fabrication exports. `validation_snapshot.py` copies PCB, schematic, project, rule and local library dependencies, records UTC/mtime/SHA256 in `snapshot_manifest.json`, and rejects any file changed during copying. Validation outputs are kept separate from source designs.

- USB snapshot 02, **2026-09-25 22:24:02 UTC**: real ERC completed normally in 2.796 seconds, exit 5, with 189 violations (152 off-grid endpoints, 36 missing symbol-library warnings, one undriven VIN power-input error). DRC completed normally in 0.734 seconds, exit 5: 126 violations and 68 unconnected items. DRC breakdown: 77 dangling vias, 17 undersized drills relative to project minimum, 17 undersized via diameters, 5 silk overlaps, 5 silk-over-copper, 3 local footprint mismatches and 2 silk-edge warnings. Zones were not filled for that USB DRC. H3/J2 courtyard overlap was fixed by this revision.
- Main snapshot 01, **2026-09-25 22:24:15 UTC**: real DRC with in-memory zone refill (`--refill-zones`, without `--save-board`) completed normally in 0.828 seconds, exit 5: 4 warnings for the absent global MountingHole library and 99 unconnected items; no clearance/courtyard violations were returned. Real ERC completed normally in 0.406 seconds, exit 5: 257 violations (201 off-grid endpoints, 55 missing UMI symbol-library warnings, one undriven VIN power-input error).

Reports use names `usb_{drc,erc}_02.json` and `main_{drc,erc}_01.json` beneath `work/validation_cli_env`. These are historical snapshots while routing is ongoing, not final release checks. Normal completion with exit 5 demonstrates usable validators, never a clean design.

## USB schematic packaging: zero real ERC violations

`validation_schematic_package.py` provides `package_schematic(path, externally_driven_nets=())`. This separate helper normalizes generated flat schematic symbol/pin/wire locations to a 1.27 mm grid, preserves existing symbol/wire/label UUIDs, makes text 1 mm, writes the actual local UMI symbol library and library table, and adds stable-ID boardless power flags only on explicitly provided existing net names. It does not change PCB files or ignore rule checks.

On a controlled USB test copy, with power flags on `12V_PROTECTED` and `GND`, the independent text comparison still passed all 122 logical pins and UUID bindings. Official KiCad ERC then returned **exit 0, zero violations**, in **0.422 seconds**. Evidence: `work/validation_cli_env/usb_grid_erc.json`; test copy: `work/validation_cli_env/usb_grid_test`. This validates the helper on that snapshot. Root must invoke the helper in the production builder and rerun release checks after later circuitry changes.

Main snapshot 02 at **22:28:32 UTC** independently passed all **194 logical pins**, with **65 circuit symbols / 69 footprints / 232 physical copper pads**. Its main-specific schematic reflow and legitimate power flags yielded **zero official ERC violations, exit 0**, in **0.375 seconds**. DRC completed normally in 0.797 seconds with in-memory zone refill: 4 missing MountingHole library warnings and **137 unconnected items**, no clearance/courtyard violations returned. This revision includes the captured input eFuse circuit but still needs its routing. Evidence: `main_text_02.json`, `main_erc_02.json`, `main_drc_02.json` beneath `work/validation_cli_env`.

## USB completed copper connectivity and internal review exports

USB snapshot 03 could not load into DRC because a new graphic used undefined layer `F.Silkscreen`; KiCad returned a normal error code 3, not a crash. Root corrected it to canonical `F.SilkS`. ERC on snapshot 03 was clean and its schematic hash was unchanged in snapshot 04.

USB snapshot 04 at **22:33:08 UTC**: official DRC with in-memory refill returned **zero unconnected items and no clearance/electrical geometry errors**. Only **three footprint-library mismatch warnings** remained for rotated C1, C3 and R1. Root reported these already used actual rotation; incrementing text angles in snapshot 05 did not remove the mismatch. Exact cause was not established by this stream. Exit 5 correctly reflected these warnings. This is a major routing milestone but not a full clean release.

Root authorized internal visual review exports. Official `pcb export pdf --mode-multipage ... --check-zones` produced `usb_review_04.pdf` successfully (exit 0, 0.75 seconds), with filled copper polygons in the exported review. Official `pcb render` produced `usb_review_04_top.png` successfully (exit 0, 1.5 seconds). The PDF front-copper page was rasterized and inspected. The top 3D render was inspected; the module, USB connectors and some IC bodies are absent because their custom/local footprints do not have 3D models. The PNG came from the saved, unfilled snapshot and is a placement visual only. No Gerber, drill or supplier order package was generated by this stream.

Inspected exact export command syntax is in `work/validation_export_commands.md` and the corresponding `*_help.json` captures.

## Native schematic parity identified additional metadata/name issues

An additional official DRC run on USB snapshot 05 with `--schematic-parity` identified **164 parity issues**: 124 net conflicts, 36 missing MPN footprint fields and 4 mounting-hole BOM exclusion differences. Local schematic labels produce canonical names such as `/GND`, whereas the generated PCB used `GND`. Two explicitly unconnected pins also need KiCad's unique diagnostic net names (`unconnected-(U1-SW-Pad4)` and `unconnected-(U1-NC-Pad16)`) for native parity.

The earlier independent text audit checked logical label names and therefore did not establish native KiCad canonical name parity. Root/main agents were informed and are fixing this without changing intended topology. Final validation should include `--schematic-parity`. The text audit now accepts the exact KiCad-generated no-connect name when a pin is explicitly marked unconnected, but it remains complementary to the native parity check. Evidence: `usb_parity_05.json`.

USB snapshot 06 at **22:38:13 UTC** achieved **full official DRC pass** with all severities, all track errors, zone refill and schematic parity enabled: **zero violations, zero unconnected items, zero schematic parity issues, exit 0**. Independent 122-pin comparison also passed. ERC had only two label-scope warnings because power-flag labels were still local while circuit labels had become global. The packaging helper was updated so new power-flag labels follow the existing net's global/local scope; source rebuild and final ERC are pending. Evidence: `usb_drc_06.json`, `usb_erc_06.json`, `usb_text_06.json`.
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

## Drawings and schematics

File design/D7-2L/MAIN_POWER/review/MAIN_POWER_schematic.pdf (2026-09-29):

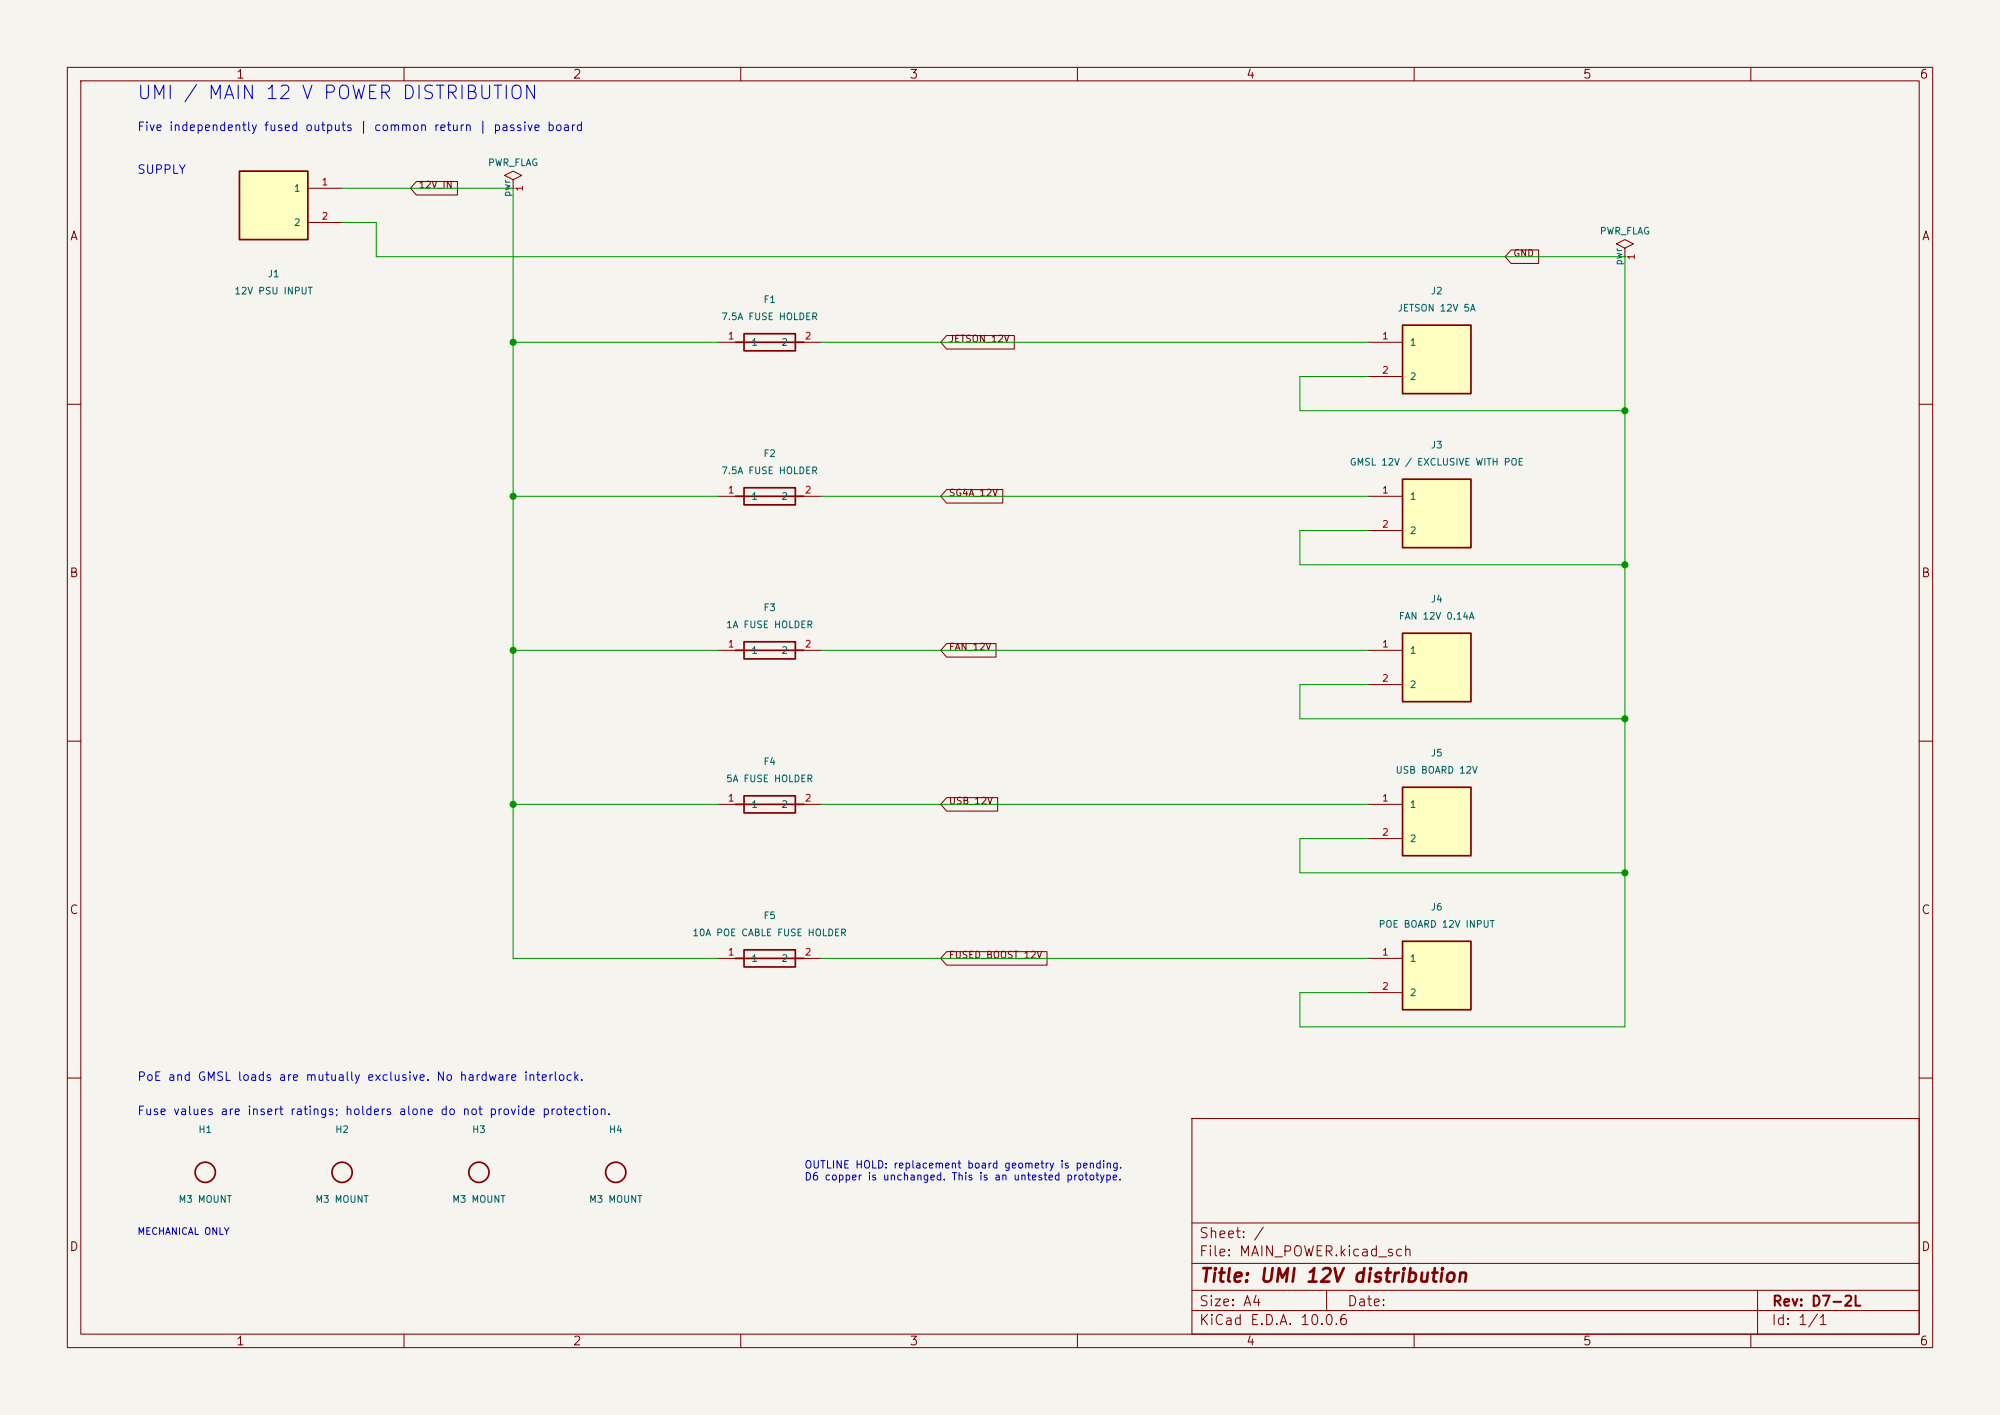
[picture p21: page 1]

Five independently fused outputs | common return | passive board UMI / MAIN 12 V POWER DISTRIBUTION

J3 GMSL 12V / EXCLUSIVE WITH POE

10A POE CABLE FUSE HOLDER

Fuse values are insert ratings; holders alone do not provide protection.

Size: A4 | Rev: D7-2L
KiCad E.D.A. 10.0.6 | Id: 1/1

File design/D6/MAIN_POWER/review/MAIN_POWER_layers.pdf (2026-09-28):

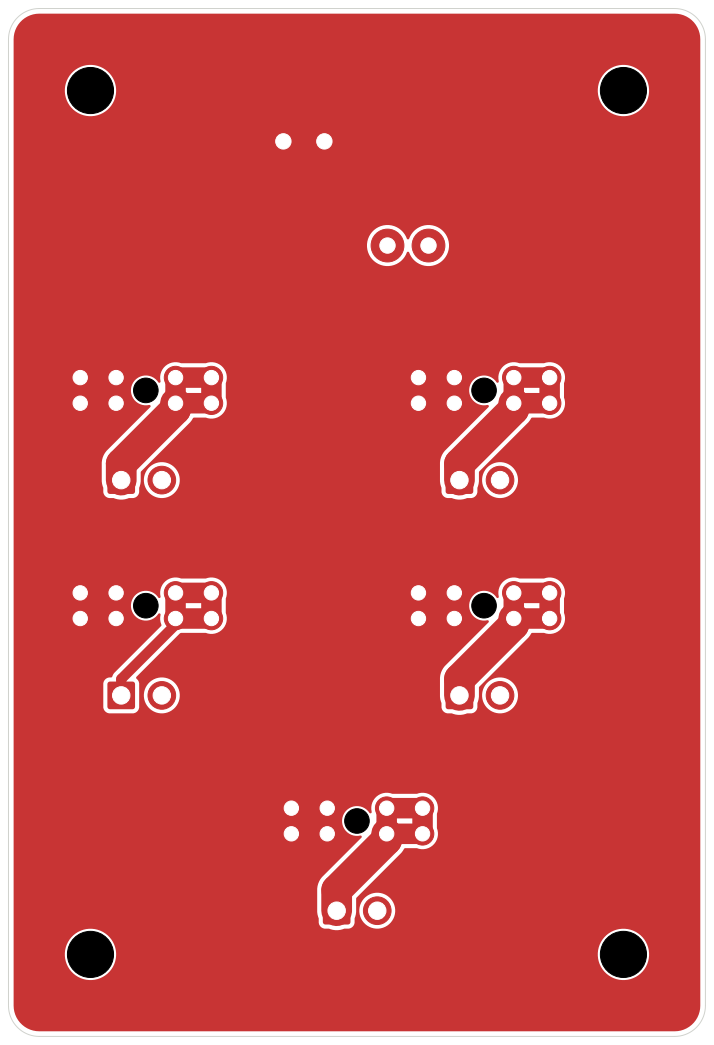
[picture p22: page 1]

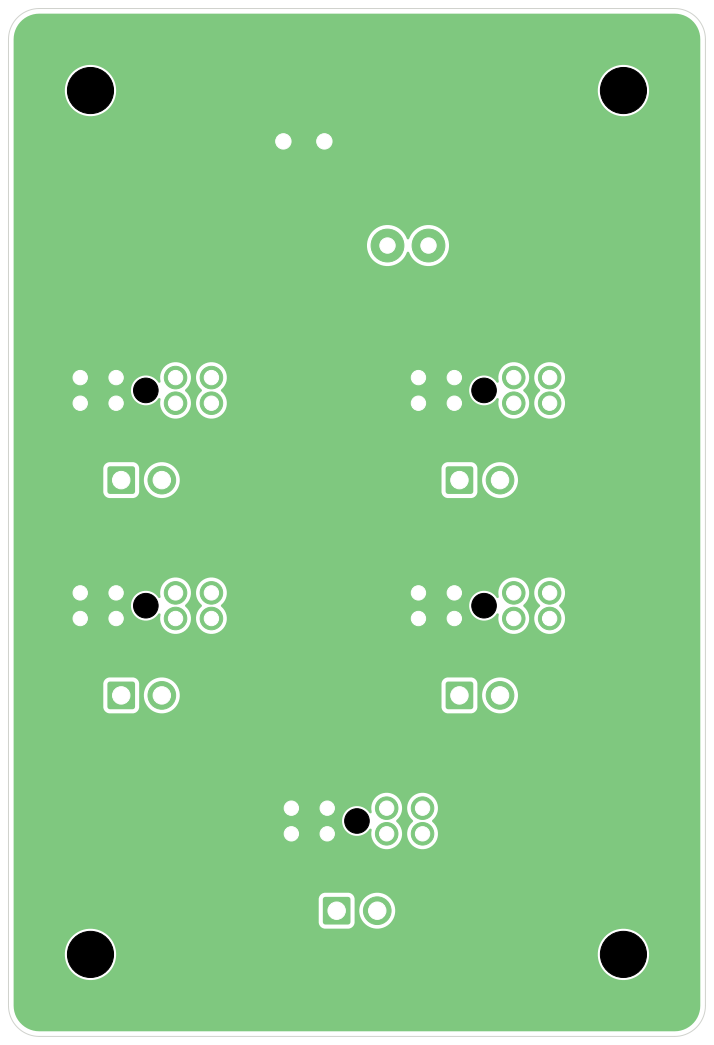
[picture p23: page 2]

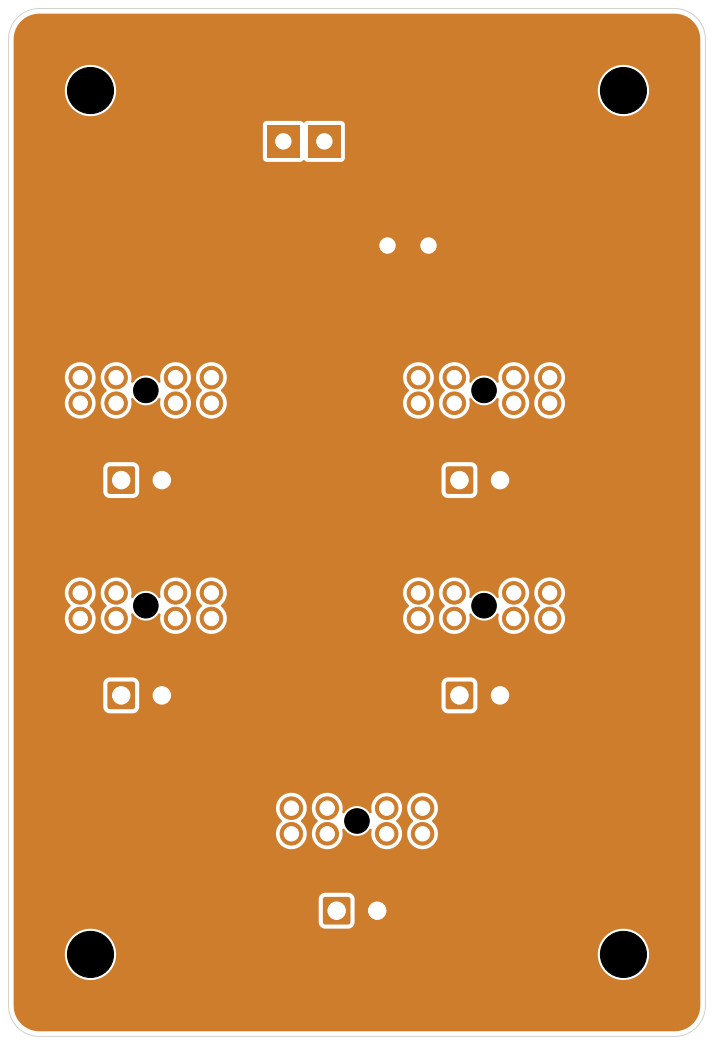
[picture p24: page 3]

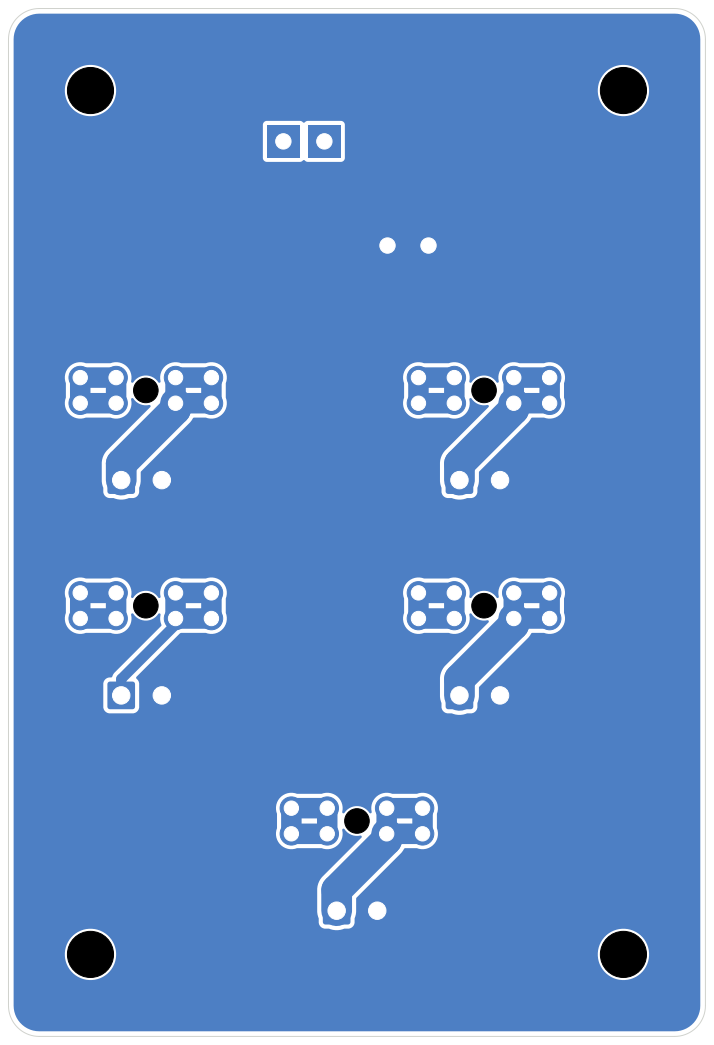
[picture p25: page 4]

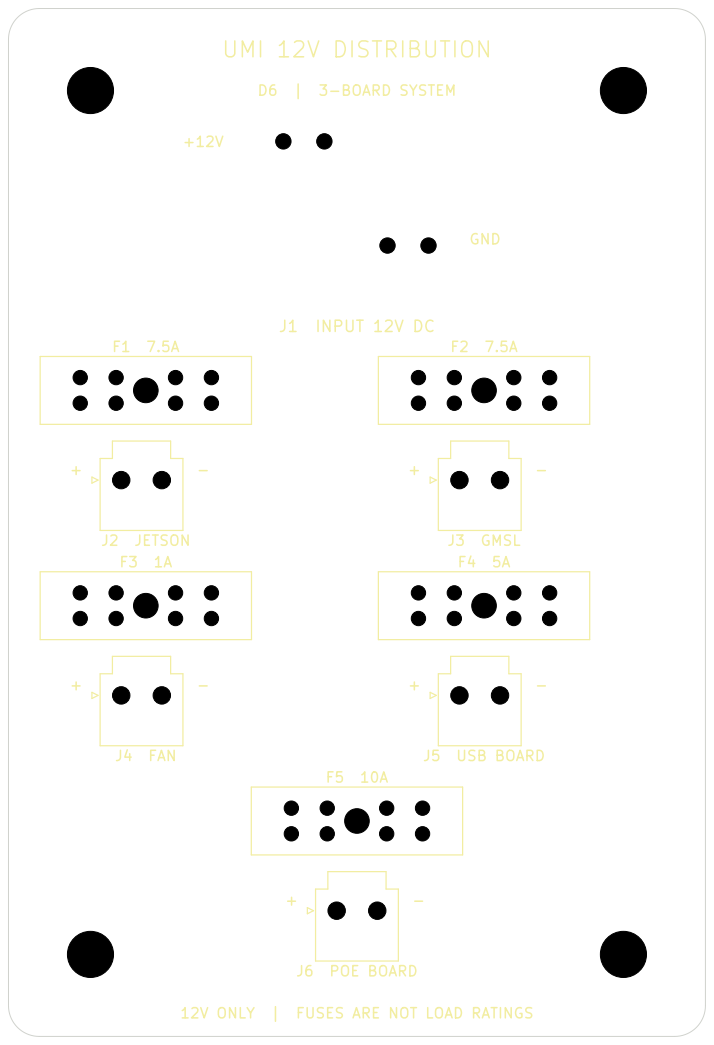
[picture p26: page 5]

J1 INPUT 12V DC UMI 12V DISTRIBUTION
J4 FAN +12V -

12V ONLY | FUSES ARE NOT LOAD RATINGS +

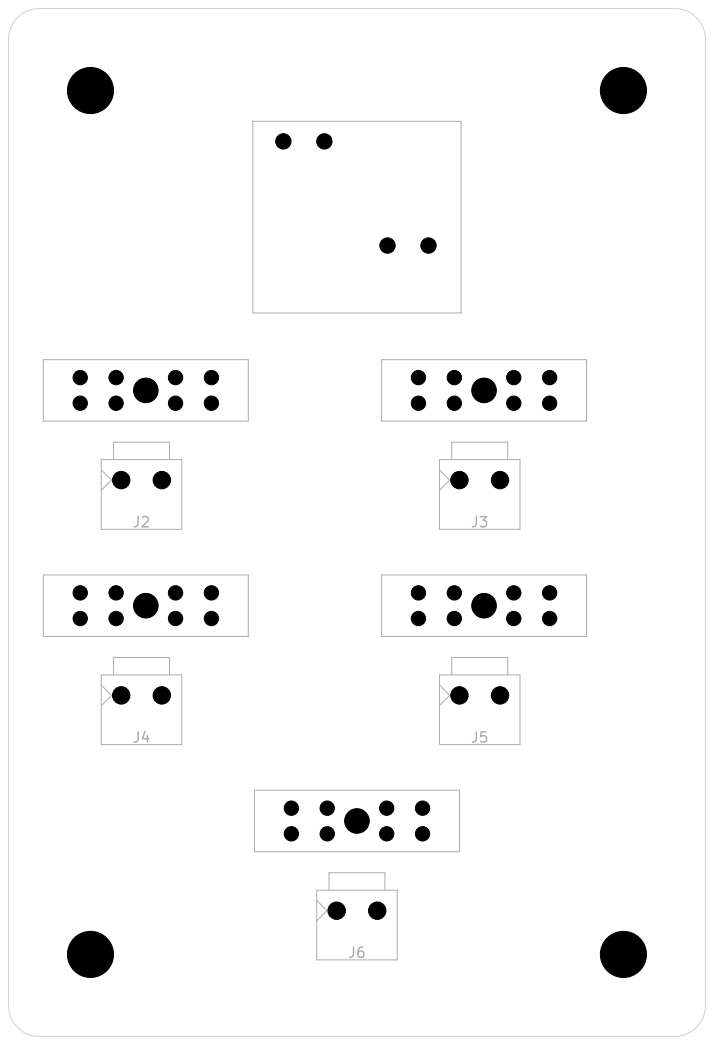
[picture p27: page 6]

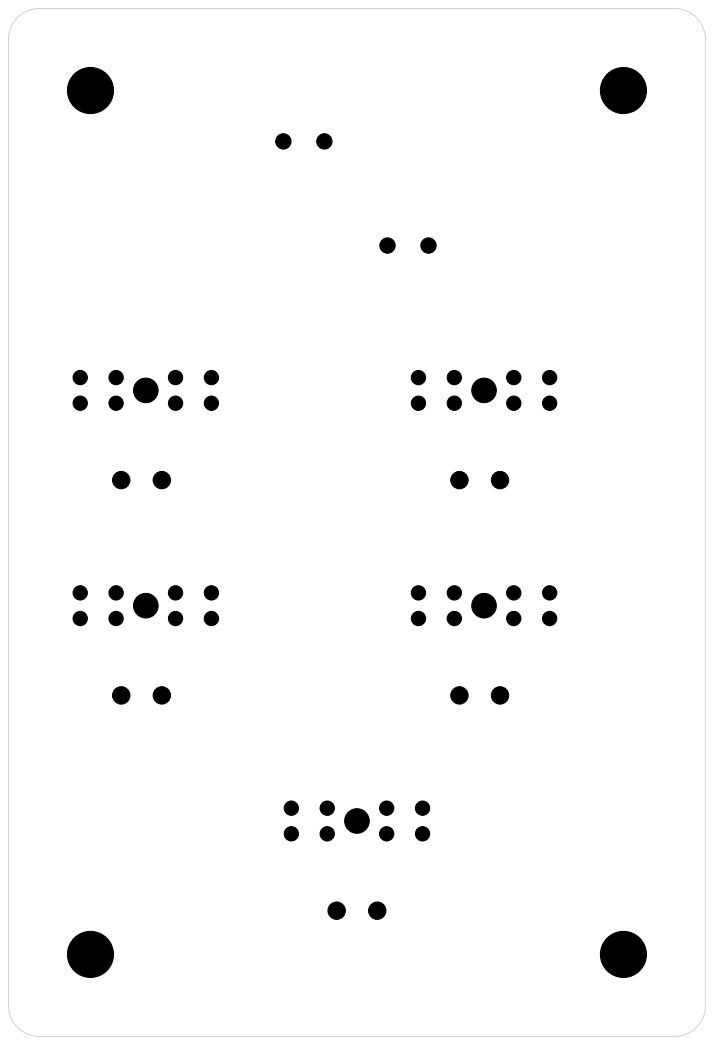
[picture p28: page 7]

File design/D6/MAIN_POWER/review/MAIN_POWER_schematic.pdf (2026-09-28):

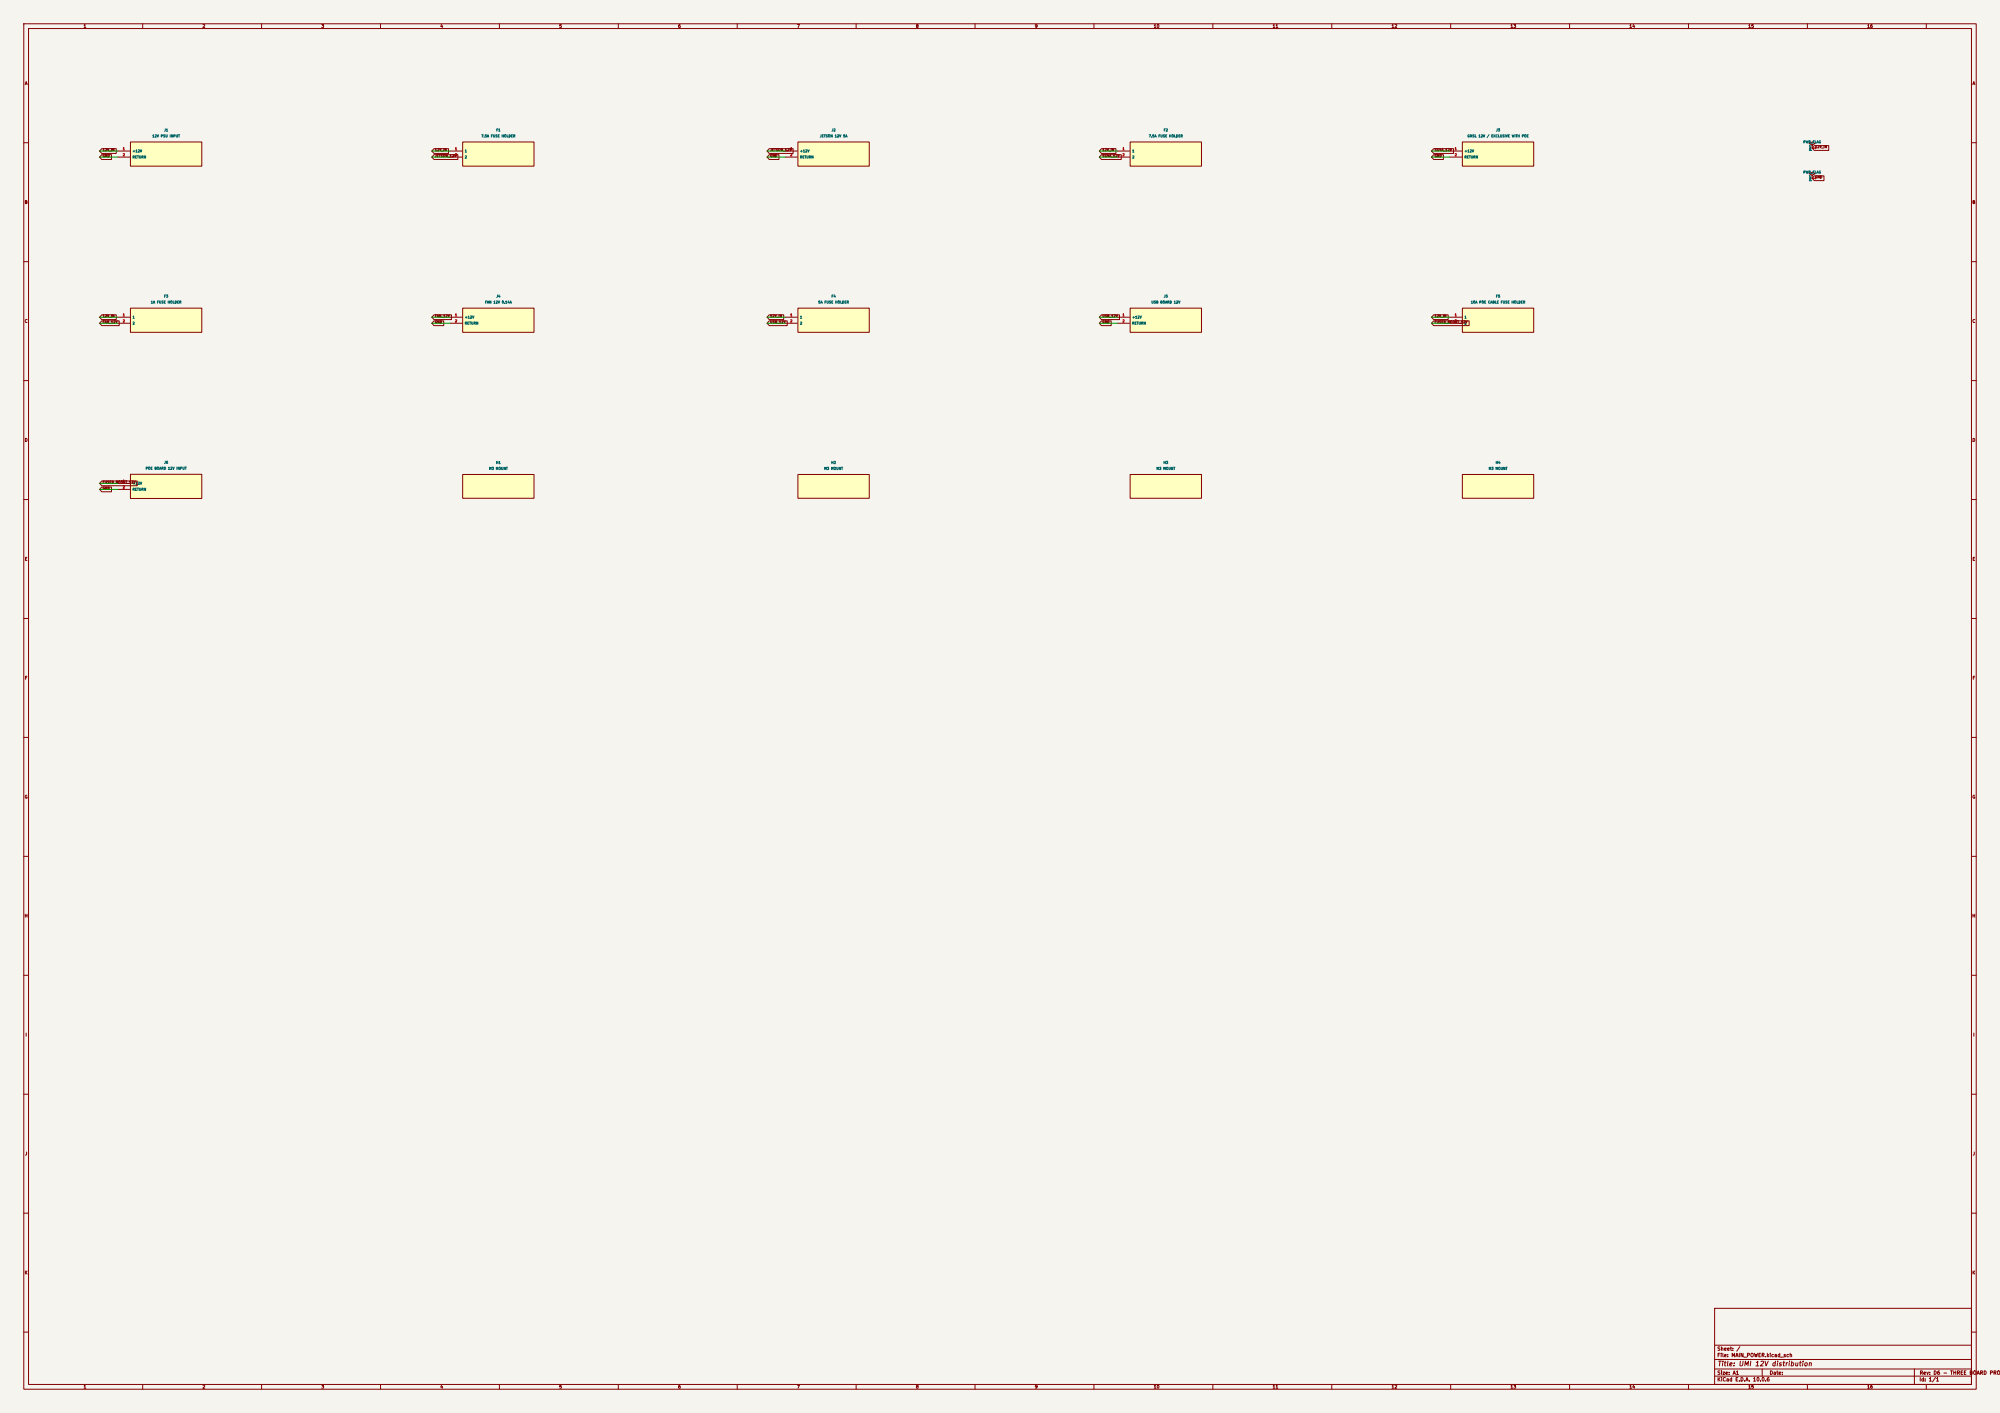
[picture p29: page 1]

J3 GMSL 12V / EXCLUSIVE WITH POE

J5 USB BOARD 12V H3 M3 MOUNT H1 M3 MOUNT

10A POE CABLE FUSE HOLDER

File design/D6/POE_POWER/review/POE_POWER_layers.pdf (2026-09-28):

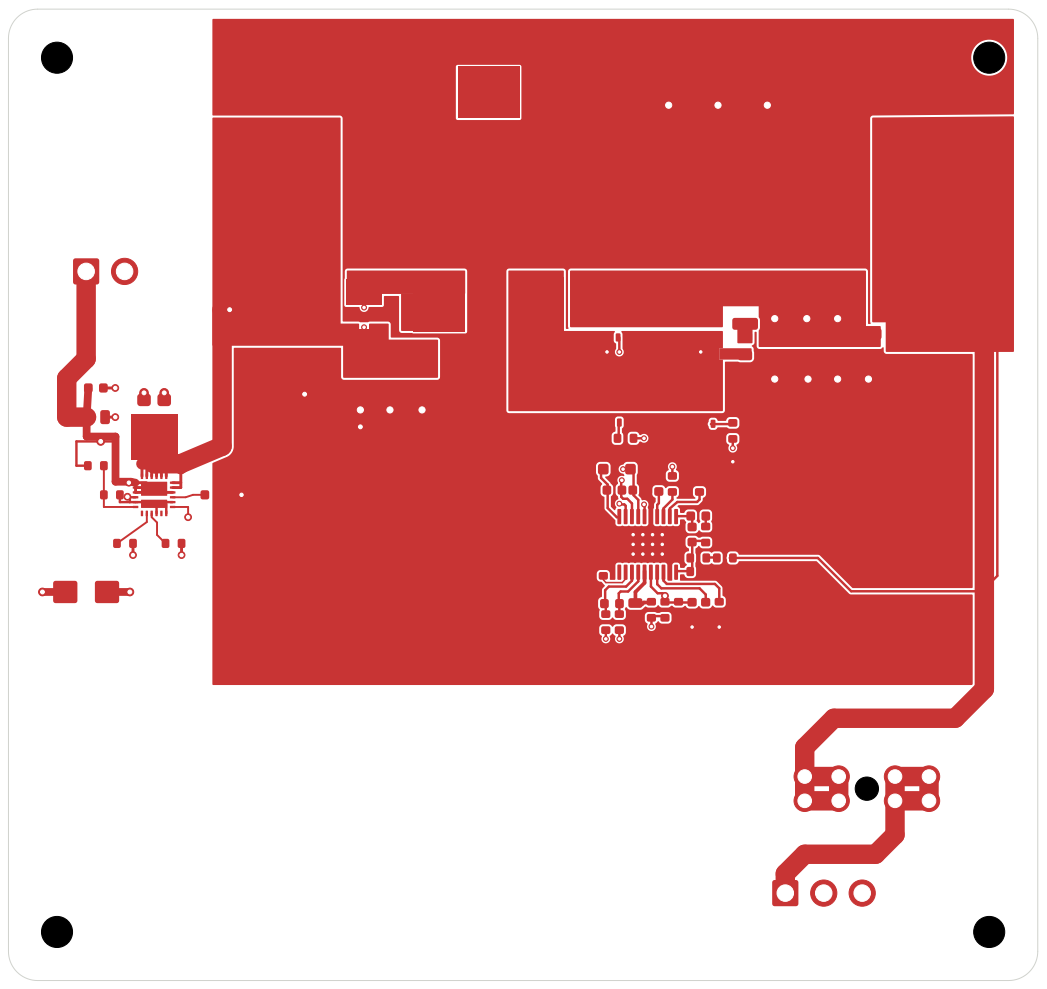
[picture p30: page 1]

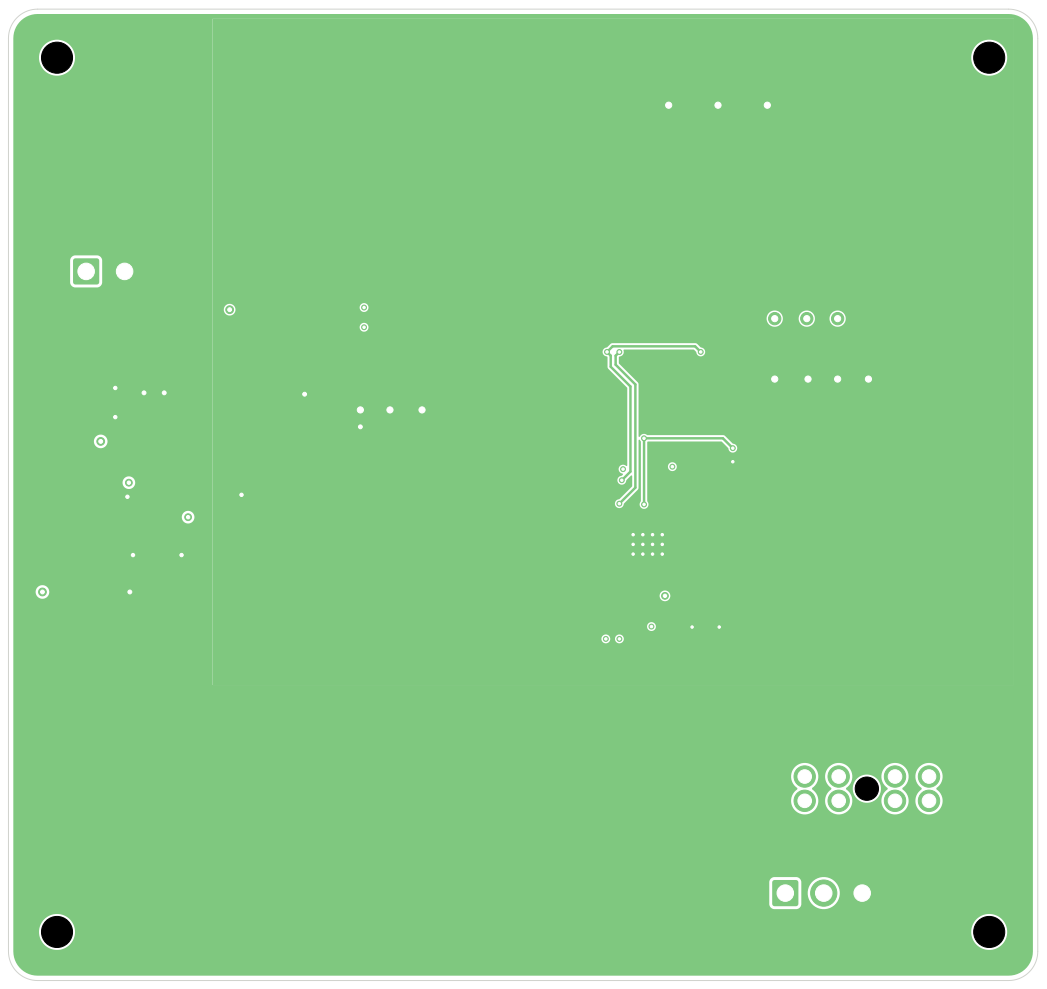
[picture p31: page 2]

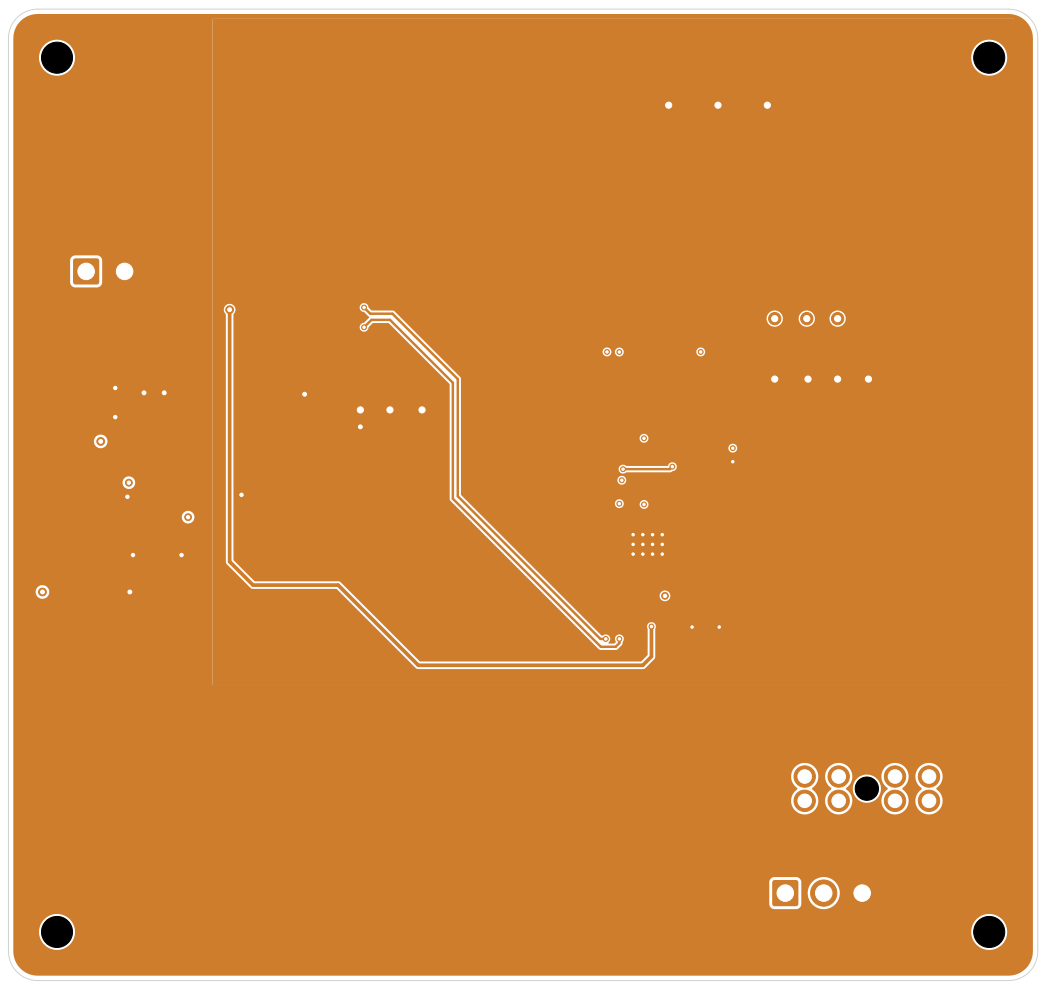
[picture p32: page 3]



F6 / 3A 80V DC UMI / POE POWER

INPUT FUSE ON MAIN BOARD



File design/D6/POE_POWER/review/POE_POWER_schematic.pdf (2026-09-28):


3A 80V BOOST OUTPUT FUSE HOLDER

File: POE_POWER.kicad_sch
Title: UMI PoE supply - 12V to 53.5V

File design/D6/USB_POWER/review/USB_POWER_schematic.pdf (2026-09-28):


File: USB_POWER.kicad_sch
Title: UMI circuit development











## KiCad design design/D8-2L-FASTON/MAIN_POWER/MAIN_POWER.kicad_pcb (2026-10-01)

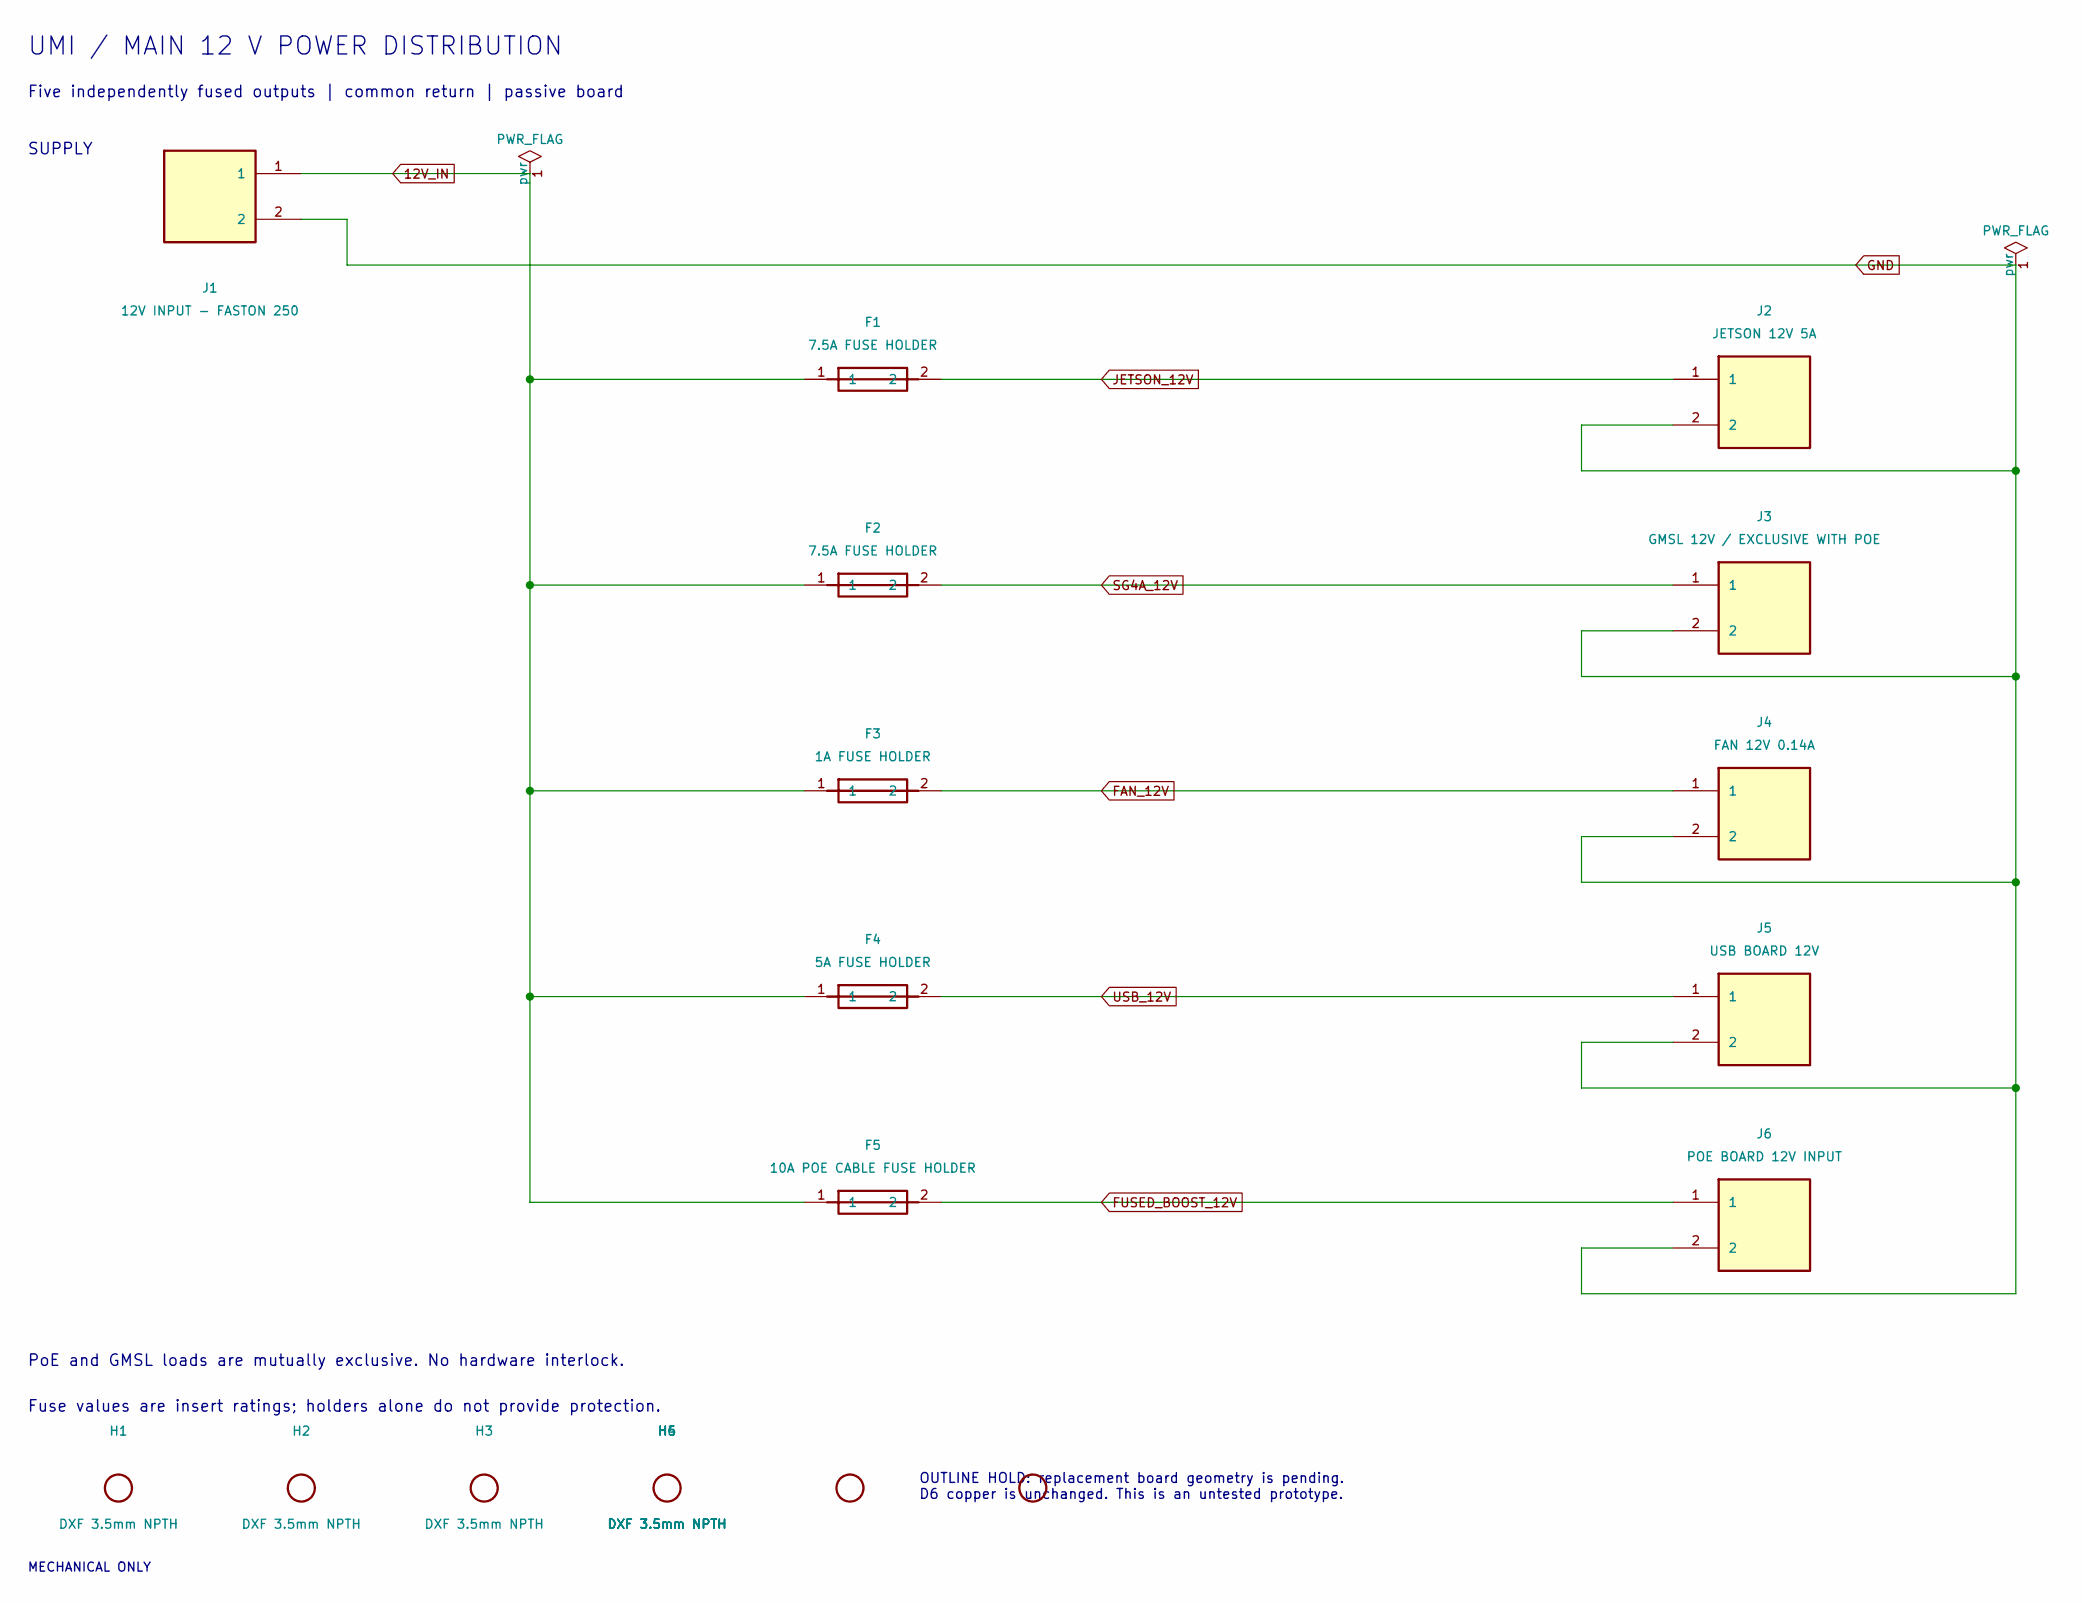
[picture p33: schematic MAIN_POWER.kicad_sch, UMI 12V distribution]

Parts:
F1, F2: 7.5A FUSE HOLDER; FuseHolder_Blade_ATO_Littelfuse_FLR_178.6165; MPN 178.6165.0002
F3: 1A FUSE HOLDER; FuseHolder_Blade_ATO_Littelfuse_FLR_178.6165; MPN 178.6165.0002
F4: 5A FUSE HOLDER; FuseHolder_Blade_ATO_Littelfuse_FLR_178.6165; MPN 178.6165.0002
F5: 10A POE CABLE FUSE HOLDER; FuseHolder_Blade_ATO_Littelfuse_FLR_178.6165; MPN 178.6165.0002
H1, H2, H3, H4, H5, H6: DXF 3.5mm NPTH; MountingHole_3.5mm; MPN MECHANICAL - NO PURCHASE
J1: 12V INPUT - FASTON 250; Input_FASTON_250_PAIR; MPN 63951-4 x2
J2: JETSON 12V 5A; JST_VH_B2P-VH_1x02_P3.96mm_Vertical; MPN B2P-VH(LF)(SN)
J3: GMSL 12V / EXCLUSIVE WITH POE; JST_VH_B2P-VH_1x02_P3.96mm_Vertical; MPN B2P-VH(LF)(SN)
J4: FAN 12V 0.14A; JST_VH_B2P-VH_1x02_P3.96mm_Vertical; MPN B2P-VH(LF)(SN)
J5: USB BOARD 12V; JST_VH_B2P-VH_1x02_P3.96mm_Vertical; MPN B2P-VH(LF)(SN)
J6: POE BOARD 12V INPUT; JST_VH_B2P-VH_1x02_P3.96mm_Vertical; MPN B2P-VH(LF)(SN)

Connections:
12V_IN: F1.1, F2.1, F3.1, F4.1, F5.1, J1.1
FAN_12V: F3.2, J4.1
FUSED_BOOST_12V: F5.2, J6.1
GND: J1.2, J2.2, J3.2, J4.2, J5.2, J6.2
JETSON_12V: F1.2, J2.1
SG4A_12V: F2.2, J3.1
USB_12V: F4.2, J5.1

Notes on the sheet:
UMI / MAIN 12 V POWER DISTRIBUTION
Five independently fused outputs | common return | passive board
SUPPLY
PoE and GMSL loads are mutually exclusive. No hardware interlock.
Fuse values are insert ratings; holders alone do not provide protection.
MECHANICAL ONLY
OUTLINE HOLD: replacement board geometry is pending. D6 copper is unchanged. This is an untested prototype.

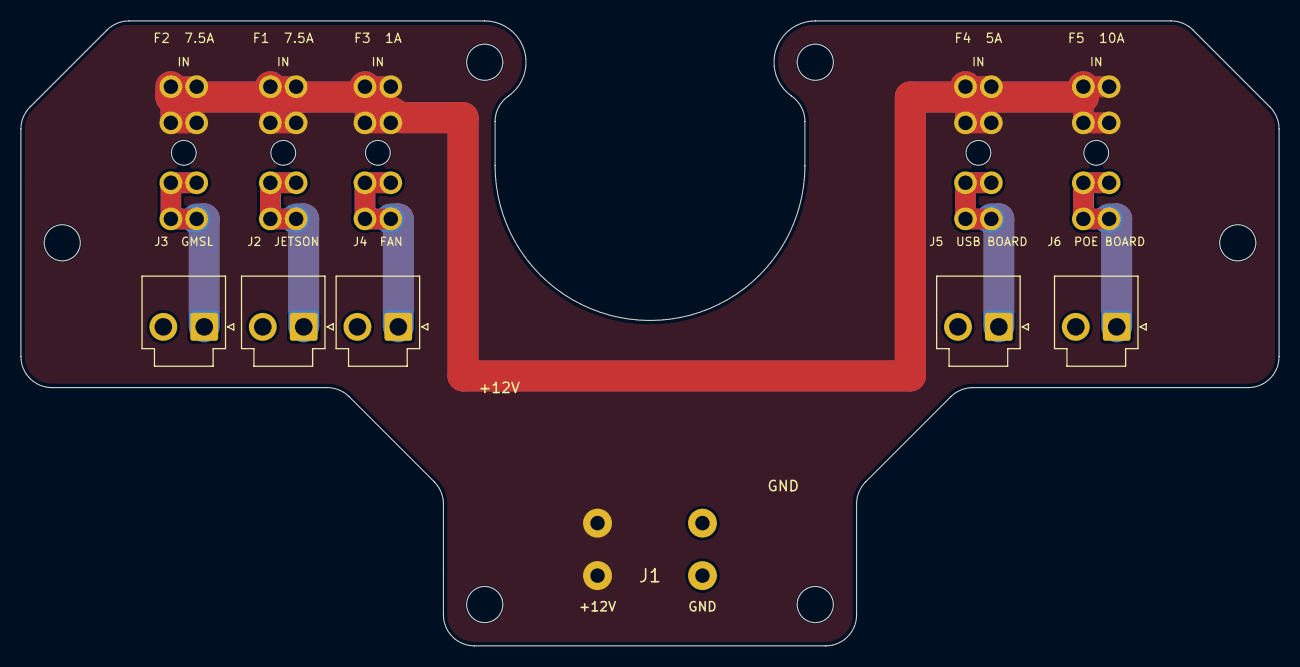
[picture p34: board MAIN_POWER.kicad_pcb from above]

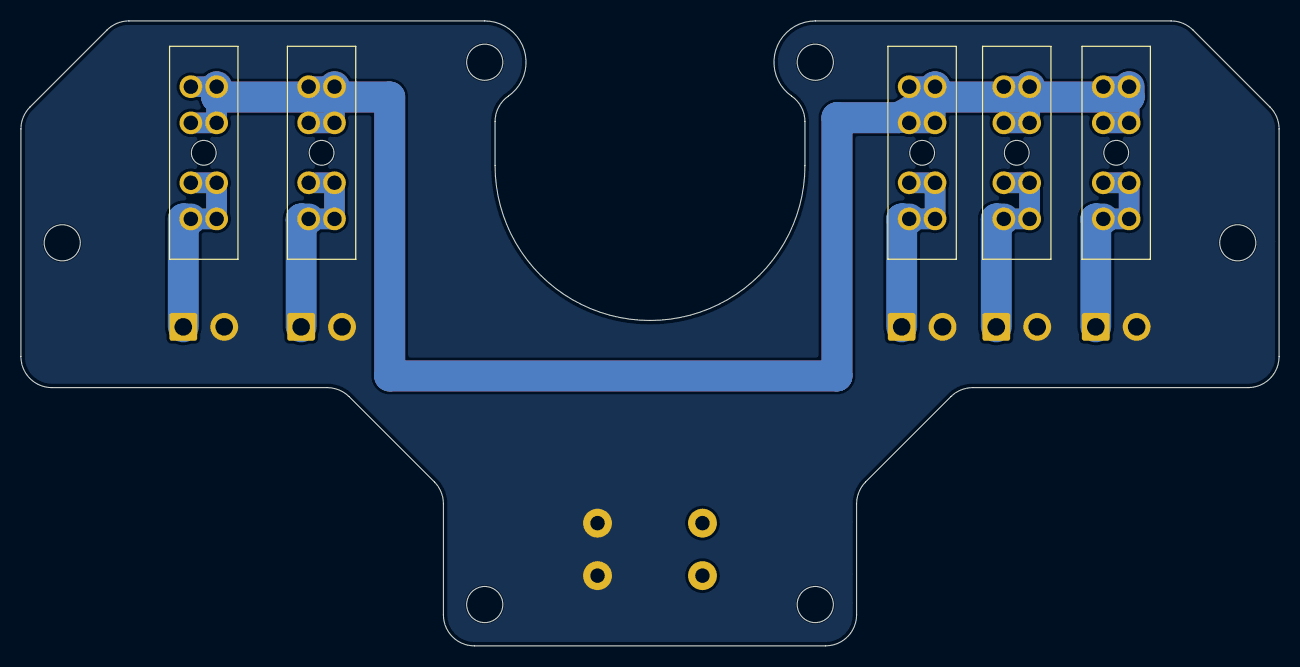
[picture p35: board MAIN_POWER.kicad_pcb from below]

Board: 2 copper layers, 121.8 x 60.5 mm, 17 parts (5 on the bottom side), 7 nets.

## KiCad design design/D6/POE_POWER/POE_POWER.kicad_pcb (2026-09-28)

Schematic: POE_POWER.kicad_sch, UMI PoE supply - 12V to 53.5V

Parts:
C1: 470pF 100V; C_0805_2012Metric_R90; MPN C0805C471J1GACTU
C2, C3, C4, C5, C6, C7, C8: 4.7uF 80V; C_1210_3225Metric_R90; MPN GRM32ER71K475KE14L
C9: 100nF 25V; C_0603_1608Metric_R180; MPN GRM188R71E104KA01D
C10: 100pF 50V; C_0603_1608Metric; MPN GRM1885C1H101JA01D
C11: 1uF 16V; C_0603_1608Metric_R180; MPN GCM188R71C105KA64D
C13: 100pF 50V; C_0603_1608Metric_R90; MPN GRM1885C1H101JA01D
C14: 47nF 50V; C_0603_1608Metric_R270; MPN CC0603KRX7R9BB473
C15: 470nF 100V; C_0805_2012Metric_R90; MPN GRM21BR72A474KA73L
C16: 100nF 25V; C_0603_1608Metric_R90; MPN GRM188R71E104KA01D
C17: 1500pF 50V; C_0603_1608Metric_R90; MPN GRM1885C1H152JA01D
C18: 15nF 50V; C_0603_1608Metric; MPN CC0603KRX7R9BB153
C19, C20: 47uF 80V; Panasonic_FK_G_10x10.2_R90; MPN EEE-FK1K470P
C21: 1uF 50V X7R; C_0805_2012Metric; MPN GRM21BR71H105KA12L
C22: 100nF 50V; C_0603_1608Metric; MPN GRM188R71H104KA93D
C23: 6.8nF 50V C0G; C_0603_1608Metric; MPN GRM1885C1H682JA01D
D2: MBR1H100SFT3G; D_SOD-123F; MPN NRVB1H100SFT3G
D3: SMBJ15A; D_SMB; MPN SMBJ15A
D4: SS10P4-M3/86A; TO-277A; MPN SS10P4-M3/86A
F6: 3A 80V BOOST OUTPUT FUSE HOLDER; FuseHolder_Blade_ATO_Littelfuse_FLR_178.6165; MPN 178.6165.0002
H1, H2, H3, H4: MountingHole_3.2mm_M3; MPN MECHANICAL
J1: 12V FROM MAIN; JST_VH_B2P-VH_1x02_P3.96mm_Vertical; MPN B2P-VH(LF)(SN)
J6: SWITCH 53.5V 1.31A; JST_VH_B3P-VH_1x03_P3.96mm_Vertical; MPN B3P-VH(LF)(SN)
L1: 10uH; Coilcraft_SER2915H; MPN SER2915H-103KL
L2: 1uH; L_Coilcraft_XAL4020-XXX; MPN XAL4020-102MEC
Q1, Q2, Q3: BSC040N08NS5; BSC072N08NS5_TDSON_8_R270; MPN BSC040N08NS5
R1: 7.5; R_2010_5025Metric_R270; MPN RC2010JK-077R5L
R2: 4m 1%; EverOhms_MA2512_2to5mOhm_R270; MPN MA251230FR004MZ
R3, R4: 100; R_0603_1608Metric_R90; MPN ESR03EZPJ101
R5, R8: 0; R_0603_1608Metric_R90; MPN ERJ-3GEY0R00V
R10: 49.9k; R_0603_1608Metric_R90; MPN CRCW060349K9FKEA
R11: 3.3 1%; R_0603_1608Metric_R90; MPN RC0603FR-073R3L
R12: 0; R_0603_1608Metric_R270; MPN ERJ-3GEY0R00V
R13: 8.45k; R_0603_1608Metric_R270; MPN RC0603FR-078K45L
R14: 30k; R_0603_1608Metric_R90; MPN CRCW060330K0JNEA
R16: 40.2k; R_0603_1608Metric_R270; MPN CRCW060340K2FKEA
R17: 20.5k; R_0603_1608Metric_R270; MPN CRCW060320K5FKEA
R18: 1.96k 0.1%; R_0603_1608Metric_R180; MPN RT0603BRD071K96L
R19: 84.5k 0.1%; R_0603_1608Metric; MPN ERA-3AEB8452V
R20: 953 0.1%; R_0603_1608Metric; MPN RT0603BRD07953RL
R21: 0; R_0603_1608Metric; MPN ERJ-3GEY0R00V
R22: 100k 0.1%; R_0603_1608Metric; MPN RT0603BRD07100KL
R23: 13.7k 0.1%; R_0603_1608Metric; MPN RT0603BRD0713K7L
R24: 182 0.1%; R_0603_1608Metric; MPN RT0603BRD07182RL
R25: 511 0.1%; R_0603_1608Metric; MPN RT0603BRD07511RL
U1: LM5122MHX/NOPB; HTSSOP-20-1EP_4.4x6.5mm_P0.65mm_EP3.4x6.5mm_Mask2.4x3.7mm_R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; MPN LM5122MHX/NOPB
U2: TPS259824ONRGER; TI_RGE0024M_TPS25982; MPN TPS259824ONRGER

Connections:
12V_IN: C21.1, C22.1, D3.1 (K), J1.1 (+12V), R22.1, U2.1 (IN), U2.2 (IN), U2.3 (IN), U2.16 (IN), U2.25 (IN)
53V5_RAW: C20.1 (+), F6.1, L2.2, R20.2
BOOST_IN: C2.1, C3.1, C4.1, C19.1 (+), D4.3 (K), R2.1, R3.2, R10.2, R11.2, U2.17 (OUT), U2.18 (OUT), U2.19 (OUT), U2.20 (OUT), U2.21 (OUT), U2.22 (OUT), U2.23 (OUT), U2.24 (OUT)
BOOST_OUT: C5.1, C6.1, C7.1, C8.1, L2.1, Q1.5 (D), Q1.6 (D), Q1.7 (D), Q1.8 (D), R1.2
BST: C9.2, D2.1 (K), U1.20 (BST)
COMP: C17.1, C18.1, U1.11 (COMP)
COMP_RC: C18.2, R17.2
CSN: C10.1, R4.1, U1.3 (CSN)
CSP: C10.2, R3.1, U1.4 (CSP)
EFUSE_DVDT: C23.1, U2.15 (DVDT)
EFUSE_EN: R22.2, R23.1, U2.6 (EN_UVLO)
EFUSE_ILIM: R24.1, U2.8 (ILIM)
EFUSE_IMON: R25.1, U2.9 (IMON)
FB: C17.2, R17.1, R18.2, R19.1, U1.10 (FB)
FB_HIGH: R19.2, R20.1
GATE2: Q2.4 (G), R5.1
GATE3: Q3.4 (G), R21.1
GND: C2.2, C3.2, C4.2, C5.2, C6.2, C7.2, C8.2, C11.1, C13.2, C14.2, C15.2, C16.2, C19.2 (-), C20.2 (-), C21.2, C22.2, C23.2, D3.2 (A), D4.1 (A1), D4.2 (A2), J1.2 (RETURN), J6.3 (RETURN), Q2.1 (S), Q2.2 (S), Q2.3 (S), Q3.1 (S), Q3.2 (S), Q3.3 (S), R8.1, R13.1, R14.1, R16.1, R18.1, R23.2, R24.2, R25.2, U1.9 (AGND), U1.15 (PGND), U1.21 (EP), U2.4 (GND), U2.5 (GND), U2.10 (RETRY_DLY), U2.12 (LDSTRT), U2.14 (GND), U2.26 (GND)
HO: Q1.4 (G), U1.19 (HO)
IC_VIN: C15.1, R11.1, U1.5 (VIN)
LO: R5.2, R21.2, U1.16 (LO)
MODE: R12.1, U1.13 (MODE)
OPT: R8.2, U1.2 (OPT)
RES: C14.1, U1.14 (RES)
RT: R16.2, U1.8 (RT)
SENSE_LOW: L1.1 (IN), R2.2, R4.2
SLOPE: R14.2, U1.12 (SLOPE)
SNUB: C1.1, R1.1
SS: C16.1, U1.7 (SS)
SW: C1.2, C9.1, L1.2 (OUT), Q1.1 (S), Q1.2 (S), Q1.3 (S), Q2.5 (D), Q2.6 (D), Q2.7 (D), Q2.8 (D), Q3.5 (D), Q3.6 (D), Q3.7 (D), Q3.8 (D), U1.18 (SW)
SWITCH_53V5: F6.2, J6.1 (+53V5)
UVLO: C13.1, R10.1, R13.2, U1.6 (UVLO), U2.13 (PG)
VCC: C11.2, D2.2 (A), R12.2, U1.17 (VCC)

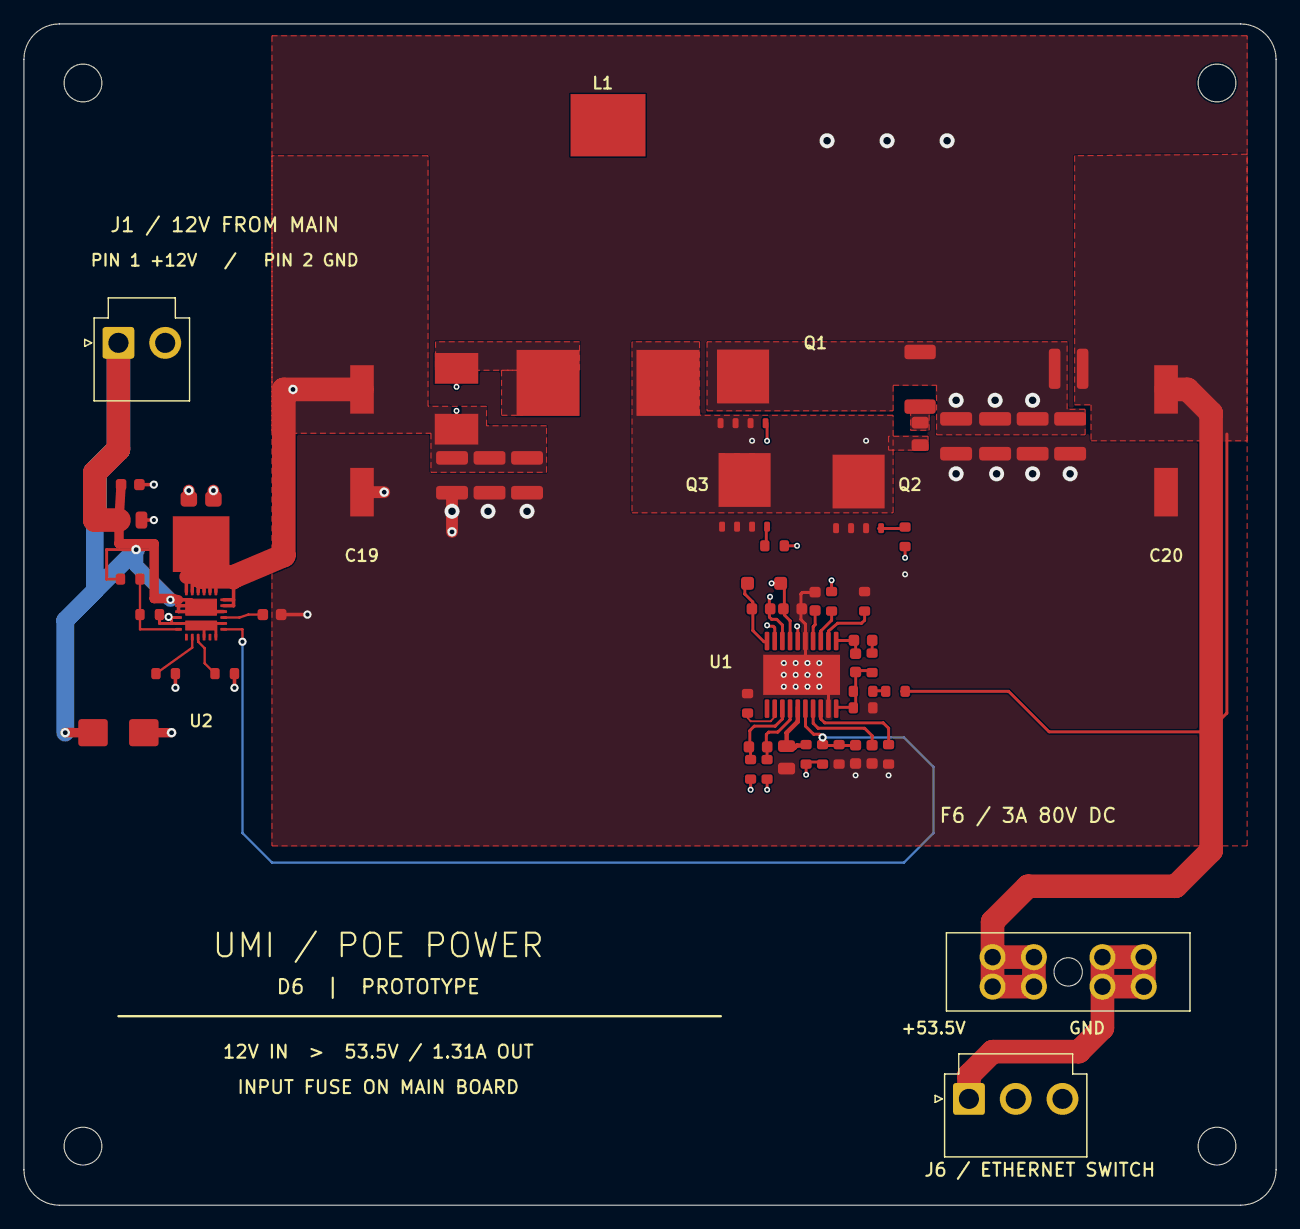
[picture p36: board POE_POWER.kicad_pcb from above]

Board: 4 copper layers, 106.0 x 100.0 mm, 60 parts (0 on the bottom side), 33 nets.

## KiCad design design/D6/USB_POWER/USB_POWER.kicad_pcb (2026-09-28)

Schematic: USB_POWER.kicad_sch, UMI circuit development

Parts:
C1: 10uF 50V X7R; C_1210_3225Metric_R180; MPN CNA6P1X7R1H106KT000A
C2: 10uF 50V X7R; C_1210_3225Metric; MPN CNA6P1X7R1H106KT000A
C3: 47uF 10V X7R; C_1210_3225Metric_R180; MPN GRM32ER71A476ME15L
C4, C5, C8, C11: 100nF 25V; C_0603_1608Metric; MPN GRM188R71E104KA01D
C6, C7: 22uF 10V; C_1206_3216Metric; MPN GRM31CR71A226KE15L
C9, C10, C13, C14: 47uF 10V X7R; C_1210_3225Metric; MPN GRM32ER71A476ME15L
C12: 47uF 25V bulk; CP_Elec_6.3x5.8; MPN EEE-FK1E470P
D1: 12V gate clamp; D_SOD-123; MPN BZT52C12-7-F
H1, H2, H3, H4: M3 MOUNT; MountingHole_3.2mm_M3; MPN MECHANICAL - NO PURCHASE
J1: 12V INPUT; JST_VH_B2P-VH_1x02_P3.96mm_Vertical; MPN B2P-VH(LF)(SN)
J2, J3: USB-A 3A; USB_A_Wurth_614004190021; MPN 614004190021
Q1: AO4407A; SOIC-8_3.9x4.9mm_P1.27mm; MPN AO4407A
R1: 24.9k 0.1%; R_0603_1608Metric_R180; MPN RT0603BRD0724K9L
R2, R3: 32.4k 0.1%; R_0603_1608Metric; MPN RT0603BRD0732K4L
R4, R5, R6, R9: 100k; R_0603_1608Metric; MPN RC0603FR-07100KL
R7: 102k 0.1%; R_0603_1608Metric; MPN RT0603BRD07102KL
R8: 15.8k 1%; R_0603_1608Metric; MPN ERJ-3EKF1582V
U1: TPSM63610RDFR; TI_RDF0022A_TPSM63610; MPN TPSM63610RDFR
U2, U3: TPS2557DRB; VSON-8-1EP_3x3mm_P0.65mm_EP1.65x2.4mm; MPN TPS2557DRBR
U4: TPS2513ADBVR; SOT-23-6; MPN TPS2513ADBVR
U5, U6: USBLC6-2SC6; SOT-23-6; MPN USBLC6-2SC6

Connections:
5V_BUS: C3.1, C4.1, C5.1, C8.1, C9.1, C10.1, C11.1, C13.1, C14.1, R4.1, R5.1, R7.1, R9.1, U1.5 (VLDOIN), U1.9 (VOUT1), U1.10 (VOUT2), U2.2 (IN), U2.3 (IN), U2.4 (EN), U3.2 (IN), U3.3 (IN), U3.4 (EN), U4.5 (IN)
12V_IN: J1.1 (VIN), Q1.5 (D), Q1.6 (D), Q1.7 (D), Q1.8 (D)
12V_PROTECTED: C1.1, C2.1, C12.1 (+), D1.1 (K), Q1.1 (S), Q1.2 (S), Q1.3 (S), U1.1 (VIN1), U1.17 (EN), U1.18 (VIN2)
BOOT: U1.2 (RBOOT), U1.3 (CBOOT)
DM1: J2.2 (D-), U4.6 (DM1), U5.1 (IO1), U5.6 (IO1)
DM2: J3.2 (D-), U4.4 (DM2), U6.1 (IO1), U6.6 (IO1)
DP1: J2.3 (D+), U4.1 (DP1), U5.3 (IO2), U5.4 (IO2)
DP2: J3.3 (D+), U4.3 (DP2), U6.3 (IO2), U6.4 (IO2)
FAULT1: R4.2, U2.8 (FAULT)
FAULT2: R5.2, U3.8 (FAULT)
FB: R1.1, R7.2, U1.8 (FB)
GND: C1.2, C2.2, C3.2, C4.2, C5.2, C6.2, C7.2, C8.2, C9.2, C10.2, C11.2, C12.2 (-), C13.2, C14.2, J1.2 (GND), J2.4 (GND), J2.SH (SHIELD), J3.4 (GND), J3.SH (SHIELD), R1.2, R2.2, R3.2, R6.2, R8.2, U1.7 (AGND), U1.11 (AGND), U1.14 (SPSP), U1.19 (PGND), U1.20 (PGND), U1.21 (AGND), U1.22 (AGND), U2.1 (GND), U2.9 (EP), U3.1 (GND), U3.9 (EP), U4.2 (GND), U5.2 (GND), U6.2 (GND)
ILIM1: R2.1, U2.5 (ILIM)
ILIM2: R3.1, U3.5 (ILIM)
PG: R9.2, U1.13 (PG)
RP_GATE: D1.2 (A), Q1.4 (G), R6.1
RT: R8.1, U1.12 (RT)
VBUS1: C6.1, J2.1 (VBUS), U2.6 (OUT), U2.7 (OUT), U5.5 (VBUS)
VBUS2: C7.1, J3.1 (VBUS), U3.6 (OUT), U3.7 (OUT), U6.5 (VBUS)
VCC: U1.6 (VCC), U1.15 (SYNC_MODE)

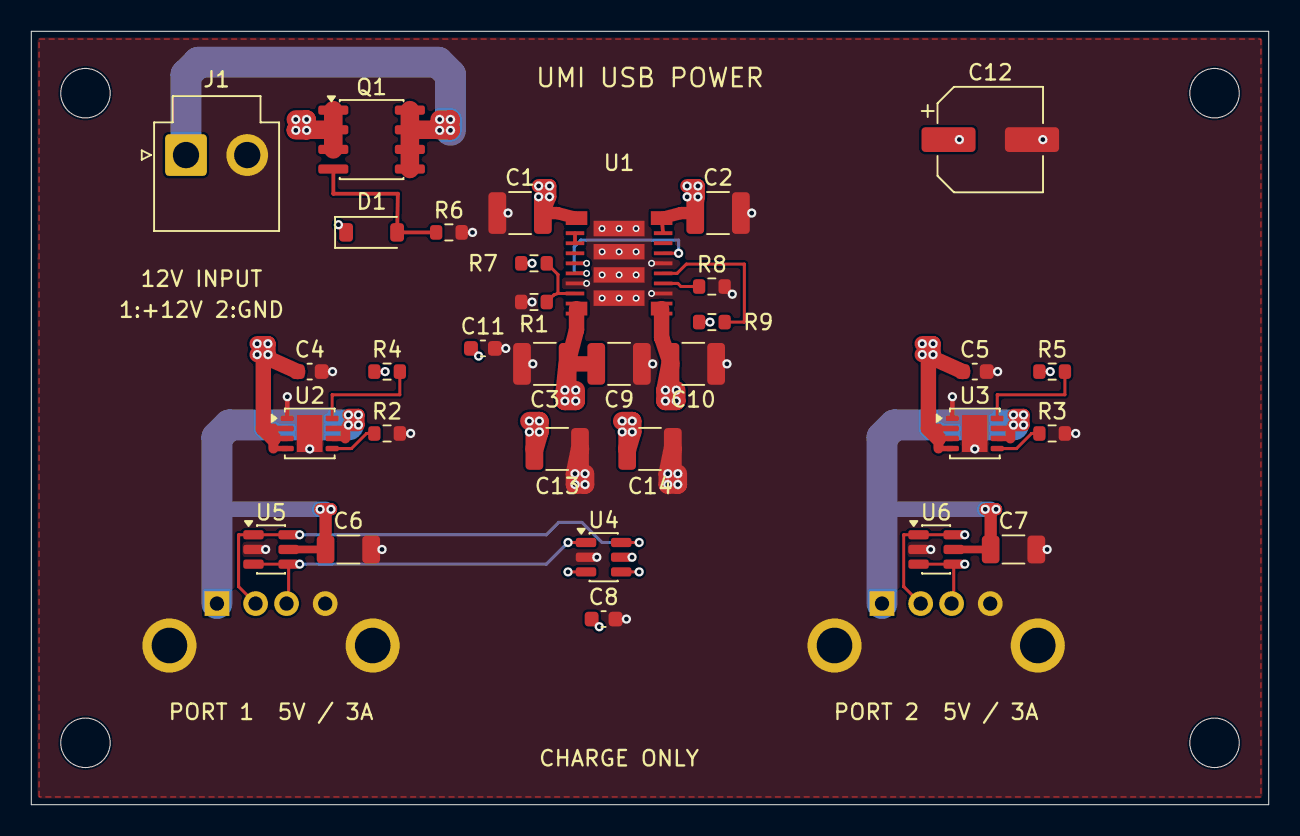
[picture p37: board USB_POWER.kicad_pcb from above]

Board: 4 copper layers, 80.0 x 50.0 mm, 38 parts (0 on the bottom side), 20 nets.

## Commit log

2026-09-28 Import UMI D6 three-board prototype design and engineering handoff
    [BOM_JLC_DRAFT.csv, BOM_by_reference.csv, BOM_grouped.csv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]
2026-09-28 Hold manufacturing outputs pending corrected board outlines
2026-09-29 Redraw MAIN schematic with explicit fused branches and verify D6 parity
    [BOM_JLC_DRAFT.csv, BOM_by_reference.csv, BOM_grouped.csv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]
2026-09-29 Reconnect user MAIN layout with preserved placement and clean DRC
    [BOM_JLC_DRAFT.csv, BOM_by_reference.csv, BOM_grouped.csv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]
2026-09-29 Move all MAIN board silkscreen notes to top side
    [MAIN_POWER.kicad_pcb]
2026-09-29 Add two-layer MAIN prototype preserving user layout
    [BOM_JLC_DRAFT.csv, BOM_by_reference.csv, BOM_grouped.csv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]
2026-09-29 Match FAN branch track width to other MAIN outputs
    [MAIN_POWER-B_Cu.gbl, MAIN_POWER-B_Mask.gbs, MAIN_POWER-B_Silkscreen.gbo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]
2026-09-29 Prepare MAIN D7-2L UK parts list and ten-board fabrication package
    [DIGIKEY_BASKET_IMPORT.csv, MAIN_BOARD_BOM_MANUAL_ASSEMBLY.csv, MAIN_D7_2L_UK_PARTS_10.xlsx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]
2026-09-29 Record prepared JLCPCB and DigiKey carts for ten MAIN boards
2026-09-30 Add D8 MAIN and FASTON input variant
    [10052907_AA-UMI POWER PCB OUTLINE V2.dxf, 10052907_AA-UMI POWER PCB OUTLINE V2_1.dxf, MAIN_POWER.kicad_pcb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]
2026-10-01 Apply MAIN V3 outline and export FASTON STEP
    [10052938_AA-UMI POWER PCB OUTLINE V3.dxf, FASTON_63951-4_PAIR_PROXY.step, MAIN_POWER.kicad_pcb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]
2026-10-01 Fix D8 MAIN models and STEP exports
    [FASTON_63951-4_PAIR_PROXY.step, JST_VH_B2P-VH_ENVELOPE.step, Littelfuse_FLR_1786165_ENVELOPE.step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]
2026-10-01 Fix FASTON tab and fuseholder 3D alignment
    [FASTON_63951-4_PAIR_PROXY.step, Littelfuse_FLR_1786165_BACKSIDE_ENVELOPE.step, MAIN_POWER.kicad_pcb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]
